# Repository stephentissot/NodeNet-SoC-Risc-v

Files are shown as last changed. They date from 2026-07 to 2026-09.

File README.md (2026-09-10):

# NodeNet SoC Risc-v — Colorlight i9 Multi-Node Embedded System

A complete RISC-V System-on-Chip (SoC) design for the Colorlight i9 FPGA board, featuring a PicoRV32 processor, Wishbone bus interconnect, persistent SPI flash storage, I2C peripherals, distributed RS485 multi-node communication via the NodeNet485 protocol, and a PLC runtime ready for relocatable object-file deployment.

## Overview

This project demonstrates a scalable embedded systems design on a cost-effective FPGA:
- **Processor**: PicoRV32 (32-bit RISC-V, bare-metal)
- **Clock**: 25 MHz
- **Memory**: 64 KiB ROM (stage0 bootloader) + 64 KiB RAM (stack/variables) + 8 MB SDRAM (runtime application/external data)
- **Peripherals**: D2 LED GPIO, RJ45 LED pulse controllers (`wb_led`), UART1 Modbus RTU master (`wb_modbus_master`), RS485 NodeNet485, I2C master, SDRAM controller
- **Communication**: NodeNet485 @ 1 Mb/s over RS-485 (multi-node capable)
- **Firmware**: C++17, bare-metal, newlib-nano
- **Validated boot path**: stage0 in ROM validates an image header in SPI flash, copies the payload to SDRAM, checks CRC, then jumps to the application entry point
- **Validated SDRAM path**: full firmware execution from SDRAM, 32-bit accesses, partial Wishbone writes, linker-placed `SDRAM_DATA` variables, and scratch-area self-tests

Current project status:
- **PLC Ready** with **V0 basic ISA**
- runtime point catalog with `pointDefsReq` / `pointStatesReq` browsing and pagination
- relocatable `objectFileV1` PLC upload, firmware-side link/load, linked-bytecode readback, and object-file readback
- 16 PLC slots with reboot persistence in the raw PLC flash package and automatic restore after boot
- OLED boot progress screen plus post-boot slot status screen
- ESP32 SPI coprocessor for local web API is in progress on the current branch; the shared SPI link, snapshot bootstrap, incremental state updates, and web UI runtime path are now working together on hardware, while broader validation and the MQTT bridge remain pending

## Features

### NodeNet PLC
- NodeNet PLC catalog browsing supports `pointDefsReq` and `pointStatesReq` with hierarchical paths of the form `deviceId.feature.pointId`.
- Point definitions can be created or updated with `pointUpsert`, and removed with `pointDelete`.
- Modbus-backed points are polled by the PLC runtime and exposed through the same NodeNet command surface.
- The PLC runtime publishes a shared SDRAM descriptor/value/status map, and PLC VM writes are consumed through the runtime write queue.
- Generic PLC deployment uses relocatable `objectFileV1` artifacts; the built-in `plcLoadReq` mirror helper remains available for fast validation.

PLC feature summary:
- Main feature status: PLC Ready with V0 basic ISA
- Runtime architecture: shared SDRAM PLC ABI, point runtime descriptors, value/status windows, slot loader/linker, persistent flash package restore at boot
- Deployment model: host builds relocatable `objectFileV1`, firmware links it against the live point catalog, loads it into one of 16 slots, and can persist the slot set for reboot restore
- Operating surface: NodeNet browse/update commands for point definitions and point states, PLC slot control/status points, raw PLC upload flow, linked-bytecode readback, and original object-file readback

PLC documentation index:
- Command surface and JSON examples: [README_NODENET_PLC_COMMANDS.md](README_NODENET_PLC_COMMANDS.md)
- PLC VM runtime architecture and ABI: [Documentation/plc_vm_spec_v1.md](Documentation/plc_vm_spec_v1.md)
- PLC assembly / object-file format: [Documentation/plc_assembly_spec_v1.md](Documentation/plc_assembly_spec_v1.md)
- ESP32 SPI bridge pinout and PlatformIO notes: [Documentation/esp32_spi_bridge_notes.md](Documentation/esp32_spi_bridge_notes.md)
- Firmware runtime and flash layout: [src/firmware/README.md](src/firmware/README.md)
- Stage0 boot flow and runtime handoff: [src/firmware/README_BOOT.md](src/firmware/README_BOOT.md)
- NodeNet transport details: [src/wbDevices/README_NODENET.md](src/wbDevices/README_NODENET.md)
- SPI flash persistence details: [src/wbDevices/README_FLASH.md](src/wbDevices/README_FLASH.md)
- Desktop PLC object-file tooling: [tools/BigSisterNodeNet.Plc/README.md](tools/BigSisterNodeNet.Plc/README.md)

### NodeNet Validation Snapshot (2026-08-20)
- Automatic heartbeat in HDL validated on hardware at ~10 s period.
- RX to local address validated (message accepted and decoded).
- TX path validated end-to-end.
- Runtime baud operation validated at both 115200 and 1 Mb/s.
- RX metadata is propagated end-to-end (`src`, `dst`, `broadcast`, `len`).
- Distinct PicoRV32 IRQs exist for broadcast vs unicast RX and are consumed through firmware callbacks.
- ROM stage0 now forwards the fixed IRQ vector at `0x00000004` to the SDRAM app IRQ entry.

### FlashDB Validation Snapshot (2026-08-13)
- Flash low-level test passes at boot (`[FLASH] LowLevel PASS`).
- FlashDB initialization passes (`[FDB] Ready`).
- Boot counter write path passes (`[FDB] boot cnt updated`).

### Hardware
- **Wishbone B.4 Bus** interconnect with 32-bit data, 32-bit address
- **PicoRV32 Core**: Open-source RISC-V ISA, ~6K LUT footprint
- **Memory Map**:
  - `0x00000000–0x0000FFFF`: 64 KiB boot ROM (stage0 bootloader)
  - `0x00010000–0x0001FFFF`: 64 KiB RAM (stack, BSS, heap)
  - `0x10000000`: D2 LED GPIO (1-bit output)
  - `0x10000004`: RJ45 LED0 (`wb_led` one-shot pulse)
  - `0x10000008`: RJ45 LED1 (`wb_led` one-shot pulse)
  - `0x10004000`: UART1 Modbus RTU master (`wb_modbus_master`)
  - `0x10005000`: I2C0 master (8 registers @ 4-byte stride)
  - `0x10006000`: NodeNet485 RS-485 mailbox (8 registers, 1 Mb/s)
  - `0x20000000–0x207FFFFF`: 8 MB SDRAM (runtime application image / framebuffer / logs)

### Peripherals
- **NodeNet485 Module** (`wb_nodenet.sv`):
  - Multi-node RS-485 communication protocol
  - Baud rate: runtime divisor (validated at 115200 and 1 Mb/s)
  - HDLC-style framing with parity bits and CRC
  - Mailbox-based Wishbone interface for TX/RX messages
  - Internal message buffering (no external SDRAM FIFO usage)
  - Anti-collision backoff (address-based delay)
  - Periodic heartbeat for node discovery
  - Priority-based transmission (LOW/NORMAL/HIGH)
  - Full C++ firmware API in `src/firmware/lib/nodenet/nodenet.h`
  - Supports unicast, broadcast, and heartbeat messages
  - Supports callback-driven broadcast / unicast reception on PicoRV32 IRQs
  - RX decode error reporting and TX scheduling status
  - Wishbone register interface (0x10006000)

- **I2C Module** (`wb_i2c.sv`):
  - Wraps Alex Forencich's `i2c_master_wbs_16` core
  - Hardware command + write + read FIFOs (32 entries each)
  - Configurable speed (default 100 kHz, up to 400 kHz @ 25 MHz)
  - Drives SCL/SDA open-drain (external 4.7 kΩ pullup required)
  - Wishbone address: 0x10005000

- **Modbus Master Module** (`src/modbus/wb_modbus_master.sv`):
  - Wishbone Modbus RTU master transaction engine
  - Uses shared `uart_simple.sv` UART core for wire-level TX/RX
  - Hardware-managed CRC16 (TX generation + RX validation)
  - Hardware-managed RTU frame gap detection (inter-frame silence)
  - Retries, timeout, and status/error flags exposed through MMIO
  - Firmware API in `src/firmware/lib/modbus/ModbusMaster.{h,cpp}`
  - Wishbone address: 0x10004000

- **SPI Flash Module** (`wb_flash.sv`, `spi_master.sv`):
  - Wishbone interface to on-board SPI flash (W25Q64, 8 MB)
  - Memory layout: 2 MB boot config (protected) + 12 KB point catalog + 4 KB compatibility gap + 128 KB PLC package + 124 KB FlashDB KV + 4 KB self-test scratch + app data
  - C++ firmware uses low-level page/sector API (`Flash`) plus FlashDB wrapper (`flashdb_port`)
  - Exposes the factory-programmed 64-bit Winbond UID as a stable ASCII device ID
  - Boot region protection: firmware rejects writes/erases to 0x000000–0x1FFFFF
  - Point catalog storage at 0x200000–0x202FFF (12 KB, 3 sectors)
  - Compatibility gap at 0x203000–0x203FFF (4 KB)
  - Persistent PLC package at 0x204000–0x223FFF (128 KB)
  - FlashDB KV partition at 0x224000–0x242FFF (124 KB)
  - Flash low-level self-test scratch at 0x243000–0x243FFF (4 KB)
  - Wishbone address: 0x10007000
  - See [src/wbDevices/README_FLASH.md](src/wbDevices/README_FLASH.md) for details
### Firmware
- **C++17 bare-metal** (`firmware/main.cpp`):
  - Compiled with `riscv-none-elf-g++` — no Arduino, no OS
  - `newlib-nano` provides `memcpy`/`strlen`/etc.
  - Dead code elimination (`-ffunction-sections -Wl,--gc-sections`)
  - Global C++ constructors called in `start.S` via `.init_array`
  - Final runtime image is linked for SDRAM via `link_app_sdram.ld`
  - Loaded by ROM-resident `boot_stage0` from SPI flash offset `0x244000`
  - Includes ArduinoJson 7 in freestanding mode, with an optional SDRAM-backed allocator for large JSON payloads
  - **NodeNet485 callback flow**: receives broadcast/unicast events through IRQ callbacks and defers heavy work to the main loop
  - D2 activity heartbeat: non-blocking software toggle every 500 ms

- **External SDRAM bring-up**:
  - Cold boot initialization now follows the generated LiteDRAM DFII sequence before the SDRAM user port is released
  - Firmware should still call `sdram_wait_ready()` before touching `SDRAM_DATA` objects or the JSON SDRAM pool

- See [src/firmware/README.md](src/firmware/README.md) for full peripheral usage guide.
- See [src/wbDevices/README_NODENET.md](src/wbDevices/README_NODENET.md) for protocol details.
- See [src/modbus/README.md](src/modbus/README.md) for Modbus RTU master details.
- See [src/wbDevices/README_FLASH.md](src/wbDevices/README_FLASH.md) for flash UID and device ID details.

## Building

### Prerequisites
- Yosys (synthesis)
- NextPNR (place & route)
- ecppack (bitstream generation)
- RISC-V GCC toolchain (`riscv-none-elf-gcc` ≥ 12, with C++ support)
- Make

> **After cloning**, fetch the u8g2 submodule:
> ```bash
> git submodule update --init
> ```

### Build Steps

```bash
# Full build (firmware + FPGA)
make all

# Stage0 bootloader only (ROM image)
make firmware-bootloader

# Alias: same stage0 ROM build as above
make firmware-build

# Build stage0 application image (SDRAM payload + header in SPI flash format)
make firmware-image

# SDRAM application ELF only
make -C src/firmware firmware-app-build

# Program firmware payload only in SPI flash (no FPGA rebuild)
make flash-fw

# If bootloader ROM startup / IRQ forwarding changed, reload the FPGA image too
make ram

# Optional: enforce openFPGALoader verify as fatal
make FW_STRICT_VERIFY=1 flash-fw

# Generate boot robustness test images (missing/size/crc fault injections)
make firmware-image-tests

# Run boot robustness fault scenarios
make flash-fw-test-missing
make flash-fw-test-crc
make flash-fw-test-size

# Firmware-only FPGA RAM update (ecpbram patch, fallback to make ram if needed)
make ram-fw

# Boot fault campaign checklist and expected blink codes
# See TEST.md

# FPGA synthesis only (requires pre-built firmware)
make

# Clean all artifacts
make clean

# Program FPGA SRAM (volatile)
make ram

# Program SPI flash (persistent, includes unlock during write)
make flash

# Manual flash protection control
make unlock-flash
make lock-flash
```

`make firmware-build` / `make firmware-bootloader` print stage0 ROM size telemetry on each build:
- ELF text/data/bss
- RAM usage (`.data + .bss`)
- HEX file size and payload bytes
- ROM usage (`payload / ROM_BYTES`, in %)

If payload exceeds ROM capacity, build stops with an explicit error.

CPU profile note:
- Default build is configured in fast mode for PicoRV32 in [src/top.sv](src/top.sv) with:
  - `.BARREL_SHIFTER(1)`
  - `.ENABLE_FAST_MUL(1)`
  - `.ENABLE_DIV(1)`
- To switch back to the normal/smaller CPU profile, set those three parameters to `0` in [src/top.sv](src/top.sv) and rebuild (`make clean; make`).

If OpenOCD flash programming fails on your setup, you can switch the flash
targets in `Makefile` to ecpdap. Reference commands:

```make
# ecpdap fallback examples (Colorlight i5/i9 style headers)
# flash:
# 	ecpdap flash unprotect
# 	ecpdap flash write build/top.config
#
# unlock-flash:
# 	ecpdap flash unprotect
#
# lock-flash:
# 	ecpdap flash protect
```

**Output**:
- `src/firmware/build/boot_stage0.hex` – Stage0 bootloader image (loaded into ROM, includes IRQ forward stub to the SDRAM app)
- `src/firmware/build/nodenet_riscv_app.img` – SDRAM app payload with stage0 header (written in SPI flash at `0x244000`)
- `build/top.bit` – FPGA bitstream (~300 KB)
- `build/top.json` – Netlist (debug/inspection)

## Memory Layout

```
Address Range               Size      Purpose
────────────────────────────────────────────────────────────
0x00000000–0x0000FFFF     64 KiB   Boot ROM (stage0 bootloader)
0x00010000–0x0001FFFF     64 KiB   RAM (stack, BSS, heap)
────────────────────────────────────────────────────────────
0x10000000                4 B      D2 LED GPIO (bit [0] = LED output)
0x10000004                4 B      RJ45 LED0 (`wb_led` control/status)
0x10000008                4 B      RJ45 LED1 (`wb_led` control/status)
0x10004000                32 B     UART1 Modbus RTU master (`wb_modbus_master`)
0x10005000                32 B     I2C0 master (8 regs @ 4-byte stride)
0x10006000–0x1000601F     32 B     NodeNet485 mailbox + LED config (RS485, 1 Mb/s)
0x10007000                32 B     SPI Flash controller (W25Q64)
────────────────────────────────────────────────────────────
0x20000000–0x207FFFFF     8 MB     SDRAM — Runtime app image + large buffers/logs
────────────────────────────────────────────────────────────
0x00000000–0x1FFFFF       2 MB     SPI Flash — FPGA boot config (PROTECTED)
0x200000-0x202FFF         12 KB    SPI Flash — Point catalog
0x203000-0x203FFF         4 KB     SPI Flash — Compatibility gap / reserved
0x204000-0x223FFF         128 KB   SPI Flash — Persistent PLC package
0x224000-0x242FFF         124 KB   SPI Flash — FlashDB KV partition
0x243000-0x243FFF         4 KB     SPI Flash — Flash low-level self-test scratch
0x244000–0x7FFFFF         5.73 MB  SPI Flash — Stage0 application image slot
```

## Boot Flow

1. FPGA configuration loads the SoC bitstream and the `wb_rom` contents containing `boot_stage0`.
2. Stage0 starts from `0x00000000`, initializes required peripherals, and reads the application header from SPI flash offset `0x244000`.
3. Stage0 validates header fields and CRCs, copies the application payload into SDRAM at `0x20000000`, then jumps to the image entry point.
4. PicoRV32 IRQ entry remains fixed at `0x00000004`; the ROM image forwards that vector to the SDRAM application IRQ entry at `0x20000004`.
5. The runtime firmware executes entirely from SDRAM, while SPI flash remains available for parameter storage, FlashDB, and firmware updates.
6. SDRAM self-tests used by the runtime stay inside a reserved scratch area so they do not overwrite the executing image.

## Device Pinout

### RS485 (NodeNet485 Protocol)
- **Pins**: G5 (RX), D16 (TX)
- **Baud Rate**: 1 Mb/s (fixed, configurable via UART parameter)
- **Protocol**: Multi-node RS-485 with HDLC framing, anti-collision, heartbeat
- **Transceiver**: Any RS-485 module with auto-switching (MAX485, SN65HVD11, etc.)
- **Multi-Node**: Up to 20 nodes on shared bus with address-based scheduling
- **Features**: Parity-encoded payload (2x expansion), XOR CRC, priority levels (LOW/NORMAL/HIGH), heartbeat
- **Connector topology**: 2x RJ45 in daisy-chain (IN/OUT), wired pin-to-pin between connectors

NodeNet RJ45 pinout (both connectors):

| RJ45 Pin | Signal |
|---|---|
| 1 | +12V |
| 2 | +12V |
| 3 | RS485 A |
| 4 | GND |
| 5 | GND |
| 6 | RS485 B |
| 7 | GND |
| 8 | GND |

### I2C (D18/D17 pins)
- **SCL**: D18
- **SDA**: D17
- Requires external 4.7 kΩ pullup resistors to 3.3 V on both lines
- Compatible with any I2C device: OLED, sensors, ADC, GPIO expanders…

### GPIO
- **D2 LED**: GPIO output at 0x10000000 (bit [0] = LED state)

### RJ45 LEDs (`wb_led`)
- **LED0 (F5)**: `0x10000004`
- **LED1 (E6)**: `0x10000008`
- Active-low wiring policy: GPIO high = LED OFF, GPIO low = LED ON.
- LPF enables pull-up on these pins for deterministic OFF level during startup.
- Write command bit0 triggers a non-blocking pulse (duration can be overridden by firmware).
- RJ45 LEDs are available through `wb_led` and can be used by application firmware when needed.

### NodeNet Activity LEDs (100% hardware)
- **RX activity LED (E5, green)**: default ON, pulses OFF when a valid frame is received.
- **TX activity LED (F4, orange)**: pulses ON when a transmission is queued.
- Active-low with pull-up: idle/high keeps LED OFF unless logic drives low.
- Blink duration is configured by firmware through NodeNet register `0x1000601C` (milliseconds).

### SPI Flash (W25Q64)
- **Pins**: R2 (CS), W2 (MOSI), V2 (MISO)
- **Clock**: Generated internally (10 MHz typical, no GPIO pin)
- **Capacity**: 8 MB (2 MB boot + 16 KB params + 256 KB FlashDB KV + ~5.73 MB app)
- **Boot Protection**: Firmware API rejects writes to 0x000000–0x1FFFFF
- **Parameter Region**: 0x200000–0x203FFF (raw/scratch area)
- **FlashDB KV Region**: 0x204000–0x243FFF (`nodenet_kv` partition)

## Firmware Examples

See **[src/firmware/README.md](src/firmware/README.md)** for a full guide with code examples for every peripheral.

### Quick-start: UART1 Modbus RTU master
```cpp
#include "ModbusMaster.h"

constexpr uint32_t MODBUS1_BASE = 0x10004000u;
constexpr uint8_t MODBUS_SLAVE = 0x01u;
ModbusMaster modbus1(MODBUS1_BASE);

int main() {
  modbus1.begin(9600, 500, 2);
  modbus1.setInterframeCharsQ1(14);

  uint16_t version = 0;
  if (modbus1.readHoldingRegisters(MODBUS_SLAVE, 0x8000, 1, &version)) {
    // 0x0064 => V1.00
  }

  for (;;) {
    // Toggle channel 1 (coil address 0)
    (void)modbus1.writeSingleCoil(MODBUS_SLAVE, 0x0000, true);
  }
}
```

### Quick-start: NodeNet echo
```cpp
#include <stdint.h>
#include "nodenet.h"

#define LED          (*(volatile uint32_t*)0x10000000)
constexpr uint32_t NODENET0_BASE = 0x10006000u;

int main() {
  NodeNet myNodeNet(NODENET0_BASE, 0x01, NODENET_PRIORITY_NORMAL, 200);
  for (;;) {
    if (myNodeNet.HasMessage()) {
      NodeNetMessage msg = myNodeNet.ReadMessage();
      if (msg.src_addr != 0) {
        myNodeNet.Send(msg.src_addr, msg.data, msg.len);
      }
      NodeNet::FreeMessage(msg);
    }
    LED ^= 1;
  }
}
```

### Quick-start: OLED via u8g2
```cpp
#include "u8g2_hal.h"

u8g2_t display;

int main() {
    u8g2_Setup_ssd1306_i2c_128x64_noname_f(
        &display, U8G2_R0,
        u8x8_byte_i2c_hw,
        u8x8_gpio_delay_hw);
    u8g2_InitDisplay(&display);
    u8g2_SetPowerSave(&display, 0);
    u8g2_ClearBuffer(&display);
    u8g2_SetFont(&display, u8g2_font_ncenB08_tr);
    u8g2_DrawStr(&display, 0, 12, "RISC-V SoC");
    u8g2_SendBuffer(&display);
    for (;;);
}
```

## Wishbone Bus Modules

See [src/wbDevices/README.md](src/wbDevices/README.md) for detailed documentation of each Wishbone peripheral module.

## Resource Usage

**Lattice LFE5U-45F-6BG381C** (Colorlight i9):
- Total LUTs: 45K
- Block RAM (DP16KD): 108 (each 16K bits)
- Current design:
  - PicoRV32: ~6K LUT
  - Interconnect: ~1K LUT
  - ROM (64 KiB): 32 blocks
  - RAM (64 KiB): 32 blocks
  - NodeNet485 transport + UART: ~300 LUT
  - SDRAM controller: ~400 LUT
  - GPIO: ~50 LUT
  - **Total: ~35% of available resources**

## Architecture

```
                   +----------------+
                   |   PicoRV32     |
                   +-------+--------+
                           |
                      Wishbone B4
                           |
      +--------+-----------+---------+--------+----------+-------+
      |        |           |         |        |          |       |
      wb_rom  wb_ram  wb_modbus_master  wb_nodenet wb_gpio wb_led wb_sdram wb_i2c
            |         |
            uart_simple  uart_simple
                 |
               NodeNet framing
        LED D2   RJ45 LEDs   M12L64322A  SSD1306   W25Q64
              |                    (8MB SDRAM) OLED
            RS485 Transceiver
                           |
                 Direct RS485 A/B/GND
                           |
                   Field Connectors
```

**Data Flow**:
1. **Power-up / stage0**: `wb_rom` exposes the 64 KiB ROM image containing `boot_stage0`, which loads and validates the SDRAM application stored in SPI flash.
2. **Runtime CPU** (PicoRV32): 32-bit RISC-V, 25 MHz clock, executing the main firmware from SDRAM after stage0 handoff.
3. **Wishbone B.4 Bus**: 32-bit address, 32-bit data, address decoder for memories and peripherals.
4. **Memory & I/O**:
  - `wb_rom`: 64 KiB boot ROM for stage0 only (0x00000000)
   - `wb_ram`: 64 KiB RAM (0x00010000)
  - `wb_sdram_litedram`: 8 MB SDRAM runtime memory window (0x20000000)
  - `wb_flash`: SPI flash control + persistence services (0x10007000)
  - `wb_modbus_master`: Modbus RTU master transport (0x10004000)
  - `wb_nodenet`: NodeNet485 mailbox transport (0x10006000)
  - `wb_gpio`: D2 GPIO output (0x10000000)
  - `wb_led`: RJ45 LED pulse controllers (0x10000004 / 0x10000008)
   - `wb_i2c`: I2C master with FIFOs (0x10005000)
5. **NodeNet Transport**: Mailbox-driven TX/RX framing, decode, and heartbeat scheduling.
6. **I2C Core**: Wraps Alex Forencich's `i2c_master_wbs_16` with Wishbone interface.
7. **RS485 Physical**: Transceiver converts CMOS <-> RS485 differential signaling.
8. **Field Wiring**: Each RS485 channel is exposed as direct A/B/GND connections.

## Planned Enhancements

- [x] 8 MB SDRAM controller (`wb_sdram_litedram.sv`) with LiteDRAM-generated core and runtime execution from SDRAM
- [x] I2C master (`wb_i2c.sv`) — Wishbone wrapper around verilog-i2c
- [x] u8g2 OLED display support (SSD1306 128×64 over I2C)
- [x] C++17 firmware with newlib-nano and dead-code elimination
- [x] SDRAM section in linker script (`sdram.h`, `SDRAM_DATA` macro)
- [ ] NodeNet485 mailbox transport with TX/RX framing and heartbeat (validation pending)
- [ ] UART1–4 implementation and testing
- [ ] RS485 direct connector mapping and labeling verification (A/B/GND)
- [ ] `wb_gpio` control bit for RS485 120R termination switch (74LVC1G66GW,125)
- [ ] Modbus V1 front-end: 4x RS485 modules with direct A/B/GND connectors per channel
- [ ] `wb_gpiopwm` peripheral + firmware API (PKLCS1212E4001-R1 buzzer)
- [ ] TMP117 board temperature sensor + firmware I2C driver/API
- [ ] Display validation: OLED over I2C and LCD over SPI (select final path after tests)
- [ ] Evaluate and select more robust 1 Mb/s transceivers for Modbus and NodeNet
- [ ] Dual Ethernet breakout using i9 onboard Broadcom PHYs (2x RJ45 with magnetics)
- [x] RJ45 LEDs integrated through `wb_led` at dedicated addresses
- [ ] Final RJ45 firmware policy (link/activity/status) for production runtime
- [ ] ESP32 module SPI coprocessor for web API and MQTT bridge (in progress: shared SPI link, HTTP app, websocket updates, and plcLink snapshot/resync path validated on hardware; MQTT bridge still pending)
- [ ] Power option study: use ESP32 module 3.3V rail vs dedicated 12V->3.3V buck
- [x] Modbus RTU master module + firmware driver (`wb_modbus_master` + `ModbusMaster`)
- [ ] Modbus RTU slave mode
- [ ] NodeNet JSON protocol wrapper (UART4)
- [ ] SPI slave interface for ESP32 co-processor
- [ ] SPI color LCD support (ST7789, 76x284) on Colorlight i9
- [ ] KNX integration with NCN5120 transceiver module
- [ ] Hardware-based CRC accelerator
- [ ] Real-time interrupt controller (RISC-V PLIC)

## Hardware Requirements

- **Colorlight i9 Board** with Lattice LFE5U-45F FPGA
- **USB-C Programmer** (e.g., openFPGALoader, oss-cad-suite)
- **RS485 Transceiver** modules (SN65HVD230, MAX483, etc.)
- **RS485 Field Connectors** (A/B/GND per channel)
- **SSD1306 OLED Module** (I2C, 128×32 or 128×64) + 4.7 kΩ pullup resistors

## Testing

```bash
# Program RAM (requires openFPGALoader)
make ram

# Program Flash (permanent)
make flash

# Explicit flash protection control (optional)
make unlock-flash
make lock-flash

# UART loopback test
# - Send "Hello" via USB-to-UART adapter
# - LED should blink
# - Characters echoed back
```

`make flash` now performs an explicit unlock step in the OpenOCD write command (`flash write_image erase unlock ...`) before erase/program.
`make lock-flash`/`make unlock-flash` call `flash protect ...` through OpenOCD; effectiveness/persistence depends on driver support for the target flash path.

## References

- [PicoRV32 GitHub](https://github.com/YosysHQ/picorv32)
- [Verilog UART IP (Alex Forencich)](https://github.com/alexforencich/verilog-uart) – Core UART module used in wb_uart.sv
- [Verilog I2C IP (Alex Forencich)](https://github.com/alexforencich/verilog-i2c) – Core I2C module used in wb_i2c.sv
- [u8g2 Graphics Library](https://github.com/olikraus/u8g2) – OLED display driver (git submodule)
- [Wishbone B.4 Specification](https://cdn.opencores.org/downloads/wbspec_b4.pdf)
- [LFE5U FPGA Datasheet](https://www.latticesemi.com/en/Products/FPGAs/ECP5)
- [RISC-V Unprivileged ISA Manual](https://riscv.org/specifications/)

## License

See [LICENSE](LICENSE) file.

## Author

**Stephen Tissot**  
Industrial IoT / FPGA Engineering  
https://github.com/stephentissot

---

**Status**: Prototype / Active Development  
**Last Updated**: 2026-08-18

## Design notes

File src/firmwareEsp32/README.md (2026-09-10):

# ESP32 Firmware

This directory contains the ESP32 sidecar firmware used for:

- web-based configuration
- MQTT publication
- Home Assistant discovery
- SPI transport toward the FPGA mailbox bridge

## Selected Stack

- IDE: VS Code
- build system: PlatformIO
- framework: ESP-IDF
- board id: `wemos_d1_mini32`

## Web Transport Policy

- current target: stay on `HTTP` with the current `wemos_d1_mini32` hardware
- reason: this keeps RAM risk lower while the main runtime, UI, and web application bricks are still being integrated
- planned evolution: if the project later moves to an `ESP32-S3 N16R8`, the intended next step is to keep the setup portal on `HTTP` and move the main web application only to `HTTPS`
- certificate direction for that future `HTTPS` app path: allow uploading a server certificate and private key rather than hard-coding a single certificate into the firmware
- decision gate: continue advancing the application on the current board first, then re-evaluate the `ESP32-S3 N16R8` migration once the main features are in place

## Current Scope

The current branch now brings up:

- boot logging on UART
- ST7789 bring-up through a direct ESP-IDF SPI driver using the validated panel wiring and init sequence
- a one-shot ST7789 full-screen red / green / blue test at boot
- FPGA SPI-link initialization on the same shared SPI bus
- HTTP web application served locally by the ESP32
- websocket push path for boot progress, snapshot availability, and incremental PLC point updates
- plcLink bootstrapping with `get_caps`, definitions snapshot, states snapshot, and runtime state-update handling on hardware

## Current Status Snapshot

- current baseline is usable enough to pause and resume later: the ESP32 app can connect to the FPGA mailbox bridge, load the PLC snapshot, keep the page stable during runtime state-only resyncs, and apply incremental point updates without replaying the whole snapshot over websocket
- the shared SPI bus is validated with the display at `10 MHz` and the FPGA mailbox link at `1 MHz`
- definitions are preserved across state-only runtime resyncs when `defs_generation` is unchanged
- the web application no longer treats a runtime state resync as a cold boot reload
- completed state snapshots no longer emit one websocket `plc_point_update` per cached point
- MQTT publication and Home Assistant discovery are still not implemented on this baseline

## Known Resume Points

- continue hardware/runtime validation of plcLink under heavier PLC state churn; the recent work stabilized the ESP32 side, but more soak testing is still needed
- the remaining protocol risk is on the Pico/FPGA producer side when the PLC VM generates many closely spaced state changes
- if runtime resync behavior regresses, inspect `src/spi_link.cpp`, `www/app/main.js`, `src/firmware/lib/spi_mailbox/plclink_mailbox_service.cpp`, and `src/firmware/lib/plc/PointCatalog.cpp` first
- MQTT bridge, Home Assistant discovery, and any HTTPS migration are future steps, not part of the currently validated baseline

## Display Driver

- implementation: local ESP-IDF SPI driver in `src/display_st7789.cpp`
- panel model: `ST7789`
- current bring-up test: one-shot full-screen red / green / blue fills at boot
- note: the init sequence remains aligned with the working `76x284` ST7789 bring-up that was validated during the Arduino reference phase
- bus speed: `10 MHz` for the display device on the shared bus

## UI Library Direction

- recommended library: `LVGL`
- reason: it fits the current pure `ESP-IDF` stack well and expects exactly the kind of flush callback that `display_st7789.cpp` can provide
- keep the current ST7789 driver as the low-level panel backend; do not replace it with a framework-specific display wrapper
- avoid `TFT_eSPI` here: it is more display-driver oriented than UI-oriented and would pull the project back toward the Arduino path we intentionally removed
- next integration step: add a small `lvgl_port` that allocates one or two partial RGB565 draw buffers and forwards `flush_cb` rectangles into `display_st7789::blit_rgb565()`

## Shared SPI Bus

- bus init: shared once through `src/spi_bus_shared.cpp`
- display device: `GPIO5` chip select, SPI mode `3`, `10 MHz`
- FPGA device: `GPIO27` chip select, SPI mode `0`, `1 MHz`
- note: the ESP32 can switch speed per SPI device even when `SCK/MOSI/MISO` are physically shared

## Expected Commands

From this directory:

```powershell
pio run
pio run -t upload
pio device monitor
```

## Wiring Summary

- Shared SPI bus
	- `GPIO18` -> FPGA `J16` and ST7789 `SCL` for `SCK`
	- `GPIO23` -> FPGA `J18` and ST7789 `SDA` for `MOSI`
- FPGA link
	- `GPIO19` <- FPGA `P16` for `MISO`
	- `GPIO27` -> FPGA `N4` for `CS`
	- `GPIO32` <- FPGA `M3` for `IRQ`
- ST7789 control
	- `GPIO5` -> ST7789 `CS`
	- `GPIO16` -> ST7789 `DC`
	- `GPIO17` -> ST7789 `RST`
	- `BL` tied to `GND` and not software-controlled
- Reserved sideband
	- `GPIO33` <-> FPGA `T3` kept reserved for a future FPGA sideband signal

`GPIO33` is a good candidate for a future display `TE` input if you dedicate it to the display.
Do not share that same wire between the FPGA reserved sideband and the display reset or tearing signal.

The current bring-up build is now back on pure ESP-IDF with the FPGA link reattached on the shared SPI bus, and the FPGA mailbox transaction path is working on hardware for snapshot load plus runtime updates.
The next step is broader validation on this baseline, then raising the FPGA-side SPI speed if the slave logic and signal integrity allow it.

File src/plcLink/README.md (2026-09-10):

# plcLink Protocol Specification

This directory defines the future binary application protocol shared between the
PicoRV32 firmware and the ESP32 firmware.

The primary goal is to move point definitions and point states efficiently
between both firmwares with minimal CPU cost on the PicoRV32 side, while keeping
the architecture transport-independent so the same payloads can later travel
over NodeNet as well as SPI.

## Goals

- keep the high-frequency state path binary and compact
- avoid JSON on the local ESP32 <-> FPGA <-> PicoRV32 link
- minimize PicoRV32 work for frequent state propagation
- support full snapshot and incremental update flows for both definitions and states
- support ESP32-initiated writes for both definitions and states
- keep the protocol independent from the underlying transport
- preserve the option to reuse the same protocol payload over NodeNet in V2
- avoid forcing large RTL growth in the first implementation

## Non-Goals

- this protocol does not expose raw SPI mailbox details to application code
- this protocol does not reuse internal firmware structs as wire format by memcpy
- this protocol does not require JSON parsing on the transport path
- this protocol does not require direct SDRAM master access from `wb_spi_slave`
- this protocol does not require NodeNet framing in V1

## High-Level Architecture

The architecture is split into three layers.

### 1. Application Protocol Layer

This layer defines message types and binary payload formats only.

It must not depend on:

- SPI chip select or mailbox semantics
- NodeNet frame semantics
- JSON
- transport MTU details

This layer is shared by both firmwares.

### 2. Session and Fragmentation Layer

This layer adds:

- protocol version
- message type
- request and response correlation
- sequence numbers
- fragmentation and reassembly
- snapshot generation tracking
- update stream sequencing
- retry and resync rules

This layer is also shared by both firmwares.

### 3. Transport Adapter Layer

This layer moves opaque protocol fragments over a specific transport.

Planned transport adapters:

- V1: SPI mailbox transport through `wb_spi_slave`
- V2: NodeNet transport carrying the same protocol payload

The transport adapter is responsible only for moving bytes and reporting
delivery status. It must not reinterpret protocol payload content.

## Design Rules

- the protocol payload must be transport-independent
- message encoding must be explicit and versioned
- all multi-byte wire fields must use fixed endianness
- the protocol must tolerate fragmentation because the current SPI mailbox is small
- the protocol must support resynchronization after lost updates or overflow
- high-frequency state traffic must use incremental updates rather than repeated full snapshots
- string payloads must be handled carefully and not inflate the hot path unnecessarily

## Transport Independence Rule

This is the most important rule for the directory.

The same logical plcLink message must be serializable once and then carried by:

- a SPI mailbox exchange in V1
- a NodeNet frame payload in V2

That means the codec in this directory must define a protocol envelope and
message payloads that do not depend on mailbox registers, SPI opcodes, or
NodeNet headers.

## Shared Library Scope

This directory is intended to host the common protocol library used by both
firmwares.

Expected responsibilities:

- protocol enums
- packed wire headers
- encode helpers
- decode helpers
- bounds validation helpers
- fragmentation helpers
- checksum helpers if enabled
- common error codes

Expected non-responsibilities:

- direct SPI transactions
- direct NodeNet send and receive APIs
- hardware register access
- JSON model conversion

## Recommended Directory Contents

Suggested future files in this directory:

- `protocol_types.h`
- `protocol_codec.h`
- `protocol_codec.cpp`
- `protocol_fragmentation.h`
- `protocol_fragmentation.cpp`
- `protocol_defs.h`
- `protocol_states.h`
- `transport_interface.h`

The exact split can change, but the protocol layer must remain reusable from
both firmware projects.

## Protocol Envelope

Each logical plcLink message should begin with a small transport-independent
header.

Frozen V1 envelope fields:

- `magic_u16`
- `version_u8`
- `msg_type_u8`
- `flags_u8`
- `request_id_u8`
- `fragment_index_u8`
- `fragment_count_u8`
- `payload_length_u16`
- `generation_u32`
- `sequence_u32`

Notes:

- `generation` is used for snapshot families such as point definitions
- `sequence` is used for ordered update streams such as state updates
- `fragment_count` allows one logical message to be split over multiple transport units
- `request_id` correlates request and response pairs without relying on transport state

### Frozen V1 Header Layout

All fields are little-endian.

```text
offset  size  field
0x00    2     magic_u16
0x02    1     version_u8
0x03    1     msg_type_u8
0x04    1     flags_u8
0x05    1     request_id_u8
0x06    1     fragment_index_u8
0x07    1     fragment_count_u8
0x08    2     payload_length_u16
0x0A    4     generation_u32
0x0E    4     sequence_u32
```

Frozen V1 constants:

- `magic_u16 = 0x4C50` which corresponds to `PL` in little-endian storage
- `version_u8 = 1`
- `header_size = 18` bytes
- `fragment_index_u8` is zero-based
- `fragment_count_u8` must be at least `1`
- `payload_length_u16` is the payload bytes carried by the current fragment only

Frozen V1 flag bits:

- bit `0`: request
- bit `1`: response
- bit `2`: ack_required
- bit `3`: more_fragments_follow
- bit `4`: error_payload
- bit `5`: resync_required
- bit `6`: snapshot_payload
- bit `7`: update_payload

Validation rules:

- exactly one of `request` or `response` must be set
- `fragment_index < fragment_count`
- `fragment_count == 1` implies `fragment_index == 0`
- `more_fragments_follow` must be set on all fragments except the last one
- `generation_u32` is meaningful for definition snapshots and definition updates
- `sequence_u32` is meaningful for state snapshots, state updates, and write acknowledgments

## Message Families

The protocol supports four read families and two write families.

### Frozen V1 Message Types

The first assigned `msg_type_u8` values are:

| Value | Name | Direction | Purpose |
| --- | --- | --- | --- |
| `0x01` | `get_caps_req` | requester -> responder | Read protocol and transport capabilities |
| `0x02` | `get_caps_res` | responder -> requester | Return protocol and transport capabilities |
| `0x10` | `get_defs_snapshot_req` | requester -> responder | Request a definition snapshot chunk |
| `0x11` | `defs_snapshot_res` | responder -> requester | Return one definition snapshot chunk |
| `0x12` | `get_defs_updates_req` | requester -> responder | Request pending definition updates |
| `0x13` | `defs_updates_res` | responder -> requester | Return pending definition updates |
| `0x20` | `get_states_snapshot_req` | requester -> responder | Request a state snapshot chunk |
| `0x21` | `states_snapshot_res` | responder -> requester | Return one state snapshot chunk |
| `0x22` | `get_states_updates_req` | requester -> responder | Request pending state updates |
| `0x23` | `states_updates_res` | responder -> requester | Return pending state updates |
| `0x30` | `write_def_req` | requester -> responder | Upsert or delete a point definition |
| `0x31` | `write_def_res` | responder -> requester | Acknowledge a point definition write |
| `0x32` | `write_state_req` | requester -> responder | Write a point state or command value |
| `0x33` | `write_state_res` | responder -> requester | Acknowledge a point state write |
| `0x7E` | `ack` | either direction | Generic protocol acknowledgment |
| `0x7F` | `error` | either direction | Protocol-level error response |

Reserved ranges:

- `0x40` to `0x5F` reserved for future string or blob fetch helpers
- `0x60` to `0x6F` reserved for future event-stream flow control
- `0x70` to `0x7D` reserved for future transport-neutral utility messages

### Read Families

- `defs_snapshot`
- `states_snapshot`
- `defs_updates`
- `states_updates`

### Write Families

- `write_def`
- `write_state`

### Utility Families

- `get_caps`
- `ack`
- `error`
- `resync_required`

## Capability Exchange

The ESP32 should begin by reading capabilities.

Suggested `get_caps` response fields:

- protocol version
- maximum fragment payload size for this transport
- supported message families
- current `defs_generation`
- current `states_sequence`
- point count
- flags for string support and write support

This allows the ESP32 to decide whether it can:

- continue from updates only
- request a new snapshot
- enable optional message types

Frozen V1 capability payload fields:

- `protocol_version_u8`
- `capability_flags_u16`
- `max_fragment_payload_u16`
- `point_count_u16`
- `defs_generation_u32`
- `states_sequence_u32`

Frozen V1 capability flags:

- bit `0`: supports definitions snapshot
- bit `1`: supports definitions updates
- bit `2`: supports states snapshot
- bit `3`: supports states updates
- bit `4`: supports definition writes
- bit `5`: supports state writes
- bit `6`: supports string fetch helper
- bit `7`: reserved for future NodeNet transport capability advertisement

## Definitions Snapshot Flow

Definitions change relatively rarely, so a snapshot path is acceptable even if
it costs some CPU time.

The definitions snapshot flow should support:

- full snapshot generation on PicoRV32
- chunked transfer to handle small transport payloads
- deterministic `defs_generation`
- later replay by ESP32 into its local cache

Recommended request pattern:

- `get_defs_snapshot` with `generation` or `resume_offset`
- response chunks until snapshot complete

Recommended response metadata:

- `defs_generation`
- total serialized bytes
- total point count
- current chunk byte offset
- current chunk byte count
- `more` flag

Frozen V1 request fields:

- `resume_offset_u32`
- `max_chunk_payload_u16`
- `requested_generation_u32`

Frozen V1 response metadata:

- `defs_generation_u32`
- `total_serialized_bytes_u32`
- `total_point_count_u16`
- `chunk_offset_u32`
- `chunk_payload_bytes_u16`
- `more_u8`

## Definitions Update Flow

Definitions also need an incremental update path.

Supported logical operations:

- `def_upsert`
- `def_delete`
- `defs_reset`

Each incremental update must carry enough information for the ESP32 to update
its local definition cache without forcing an immediate full snapshot.

If the incremental queue overflows or ordering is lost, the producer must emit a
`resync_required` indication and the ESP32 must request a new definitions snapshot.

## States Snapshot Flow

States need an initial snapshot path for boot, reconnect, or overflow recovery.

The state snapshot flow should support:

- range-based reads by point index
- chunking by record count or encoded byte size
- deterministic `states_sequence` at snapshot start
- explicit metadata describing whether more records remain

Recommended request pattern:

- `get_states_snapshot` with `start_index` and `max_records`

Recommended response metadata:

- `states_sequence_base`
- total point count
- returned start index
- returned record count
- `more` flag

Frozen V1 request fields:

- `start_index_u16`
- `max_records_u16`
- `include_strings_u8`
- `reserved_u8`

Frozen V1 response metadata:

- `states_sequence_base_u32`
- `total_point_count_u16`
- `returned_start_index_u16`
- `returned_record_count_u16`
- `more_u8`

## States Update Flow

This is the hot path and must be the most efficient path in the protocol.

Rules:

- state updates must be binary and compact
- state updates must be incremental
- the producer should emit updates when state changes happen, not because the ESP32 polls
- the ESP32 may poll the transport frequently, but PicoRV32 work must stay proportional to actual changes

Preferred producer model:

- firmware-originated state changes append a state update record immediately
- future hardware-originated producers may also append records without changing the protocol

If the update queue overflows:

- set an overflow indicator
- stop claiming continuity of the update stream
- require the ESP32 to request a fresh state snapshot

## State Record Strategy

Do not use raw `PointState` memory as the wire record.

Internal `PointState` storage is useful as a data source, but the wire format
should be compact and stable.

Suggested compact state update record fields:

- `point_index_u16`
- `value_type_u8`
- `flags_u8`
- `value_bits_u32`
- `quality_u32`
- `timestamp_u32`

This supports the common scalar hot path while staying compact.

Frozen V1 compact state record layout:

```text
offset  size  field
0x00    2     point_index_u16
0x02    1     value_type_u8
0x03    1     state_flags_u8
0x04    4     value_bits_u32
0x08    4     quality_u32
0x0C    4     timestamp_ms_u32
```

Frozen V1 state record size:

- `16` bytes for non-string records

Frozen V1 state flags:

- bit `0`: value present
- bit `1`: string changed
- bit `2`: command-related update
- bit `3`: synthetic state
- bit `4`: write acknowledgment source
- bit `5` to bit `7`: reserved

### String States

String state data must not bloat the frequent update path.

Recommended behavior:

- regular state update carries a `string_changed` flag only
- ESP32 issues a targeted string read when needed
- string snapshots may include string payloads only in the snapshot path

## Definition Record Strategy

Do not send a raw `PointDefinition` struct over the wire.

Reasons:

- it contains pointers such as `enum_def`
- it contains internal representation details that are not a stable wire contract
- it is larger than needed for transport

Definitions must be encoded into a wire-specific record format.

Recommended definition record content:

- `point_index`
- `device_id`
- `feature`
- `point_id`
- `display_name`
- `backend`
- `direction`
- `value_type`
- `string_capacity`
- `scale`
- `unit`
- backend-specific parameters only when needed

If snapshot size becomes significant, the format may evolve to use string tables
and string indices instead of full strings in every record.

## ESP32-Initiated Writes

The protocol must support writes initiated by the ESP32.

### State Writes

Supported intents:

- write output value
- write command value
- acknowledge or clear pending command state if required later

Required request fields:

- `point_index`
- `expected_value_type`
- value payload
- optional mode flags

Required response fields:

- `ok`
- error code if rejected
- resulting sequence or acknowledgment token

Frozen V1 state write request fields:

- `point_index_u16`
- `expected_value_type_u8`
- `write_flags_u8`
- `value_bits_u32`
- optional trailing string payload only when `expected_value_type` is string

Frozen V1 state write response fields:

- `status_code_u8`
- `applied_value_type_u8`
- `reserved_u16`
- `result_sequence_u32`

### Definition Writes

Supported intents:

- upsert definition
- delete definition

Definition writes remain firmware-owned logic on the PicoRV32 side.

The ESP32 must not modify raw definition storage directly. The PicoRV32 remains
the authority that validates and applies catalog mutations.

After a successful definition write:

- `defs_generation` changes
- a corresponding definition update event may be emitted
- the ESP32 updates its cache or requests a fresh snapshot if needed

## Snapshot and Update Coexistence

The protocol intentionally provides both snapshot and incremental update paths.

Required model:

- snapshots establish a consistent baseline
- updates advance that baseline
- overflow or desynchronization forces a new snapshot

This applies independently to:

- point definitions
- point states

Definitions and states must therefore track separate continuity metadata.

Recommended counters:

- `defs_generation`
- `states_sequence`

## Performance Guidance

To preserve PicoRV32 responsiveness and avoid disturbing Modbus timing and PLC
execution, the implementation should follow these priorities.

### Highest Priority

- make `states_updates` the main frequent path
- avoid repeated full state scans driven only by ESP32 polling
- avoid JSON generation on the local link
- avoid repeated string work for unchanged string points

### Acceptable Rare Work

- building a full definitions snapshot
- building a full states snapshot after reconnect or overflow
- applying definition writes

### V1 Preferred Tradeoff

In V1, it is acceptable that PicoRV32 prepares responses for snapshots and
updates through the existing mailbox path, provided the hot path remains compact
and incremental.

## RTL Impact Guidance

The protocol in this directory must not assume any specific hardware optimization.

V1 should work with:

- the current mailbox-based `wb_spi_slave`
- low SPI clock
- PicoRV32-owned response generation

Future optimizations may add:

- a hardware-assisted state update FIFO
- a more direct producer path for PLC-originated state changes
- an alternate NodeNet transport adapter

These changes must not require redesigning the payload format defined here.

## Virtual and Synthetic State Caveat

Some exposed states may be computed or synthesized rather than copied directly
from the normal shared state array.

The protocol therefore distinguishes:

- wire format
- internal storage source

This keeps room for firmware to synthesize specific records when required while
still presenting the same protocol shape to the ESP32.

## Error Handling

The protocol should define explicit errors for at least:

- unsupported version
- unknown message type
- malformed payload
- type mismatch
- out-of-range point index
- write rejected
- queue overflow
- resync required

Errors must be protocol-level values, not transport-specific status codes.

Frozen V1 error codes:

- `0x00`: `ok`
- `0x01`: `unsupported_version`
- `0x02`: `unknown_message_type`
- `0x03`: `malformed_payload`
- `0x04`: `fragment_out_of_range`
- `0x05`: `type_mismatch`
- `0x06`: `point_index_out_of_range`
- `0x07`: `write_rejected`
- `0x08`: `queue_overflow`
- `0x09`: `resync_required`
- `0x0A`: `busy_retry_later`

## Versioning Policy

The protocol must be versioned from the start.

Rules:

- changing field meaning requires a protocol version bump
- adding optional message types may be feature-flagged through capabilities
- transport changes alone must not require a protocol version bump if the wire payload is unchanged

## V1 Implementation Direction

The preferred first implementation direction is:

- common binary codec in this directory
- SPI mailbox transport adapter on each side
- support for `get_caps`
- support for `defs_snapshot`
- support for `states_snapshot`
- support for `states_updates`
- support for basic `write_state`

`defs_updates` and `write_def` can follow once the snapshot and state fast path
are stable.

## Immediate File Set

The first shared files created in this directory are expected to freeze:

- protocol constants and enums
- packed header layout
- state and definition message record layouts
- fragmentation helpers
- codec helpers for header encode and decode

Transport-specific code must remain outside this directory.

## V2 Transport Direction

The long-term V2 direction is to allow the same plcLink payload to be carried by
NodeNet without breaking the internal architecture.

That requires preserving this rule:

- protocol payload definitions live in `src/plcLink`
- transport-specific framing lives outside `src/plcLink`

If this rule is respected, moving from SPI-only to SPI plus NodeNet later is an
adapter addition rather than a protocol rewrite.

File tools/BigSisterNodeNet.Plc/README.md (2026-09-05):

# BigSisterNodeNet.Plc .NET Framework 4.8.1

This library provides the PLC object-file tooling used by the desktop-side NodeNet Core.

Current project status: **PLC Ready** with relocatable `objectFileV1` deployment and stage-11 typed scalar extensions.

It covers three things:

- translate a machine-code string into PLC bytecode
- disassemble PLC bytecode or `objectFileV1` payloads back to readable assembly
- prepare a PLC deployment artifact for firmware upload
- build upload requests and binary frames for the Core-managed transport layer

Documentation note:

- this library now emits the real `objectFileV1` artifact
- firmware links point paths to runtime indices when the slot is loaded
- `PARAM POINT_ID` bindings are supplied to the builder through
    `PlcObjectFileOptions.PointBindings`

## Machine-code syntax

The syntax is intentionally narrow and matches the current firmware bytecode contract,
but operands are symbolic point names rather than literal runtime indices.

Supported declarations:

- `CONST POINT_ID <symbol>, <deviceId.feature.pointId>`
- `PARAM POINT_ID <symbol>`
- `VAR <type> <name>`

Reserved slot-runtime names that cannot be used in `VAR` declarations:

- `loaded`
- `state`
- `runEnabled`
- `status`
- `cycleCounter`
- `faultCode`
- `faultInfo`
- `bytecodeSize`
- `source`
- `programType`
- `paramsSummary`
- `inputChannel`
- `outputChannel`
- `runtimeMapOk`
- `start`
- `stop`
- `reset`
- `clearFault`

Supported instructions:

- `NOP`
- `HALT`
- `PUSH_TRUE`
- `PUSH_FALSE`
- `DUP`
- `DROP`
- `SWAP`
- `LOAD_BOOL <symbol>`
- `STORE_BOOL <symbol>`
- `LOAD_I16 <symbol>`
- `STORE_I16 <symbol>`
- `PUSH_I16 imm16`
- `LOAD_U32 <symbol>`
- `STORE_U32 <symbol>`
- `PUSH_U32 imm32`
- `LOAD_I32 <symbol>`
- `STORE_I32 <symbol>`
- `PUSH_I32 imm32`
- `LOAD_F32 <symbol>`
- `STORE_F32 <symbol>`
- `PUSH_F32 imm32`
- `AND`
- `OR`
- `XOR`
- `NOT`
- `EQ`
- `NE`
- `ADD`
- `SUB`
- `LT`
- `LE`
- `GT`
- `GE`
- `MIN`
- `MAX`
- `CLAMP`
- `SEL`
- `FEQ`
- `FNE`
- `FLT`
- `FLE`
- `FGT`
- `FGE`
- `FADD`
- `FSUB`
- `FMUL`
- `FDIV`
- `SX_I16_TO_I32`
- `TRUNC_I32_TO_I16`
- `BOOL_TO_U32`
- `BOOL_TO_I32`
- `U32_TO_BOOL`
- `I32_TO_BOOL`
- `INC_INT <symbol>`
- `DEC_INT <symbol>`
- `DB <byte0>, <byte1>, ...`

Current float scope:

- `PUSH_F32`, `LOAD_F32`, `STORE_F32`, ordered comparisons, `FADD`, `FSUB`, `FMUL`, and `FDIV` are implemented
- int/float numeric conversions remain deferred

Supported aliases:

- `LOAD_POINT_BOOL`
- `STORE_POINT_BOOL`
- `LB`
- `SB`
- `INC`
- `DEC`

Point operands reference the symbol names declared earlier in the same source.

Example:

```text
PARAM POINT_ID input
CONST POINT_ID y, gb9fao5yk4f.modbus0.waveshare8ch.output4
VAR INT counter

LOAD_BOOL input
STORE_BOOL y
INC_INT counter
HALT
```

Generated object model:

```text
code bytes with placeholder operands
+ symbol table containing point symbols and slot-local vars
+ relocation table patching symbolic operands to runtime indices
```

Disassembly helpers:

- `PlcMachineCodeDisassembler.DisassembleBytecode(...)`
- `PlcMachineCodeDisassembler.DisassembleObjectFile(...)`

## Example usage

```csharp
using BigSisterNodeNet.Plc;

var source = @"
PARAM POINT_ID input
CONST POINT_ID y, gb9fao5yk4f.modbus0.waveshare8ch.output4

LOAD_BOOL input
STORE_BOOL y
HALT
";

var objectBytes = PlcObjectFileBuilder.BuildFromMachineCode(source, new PlcObjectFileOptions
{
    RuntimeHeaderAddress = 0x20100000,
    MaxInstructionsPerScan = 32,
    MaxScanTimeUs = 5000,
    PointBindings = new Dictionary<string, string>
    {
        ["input"] = "gb9fao5yk4f.modbus0.waveshare8ch.input1",
    },
});

var uploader = new PlcUploadClient();
var beginRequest = uploader.CreateBeginRequest(objectBytes, new PlcUploadOptions
{
    RemoteAddress = 4,
    SlotId = 0,
    ResponseTimeout = TimeSpan.FromSeconds(5),
    PersistToFlash = true,
    AutoLoad = true,
});

var frame0 = uploader.BuildDataFrame(uploadId: 1, offset: 0, payloadSource: objectBytes, payloadOffset: 0, payloadCount: Math.Min(256, objectBytes.Length));
```

## Important limits in V1

- The stable firmware-side upload flow should accept `objectFileV1` artifacts.
- The canonical durable artifact is relocatable and linked by firmware at slot
    load time.
- Reboot persistence is handled through the raw PLC flash package restored by firmware at startup.
- `PARAM POINT_ID` values are full point paths supplied through
    `PlcObjectFileOptions.PointBindings`.
- The upload uses binary pages of up to `256` bytes.
- Current point-parameter bindings are baked into the uploaded object file for
    that program instance.

## Transport assumption

The repo documents desktop transport as raw JSON plus binary upload frames exchanged over the NodeNet master bridge.

This library therefore:

- builds JSON command payloads for the begin/commit upload phases
- builds JSON command payloads for linked-bytecode readback from a loaded slot
- builds JSON command payloads for true `objectFileV1` readback from a loaded slot
- builds raw binary PLC upload frames matching the firmware `plcUploadDataRes` flow
- leaves the actual transport, session ownership, and response handling to `BigSisterNodeNet.Core`

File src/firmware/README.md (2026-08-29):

# Firmware — RISC-V C++17 Bare-Metal

Firmware for the Colorlight i9 RISC-V SoC. Written in C++17, compiled with `riscv-none-elf-g++`, no operating system, no Arduino.

## Build System

```bash
# From the project root
make firmware-build       # stage0 bootloader (same as firmware-bootloader)
make firmware-bootloader  # explicit stage0 bootloader target
make firmware-image       # package SDRAM payload with stage0 header
make flash-fw             # program application image at 0x244000 in SPI flash
make all                  # firmware + FPGA bitstream
make clean                # remove all build artifacts

# From src/firmware
make firmware-app-build   # SDRAM application ELF only
```

`make firmware-build` also prints a compact size report:
- ELF text/data/bss bytes
- RAM usage (`.data + .bss`) and percentage
- HEX file size and payload bytes
- ROM usage (`payload / ROM_CAPACITY_BYTES`) and percentage

The build fails if HEX payload exceeds configured ROM capacity.

## PLC Runtime Status

The current firmware is PLC ready and exposes a relocatable `objectFileV1`
deployment path.

Current runtime scope:

- V0 basic ISA is implemented end to end
- firmware publishes the PLC runtime descriptor/value/status map in SDRAM
- generic host-side deployment uses `objectFileV1` upload + firmware-side link/load
- linked bytecode and original object file can both be read back over NodeNet
- persisted PLC packages are restored automatically during boot after the runtime map is published

Current V0 basic ISA instructions:

- `HALT`
- `LOAD_BOOL <symbol>`
- `STORE_BOOL <symbol>`
- `INC_INT <symbol>`
- `DEC_INT <symbol>`
- `DB <byte0>, <byte1>, ...`

Current object-file declarations:

- `CONST POINT_ID <symbol>, <deviceId.feature.pointId>`
- `PARAM POINT_ID <symbol>`
- `VAR <type> <name>`

The built-in mirror package flow remains available as a convenience tool for
quick validation and slot bring-up.

From the project root:

```bash
make plc-mirror-package \
    PLC_MIRROR_PAIRS=0:1 \
    PLC_PACKAGE_STORE_EPOCH=1

make plc-package-check
make flash-plc-package
```

`PLC_MIRROR_PAIRS` is a comma-separated list of `input_runtime_index:output_runtime_index`
pairs. The generated package is written to `src/firmware/build/plc_linked_package.img`
by default and is intended as a convenience artifact for the built-in mirror program,
not as the primary generic PLC deployment contract.

If you want to call the tool directly:

```bash
python src/firmware/tools/pack_plc_mirror_program.py \
    --pair 0:1 \
    --output src/firmware/build/plc_linked_package.img \
    --store-epoch 1
```

Use the current ABI `store_epoch` published by the firmware when packaging, or
the loader will reject the package as stale.

After cloning, fetch the u8g2 submodule first:
```bash
git submodule update --init
```

### Toolchain flags
| Flag | Purpose |
|---|---|
| `-std=c++17` | C++17 language standard |
| `-Os` | Optimize for size |
| `-ffreestanding` | No standard library assumptions |
| `-ffunction-sections -fdata-sections` | Enable per-function dead code elimination |
| `-Wl,--gc-sections` | Linker removes unused functions/data (critical for u8g2) |
| `-nostartfiles` | Don't use toolchain crt0 (we have `start.S`) |
| `--specs=nano.specs` | newlib-nano: provides `memcpy`, `strlen`, `memset`, etc. |
| `--specs=nosys.specs` | Stub syscalls (`_write`, `_sbrk`, …) for bare-metal |
| `-fno-exceptions -fno-rtti` | No C++ exception/RTTI overhead |

### File Structure

```
src/firmware/
├── start.S              SDRAM application startup: gp/sp init + .data/.bss + .init_array + call main
├── link.ld              Legacy ROM-linked firmware linker script
├── link_app_sdram.ld    Runtime application linker script for execution from SDRAM
├── main.cpp             Application entry point executed after stage0 handoff
├── i2c.h            I2C MMIO driver (wb_i2c peripheral)
└── lib/
    ├── sdram/       SDRAM helpers and allocator backing store
    │   ├── sdram.h
    │   └── sdram.cpp
    ├── modbus/      Modbus RTU master MMIO driver for wb_modbus_master
    │   ├── ModbusMaster.h
    │   └── ModbusMaster.cpp
    ├── serial/      UART1 MMIO helper (Arduino-style API)
    │   ├── Serial.h
    │   └── Serial.cpp
    ├── u8g2/        u8g2 graphics library (git submodule)
    │   └── csrc/    132 C source files compiled with --gc-sections
    └── u8g2_hal/    u8g2 hardware abstraction layer (our code)
        ├── u8g2_hal.h   HAL declarations
        └── u8g2_hal.cpp I2C callback + delay callback
```

Related bootloader sources live in `src/bootloader/`:

```text
src/bootloader/
├── start.S          Stage0 ROM startup
├── link.ld          Stage0 ROM linker script
└── boot_stage0.cpp  SPI flash image validation, SDRAM copy, CRC, jump to app
```

## Runtime Boot Architecture

1. `boot_stage0` executes from ROM at `0x00000000`.
2. Stage0 reads the firmware image header from SPI flash offset `0x244000`.
3. After header and payload CRC validation, stage0 copies the application into SDRAM at `0x20000000` and jumps to the entry point.
4. `start.S` runs from SDRAM, initializes `.data`/`.bss`, calls global constructors, then enters `main()`.
5. Runtime SDRAM self-tests use a dedicated scratch area and must not overwrite the image currently executing from SDRAM.

---

## Memory Map

| Address Range | Size | Description |
|---|---|---|
| `0x00000000–0x0000FFFF` | 64 KiB | **Boot ROM** — stage0 bootloader only |
| `0x00010000–0x0001FFFF` | 64 KiB | **RAM** — stack, BSS, initialized data |
| `0x10000000` | 4 B | **D2 LED GPIO** (`wb_gpio`) |
| `0x10000004` | 4 B | **RJ45 LED0** (`wb_led`) |
| `0x10000008` | 4 B | **RJ45 LED1** (`wb_led`) |
| `0x10004000` | 32 B | **UART1 Modbus master** (`wb_modbus_master`) |
| `0x10005000` | 32 B | **I2C0** |
| `0x10006000` | 32 B | **NodeNet485** (RS-485 @ 1 Mb/s, includes LED pulse config) |
| `0x10007000` | 32 B | **SPI Flash** (`wb_flash`, W25Q64 via USRMCLK) |
| `0x20000000–0x207FFFFF` | 8 MB | **SDRAM** — runtime app image, `SDRAM_DATA`, large buffers |

---

## Peripheral Examples

Flash persistence status snapshot (current `main.cpp` boot flow):
- `[FLASH] LowLevel PASS`
- `[FDB] Ready`
- `[FDB] boot cnt updated`
- The flash driver also exposes a stable ASCII `deviceId` derived from the W25Q64 factory UID and shown on the OLED at boot.

### D2 LED GPIO (`0x10000000`)

```cpp
#define LED (*(volatile uint32_t*)0x10000000)

LED = 1;    // ON
LED = 0;    // OFF
LED ^= 1;   // Toggle
```

Current `main.cpp` heartbeat policy uses a non-blocking software toggle every 500 ms.

### RJ45 LEDs (`wb_led`: `0x10000004`, `0x10000008`)

RJ45 LEDs are controlled through the `wb_led` peripheral and firmware helpers in `include/led.h`.
Hardware is wired active-low with pull-up, but `Led::On/Off/Blink` remain logical (On = visible LED ON).

```cpp
#include "led.h"

#define LED0_BASE 0x10000004UL
#define LED1_BASE 0x10000008UL

wb_led::Led led0(LED0_BASE, false);
wb_led::Led led1(LED1_BASE, false);

led0.Blink(100);   // non-blocking one-shot pulse (100 ms)
led1.On();         // set default state ON
led1.Off();        // set default state OFF
```

These two addresses remain available for diagnostics or visual activity signaling.

---

### UART1 (`wb_modbus_master`: `0x10004000`) — Modbus RTU Master

The firmware includes a Modbus RTU master helper in `lib/modbus/ModbusMaster.h` and `lib/modbus/ModbusMaster.cpp`.

`wb_modbus_master` is a Wishbone wrapper around `uart_simple` with hardware-managed:
- RTU transaction timing
- CRC16 TX generation and RX validation
- timeout / retry / status flags

Minimal usage example:

```cpp
#include "ModbusMaster.h"

constexpr uint32_t MODBUS1_BASE = 0x10004000u;
constexpr uint8_t MODBUS_SLAVE = 0x01u;
ModbusMaster modbus1(MODBUS1_BASE);

int main() {
    modbus1.begin(9600, 500, 2);   // baud, timeout_ms, retries
    modbus1.setInterframeCharsQ1(14);

    uint16_t version = 0;
    if (modbus1.readHoldingRegisters(MODBUS_SLAVE, 0x8000, 1, &version)) {
        // Waveshare encoding: 0x0064 => V1.00
    }

    for (;;) {
        (void)modbus1.writeSingleCoil(MODBUS_SLAVE, 0x0000, true);
    }
}
```

Useful methods:
- `begin(baud, timeout_ms, retries)`
- `setInterframeCharsQ1(chars_q1)`
- `readCoils`, `readDiscreteInputs`, `readHoldingRegisters`, `readInputRegisters`
- `writeSingleCoil`, `writeMultipleCoils`, `writeSingleRegister`, `writeMultipleRegisters`
- `lastError()`, `lastExceptionCode()`, `lastHwStatus()`

Legacy note: `lib/serial/Serial` remains available as a standalone utility class but UART1 hardware is now mapped to Modbus RTU master in the default top-level SoC.

---

### NodeNet485 (`0x10006000`) — Multi-Node RS-485 Mailbox Transport

The NodeNet485 protocol enables reliable multi-node communication over RS-485 at 1 Mb/s.

Validation snapshot (2026-08-20):
- Automatic heartbeat from HDL validated on hardware at ~10 s period.
- RX path validated for frames addressed to the local node.
- TX path validated end-to-end.
- Runtime baud validated at 115200 and 1 Mb/s.
- RX header metadata propagated to firmware (`src`, `dst`, `broadcast`, `len`).
- Distinct broadcast/unicast receive IRQs wired to PicoRV32 callbacks.

**Mailbox Register Model**:
- **TX staging**: firmware writes one message into TX command/data registers
- **RX mailbox**: hardware exposes one decoded message header and a byte stream reader
- **Frame encoding/decoding** happens inside `wb_nodenet.sv`
- **Capacity**: one staged TX message and one decoded RX message at a time

**Register Flow** (Firmware Controls):

```
TX Path (Firmware → Hardware):
    1. Write TX_CMD = [dst | len]
    2. Write payload bytes through TX_DATA
    3. Write CONTROL.bit0 to trigger transmission
    4. Hardware schedules, frames, and transmits over UART

RX Path (Hardware → Firmware):
    1. Hardware receives, decodes, and validates a frame
    2. Hardware exposes source, destination, valid, and length through RX_HDR
    3. Firmware checks RX valid bit
    4. Firmware drains payload bytes through RX_DATA
```

**Complete API** (from `lib/nodenet/nodenet.h`):

```cpp
#include "lib/nodenet/nodenet.h"

constexpr uint32_t NODENET0_BASE = 0x10006000u;
NodeNet myNodeNet(
    NODENET0_BASE,
    0x01,
    1'000'000,
    200,
    nullptr,
    nullptr);

// Send unicast message to node 0x02
myNodeNet.Send(0x02, "Hello", 5);

// Send broadcast to all nodes
myNodeNet.Broadcast("ALERT");

myNodeNet.SetCallbacks(onBroadcast, onMessage);
```

`NodeNetMessage` exposes `src_addr`, `dest_addr`, `broadcast`, `len`, and `data`.

**IRQ callback pattern**:

```cpp
static volatile bool g_msg_pending = false;

static void onMessage(const NodeNetMessage& msg)
{
    // Snapshot only. Defer OLED / flash / Send() work.
    g_msg_pending = true;
}

int main()
{
    NodeNet myNodeNet(NODENET0_BASE, 0x41, 1'000'000,
                      200, nullptr, nullptr);

    // Finish the rest of system init first.
    myNodeNet.SetCallbacks(onBroadcast, onMessage);

    while (1) {
        if (g_msg_pending) {
            g_msg_pending = false;
        }
    }
}
```

**Detailed API**:

```cpp
class NodeNet {
public:
    explicit NodeNet(uint32_t base, uint8_t addr, uint32_t uart_baud, uint32_t led_blink_ms = 100u,
                     MessageCallback broadcastCallback = nullptr, MessageCallback messageCallback = nullptr);
    void Init(uint8_t addr, uint32_t uart_baud, uint32_t led_blink_ms = 100u,
              MessageCallback broadcastCallback = nullptr, MessageCallback messageCallback = nullptr);
    uint32_t Status() const;
    bool TxMailboxReady() const;
    bool TxHasSpace(uint16_t msg_len) const;
    bool HasMessage() const;
    uint8_t MessageCount() const;
    void Send(uint8_t dst, const uint8_t* data, uint16_t len) const;
    void Send(uint8_t dst, const char* str) const;
    void Broadcast(const uint8_t* data, uint16_t len) const;
    void Broadcast(const char* str) const;
    NodeNetMessage ReadMessage() const;
    static void FreeMessage(NodeNetMessage& msg);
};
```

**Echo Loop Example** (Listen and reply):

```cpp
int main() {
    constexpr uint32_t NODENET0_BASE = 0x10006000u;
    NodeNet myNodeNet(NODENET0_BASE, 0x01, 1'000'000, 200);
    
    while (1) {
        if (myNodeNet.HasMessage()) {
            NodeNetMessage msg = myNodeNet.ReadMessage();
            
            // Echo back unicast messages to sender
            if (msg.src_addr != 0) {
                myNodeNet.Send(msg.src_addr, msg.data, msg.len);
            }
            
            NodeNet::FreeMessage(msg);  // Don't forget!
        }
    }
}
```

**Multi-Node Query Example** (Send and wait for response):

```cpp
int main() {
    constexpr uint32_t NODENET0_BASE = 0x10006000u;
    NodeNet myNodeNet(NODENET0_BASE, 0x01, 1'000'000, 200);
    
    // Send request to node 0x02
    myNodeNet.Send(0x02, "STATUS?", 7);
    
    // Wait for response (timeout = 1 second)
    uint32_t deadline = get_cycles() + 25_000_000;
    
    while (get_cycles() < deadline) {
        if (myNodeNet.HasMessage()) {
            NodeNetMessage msg = myNodeNet.ReadMessage();
            
            if (msg.src_addr == 0x02) {
                // Got response!
                printf("Temperature: %.*s\n", msg.len, msg.data);
                NodeNet::FreeMessage(msg);
                return 0;
            }
            
            NodeNet::FreeMessage(msg);
        }
    }
    
    printf("No response from node 0x02 (timeout)\n");
    return 1;
}
```

**Mailbox Debugging**:

```cpp
NodeNet myNodeNet(NODENET0_BASE, 0x01, 1'000'000, 200);
uint32_t status = myNodeNet.Status();
bool tx_busy = (status & (NODENET_STATUS_TX_PENDING | NODENET_STATUS_TX_ACTIVE)) != 0;
bool rx_ready = (status & NODENET_STATUS_RX_VALID) != 0;
bool rx_error = (status & (NODENET_STATUS_RX_ERROR | NODENET_STATUS_RX_OVERFLOW)) != 0;

uint32_t header = *(volatile uint32_t *)(NODENET0_BASE + NODENET_RX_HDR_OFS);
uint8_t src = header >> 24;
uint16_t len = header & 0xFFFF;
```

**Performance Characteristics**:
- **Baud Rate**: 1 Mb/s (25-cycle divisor @ 25 MHz)
- **Throughput**: ~40–50 kB/s effective (after protocol overhead)
- **Message Latency**: ~10 ms for 64-byte message
- **Mailbox Capacity**: one staged TX message + one decoded RX message
- **Anti-Collision**: Automatic backoff per node address
  - Broadcast: 50 ms × node_addr
  - Unicast: 2 ms × node_addr
- **Heartbeat**: Default ~10 seconds (configurable)

**Hardware Integration**:
- **RX Pin**: G5 (input from RS-485 transceiver)
- **TX Pin**: D16 (output to RS-485 transceiver)
- **Driver Enable**: Automatic (hardware module handles)
- **Current Status**: Functional TX/RX framing with mailbox-based Wishbone API

Bring-up note:
- If you change IRQ startup / bootloader ROM forwarding, `make flash-fw` is not enough. Reload the FPGA image (`make ram` or equivalent) so the ROM vector at `0x00000004` matches the SDRAM app IRQ entry.

For full protocol documentation including frame format, CRC, encoding details, and IRQ integration, see [../wbDevices/README_NODENET.md](../wbDevices/README_NODENET.md).

---

### SPI Flash (`0x10007000`) — Low-Level Access + FlashDB KV Storage

The onboard W25Q64 (8 MB) is exposed through the `wb_flash` peripheral.
`flash.h` provides low-level page/sector operations, a factory UID reader, and a stable ASCII `deviceId` helper; `flashdb_port.h` provides typed key-value helpers.

```cpp
#include "flash.h"
#include "flashdb_port.h"

Flash flash(0x10007000u);
flashdb_init(&flash, nullptr);

flashdb_set_str("device_name", "nodenet-01");
char name[32] = {};
flashdb_get_str("device_name", name, sizeof(name));

char device_id[12] = {};
flash.readUniqueIdAscii(device_id, sizeof(device_id));
```

Implementation notes:
- SPI SCK uses the ECP5 dedicated USRMCLK path (not a normal GPIO pin).
- Firmware-side protection keeps writes/erases out of the boot region.
- Raw point catalog uses `0x200000-0x202FFF`.
- Persistent PLC package storage uses `0x204000-0x223FFF` and can retain multiple slots in one flash package.
- FlashDB uses partition `nodenet_kv` at `0x224000-0x242FFF`.
- `0x243000-0x243FFF` stays reserved for low-level flash self-test scratch.
- Large PLC artifacts should prefer the raw PLC package slot over FlashDB.
- The ASCII `deviceId` is derived from the 64-bit factory UID and contains only `a-z`, `A-Z`, and `0-9`.

Host-side PLC package flow:

```bash
python src/firmware/tools/pack_plc_linked_package.py \
    --input linked_code.bin \
    --output src/firmware/build/plc_linked_package.img \
    --symbol-count 12 \
    --relocation-count 12 \
    --runtime-header-addr 0x20100000 \
    --store-epoch 1

python src/firmware/tools/verify_plc_linked_package.py \
    --input src/firmware/build/plc_linked_package.img \
    --expect-runtime-header-addr 0x20100000 \
    --expect-store-epoch 1

make plc-package-check PLC_LINKED_CODE_INPUT=linked_code.bin \
    PLC_PACKAGE_SYMBOL_COUNT=12 PLC_PACKAGE_RELOCATION_COUNT=12 \
    PLC_PACKAGE_STORE_EPOCH=1

make flash-plc-package PLC_LINKED_CODE_INPUT=linked_code.bin \
    PLC_PACKAGE_SYMBOL_COUNT=12 PLC_PACKAGE_RELOCATION_COUNT=12 \
    PLC_PACKAGE_STORE_EPOCH=1
```

Detailed register-level documentation is available in [../wbDevices/README_FLASH.md](../wbDevices/README_FLASH.md).

---

### SDRAM (`0x20000000`, 8 MB available for application)

⚠️ **SDRAM Allocation**:
- **0x20000000–0x207FFFFF (8 MB)** ← Available for PicoRV32 application and large buffers

**Important**: the SDRAM controller performs a ~200 µs initialization at power-on. Do not access SDRAM before `sdram_wait_ready()` returns.

**Current validation status**:
- `sdramTest()` runs at boot and checks several reserved scratch regions plus a byte-pattern test.
- A dedicated `SDRAM_DATA` probe object is linked from a single translation unit and verified at runtime.
- Full firmware execution from SDRAM is validated.
- Sub-word CPU stores now work through the Wishbone SDRAM wrapper via read-modify-write.

```cpp
#include "sdram.h"

// Place large variables in SDRAM at link time
// (linker assigns addresses automatically from SDRAM_BASE)
SDRAM_DATA uint8_t  frame_buffer[128 * 64 / 8];  // 1 KB framebuffer
SDRAM_DATA uint32_t modbus_log[4096];             // 16 KB log

int main() {
    // Must be called before any SDRAM access
    sdram_wait_ready();

    // Zero-initialize (SDRAM content is undefined at power-on)
    __builtin_memset(frame_buffer, 0, sizeof(frame_buffer));

    // Use linker-placed SDRAM objects directly
    modbus_log[0] = 0xDEADBEEF;

    // Memory test (reserved scratch area, safe while code executes from SDRAM)
    uint32_t errors = sdram_test(1024);  // Test 4 KB inside scratch space
    if (errors == 0) uart_puts("SDRAM OK\n");
}
```

Avoid destructive writes to `SDRAM_BASE` unless you control the placement and know you are outside the currently executing app image.

For the integrated boot self-test path used by `main.cpp`:

```cpp
if (sdramTest(oled_boot_status)) {
    oled_write("[BOOT] System ready");
} else {
    oled_write("[BOOT] Degraded mode");
}
```

**Allocating large buffers dynamically** (pointer arithmetic):
```cpp
// Manual allocator from SDRAM base
// Coordinate this with the linker map so allocations do not overlap the app image.
static uintptr_t sdram_ptr = SDRAM_BASE;

void* sdram_alloc(size_t bytes) {
    void* p = (void*)sdram_ptr;
    sdram_ptr += (bytes + 3) & ~3;  // align to 4 bytes
    
    // Safety check: don't allocate beyond 8 MB boundary
    if (sdram_ptr > 0x20800000) return nullptr;
    return p;
}
```

**ArduinoJson 7 with the SDRAM allocator**:

The firmware integrates ArduinoJson 7 in freestanding mode. For small documents, a regular `JsonDocument` is fine. For larger payloads, you can move the JSON heap into SDRAM with `g_sdram_json_allocator`.

Rules:
- Call `sdram_wait_ready()` before any SDRAM access.
- Call `sdram_json_allocator_init()` once before the first `JsonDocument doc(&g_sdram_json_allocator);`.
- The default JSON pool is `SDRAM_JSON_POOL_SIZE` (`256 KiB`) in `g_sdram_json_pool`.
- The pool lives in SDRAM, so its content is undefined after reset until you initialize it.

```cpp
#include <ArduinoJson.h>
#include "sdram.h"

static void json_example(void)
{
    if (!sdram_wait_ready()) {
        uart_puts("SDRAM not ready\n");
        return;
    }

    if (!sdram_json_allocator_init()) {
        uart_puts("JSON allocator init failed\n");
        return;
    }

    JsonDocument doc(&g_sdram_json_allocator);
    doc["node"] = "NodeNet";
    doc["uptime_ms"] = *TIMER_MS;
    doc["sdram"] = true;

    char buffer[128];
    size_t len = serializeJson(doc, buffer, sizeof(buffer));
    if (len < sizeof(buffer)) {
        buffer[len] = '\0';
        uart_puts(buffer);
        uart_puts("\n");
    }
}
```

This allocator is implemented in `lib/sdram/sdram.cpp` as a simple free-list over `g_sdram_json_pool`. It supports `allocate()`, `deallocate()`, and `reallocate()`, which matches what ArduinoJson 7 expects from a custom allocator.

**SDRAM Regions (Memory Map)**:
```
Hardware: 8 MB total (M12L64322A SDRAM on Colorlight i9)
└─ 0x20000000 ─ 0x207FFFFF (8 MB)  ← Runtime image + application SDRAM region
    ├─ `.text` / `.rodata` / `.data` / `.bss` for the SDRAM-linked app
    ├─ `SDRAM_DATA` variables (placed by linker)
    ├─ Reserved scratch space for `sdramTest()`
    └─ Remaining free space / manual allocation if coordinated with the linker map
```

**Constants in `sdram.h`**:
```cpp
#define SDRAM_BASE  0x20000000UL
#define SDRAM_SIZE  (8UL * 1024 * 1024)
```

---

### I2C0 (`0x10005000`) — via `i2c.h`

`i2c.h` provides an `I2c` API for the `wb_i2c` wrapper around
`i2c_master_wbs_16`.

```cpp
#include "i2c.h"

void i2c_example(void) {
    I2c i2c;

    // Set clock: 400 kHz @ 25 MHz (prescale = 25e6 / (400e3 * 4) = 15)
    i2c.begin(15);

    // Write: send a 2-byte command to device at address 0x3C
    uint8_t cmd[] = { 0x00, 0xAF };     // SSD1306: Co=0, D/C=0, DISPLAY_ON
    uint8_t rc = i2c.write(0x3C, cmd, 2);  // I2c::I2C_OK on success
    if (rc != I2c::I2C_OK) uart_puts("I2C write failed\n");
}
```

**Raw MMIO access** (for custom protocols, 16-bit register words in 32-bit stride):
```cpp
constexpr uint32_t I2C0_BASE = 0x10005000u;
auto i2c_reg = [](uint32_t base, uint32_t ofs) -> volatile uint32_t& {
    return *reinterpret_cast<volatile uint32_t*>(base + ofs);
};

constexpr uint32_t I2C16_REG_STATUS = 0x00u;
constexpr uint32_t I2C16_REG_CMD    = 0x04u;
constexpr uint32_t I2C16_REG_DATA   = 0x08u;
constexpr uint32_t I2C16_REG_PRESC  = 0x0Cu;

constexpr uint16_t I2C16_CMD_START      = (1u << 8);
constexpr uint16_t I2C16_CMD_WRITE_MULT = (1u << 11);
constexpr uint16_t I2C16_CMD_STOP       = (1u << 12);
constexpr uint16_t I2C16_DATA_VALID     = (1u << 8);
constexpr uint16_t I2C16_DATA_LAST      = (1u << 9);
constexpr uint16_t I2C16_FIFO_WR_FULL   = (1u << 12); // STATUS bit
constexpr uint16_t I2C16_FIFO_CMD_FULL  = (1u << 9);  // STATUS bit

// Set prescaler for 100 kHz @ 25 MHz
i2c_reg(I2C0_BASE, I2C16_REG_PRESC) = 62u;

// Push one data byte with DATA_VALID and DATA_LAST
while (i2c_reg(I2C0_BASE, I2C16_REG_STATUS) & I2C16_FIFO_WR_FULL);
i2c_reg(I2C0_BASE, I2C16_REG_DATA) = (0xAFu | I2C16_DATA_VALID | I2C16_DATA_LAST);

// Push START + WRITE_MULT + STOP to slave 0x3C
while (i2c_reg(I2C0_BASE, I2C16_REG_STATUS) & I2C16_FIFO_CMD_FULL);
i2c_reg(I2C0_BASE, I2C16_REG_CMD) = (0x3Cu | I2C16_CMD_START | I2C16_CMD_WRITE_MULT | I2C16_CMD_STOP);

// Poll status busy bit until transfer complete
while (i2c_reg(I2C0_BASE, I2C16_REG_STATUS) & 0x1u) {}
```

---

### OLED Display — u8g2 + `u8g2_hal.h`

u8g2 is cloned as a git submodule in `lib/u8g2/`.  
The HAL (`u8g2_hal.h`/`u8g2_hal.cpp`) connects u8g2 to the hardware I2C peripheral.

**Wiring**: SSD1306 OLED → SCL=D18, SDA=D17 with 4.7 kΩ pullups to 3.3 V.

#### 128×64 SSD1306

```cpp
#include "u8g2_hal.h"

u8g2_t display;

void oled_init(void) {
    u8g2_Setup_ssd1306_i2c_128x64_noname_f(
        &display,
        U8G2_R0,              // No rotation
        u8x8_byte_i2c_hw,     // Our I2C callback (u8g2_hal.cpp)
        u8x8_gpio_delay_hw    // Our delay callback
    );
    u8g2_InitDisplay(&display);
    u8g2_SetPowerSave(&display, 0);  // Wake up display
}

void oled_hello(void) {
    u8g2_ClearBuffer(&display);
    u8g2_SetFont(&display, u8g2_font_ncenB08_tr);
    u8g2_DrawStr(&display, 0, 12, "RISC-V SoC");
    u8g2_SetFont(&display, u8g2_font_6x10_tr);
    u8g2_DrawStr(&display, 0, 26, "Colorlight i9");
    u8g2_DrawStr(&display, 0, 40, "25 MHz PicoRV32");
    u8g2_SendBuffer(&display);     // Push framebuffer to OLED
}

void oled_counter(uint32_t n) {
    char buf[16];
    // Simple integer to string (no sprintf to save ROM)
    uint8_t i = 0;
    do { buf[i++] = '0' + (n % 10); n /= 10; } while (n && i < 14);
    buf[i] = '\0';
    // Reverse
    for (uint8_t a=0, b=i-1; a<b; a++, b--) {
        char t=buf[a]; buf[a]=buf[b]; buf[b]=t;
    }
    u8g2_ClearBuffer(&display);
    u8g2_SetFont(&display, u8g2_font_ncenB14_tr);
    u8g2_DrawStr(&display, 0, 20, buf);
    u8g2_SendBuffer(&display);
}
```

#### 128×32 SSD1306

```cpp
// Change the setup function, everything else is identical
u8g2_Setup_ssd1306_i2c_128x32_univision_f(
    &display, U8G2_R0,
    u8x8_byte_i2c_hw, u8x8_gpio_delay_hw);
```

#### Available fonts (small selection)

| Font | Height | Width | Good for |
|---|---|---|---|
| `u8g2_font_ncenB08_tr` | 8px | var | Small text |
| `u8g2_font_ncenB14_tr` | 14px | var | Medium titles |
| `u8g2_font_6x10_tr` | 10px | 6px | Fixed-width text |
| `u8g2_font_7x13_tr` | 13px | 7px | Readable labels |

Full font list: https://github.com/olikraus/u8g2/wiki/fntlistall

#### Complete main() example

```cpp
#include <stdint.h>
#include "sdram.h"
#include "i2c.h"
#include "u8g2_hal.h"

extern "C" void __cxa_pure_virtual() { while (1); }

#define LED        (*(volatile uint32_t*)0x10000000)
#define UART0_DATA (*(volatile uint32_t*)0x10001000)
#define UART0_BAUD (*(volatile uint32_t*)0x10001008)

static u8g2_t display;

int main() {
    // 1. Init UART
    UART0_BAUD = 27;

    // 2. Init SDRAM (wait ~200 µs for controller init)
    sdram_wait_ready();

    // 3. Init OLED
    u8g2_Setup_ssd1306_i2c_128x64_noname_f(
        &display, U8G2_R0,
        u8x8_byte_i2c_hw, u8x8_gpio_delay_hw);
    u8g2_InitDisplay(&display);
    u8g2_SetPowerSave(&display, 0);

    // 4. Display boot message
    u8g2_ClearBuffer(&display);
    u8g2_SetFont(&display, u8g2_font_ncenB08_tr);
    u8g2_DrawStr(&display, 0, 12, "SoC boot OK");
    u8g2_SendBuffer(&display);

    // 5. Blink + echo loop
    uint32_t tick = 0;
    for (;;) {
        LED = (tick++ >> 18) & 1;  // Blink ~3 Hz
    }
}
```

---

## C++ Startup Details

`start.S` runs before `main()`:

```asm
_start:
    la sp, _stack_top           # Set stack pointer (0x00020000)

    # Call C++ global constructors (.init_array)
    la   a0, __init_array_start
    la   a1, __init_array_end
.Lctor_loop:
    beq  a0, a1, .Lctor_done
    lw   t0, 0(a0)
    jalr t0
    addi a0, a0, 4
    j    .Lctor_loop
.Lctor_done:

    call main                   # Jump to application
```

**Implication**: global C++ objects with constructors (e.g. `u8g2_t display;`) are initialized automatically before `main()`.

## SDRAM Data Placement

Variables marked `SDRAM_DATA` are placed in the `.sdram` linker section:

```cpp
// In any .cpp file:
#include "sdram.h"

SDRAM_DATA uint8_t  big_buffer[512 * 1024];   // 512 KB in SDRAM
SDRAM_DATA uint32_t history[16384];            // 64 KB log in SDRAM

// ⚠️ These are NOT zero-initialized at boot!
// Zero-init explicitly if needed:
//   __builtin_memset(big_buffer, 0, sizeof(big_buffer));
```

The linker places these starting at `0x20000000`. Addresses are assigned in source-file link order.

**Call `sdram_wait_ready()` before the first access**, otherwise the CPU will stall until the SDRAM controller finishes its ~200 µs initialization sequence (which it will, eventually — but your code is blocked until then).

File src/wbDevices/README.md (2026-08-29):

# Wishbone Bus Peripherals

This directory contains reusable Wishbone B.4-compliant peripheral modules for the Colorlight i9 SoC.

## Overview

All modules follow the Wishbone B.4 standard with:
- 32-bit address bus
- 32-bit data bus
- Single-cycle read/write (in most cases)
- Byte-enable support (`wb_sel_i`)

Current top-level mapping note:
- UART1 MMIO at `0x10004000` is now provided by `src/modbus/wb_modbus_master.sv`.
- `wb_uart.sv` remains available in this directory for standalone UART/FIFO use.

## Modules

### 1. `wb_uart.sv` – Wishbone UART Wrapper + FIFOs

**Purpose**: Memory-mapped UART peripheral for CPU firmware (`DATA`, `STATUS`, `BAUD`) with integrated RX/TX FIFOs.

**Architecture**:
- `uart_simple.sv` = reusable UART 8N1 serial core
- `wb_uart.sv` = Wishbone B.4 wrapper + register map + RX/TX FIFOs around `uart_simple`

This matches the same layered approach used by NodeNet:
- `wb_nodenet.sv` keeps its own NodeNet framing/mailbox logic and also uses `uart_simple` for wire-level UART.

**Address**: Configurable (default: `0x10001000`)

**Register Map**:

| Offset | Name | Read | Write | Bits | Notes |
|---|---|---|---|---|---|
| 0x0 | DATA | RX FIFO pop | TX FIFO push | [7:0] | 8-bit characters |
| 0x4 | STATUS | Flags (RO) | N/A | [5:0] | See below |
| 0x8 | BAUD | N/A | Prescale | [15:0] | Default 27 (~115.2k @ 25 MHz) |

**STATUS Register** (read-only):

| Bit | Name | Meaning |
|-----|---|---|
| 0 | RX_FIFO_EMPTY | 1 = no data in RX FIFO, cannot read DATA |
| 1 | RX_FIFO_FULL | 1 = RX FIFO full, next byte will be dropped |
| 2 | TX_FIFO_EMPTY | 1 = TX FIFO empty, no pending transmissions |
| 3 | TX_FIFO_FULL | 1 = TX FIFO full, cannot write DATA |
| 4 | RX_OVERRUN_STICKY | 1 = RX overflow occurred (write 1 to clear) |
| 5 | RX_FRAMEERR_STICKY | 1 = framing error occurred (write 1 to clear) |

**Parameters**:

```systemverilog
parameter ADDR = 32'h1000_1000;        // Base address
parameter DEFAULT_PRESCALE = 16'd27;   // Baud rate divisor
parameter FIFO_ADDR_WIDTH = 4;         // FIFO depth: 2^4 = 16 bytes
```

**Baud Rate Calculation** (`REG_BAUD`):
```
baud = clock_frequency / (8 * prescale)
prescale = clock_frequency / (8 * baud)

Example: 115200 baud @ 25 MHz
prescale = 25_000_000 / (8 * 115200) ≈ 27.1 → use 27
```

**Features**:
- **16-byte RX FIFO**: Prevents data loss during CPU delays
- **16-byte TX FIFO**: Allows burst writes, hardware handles serial transmission
- **Circular buffer logic**: Automatic wrap-around with full/empty detection
- **Error flags**: Sticky bits for over-run and frame errors (sticky until cleared)

**Usage Example**:

```c
#define UART1_DATA     0x10004000
#define UART1_STATUS   0x10004004
#define UART1_BAUD     0x10004008

volatile uint32_t *uart_data   = (volatile uint32_t *)UART1_DATA;
volatile uint32_t *uart_status = (volatile uint32_t *)UART1_STATUS;
volatile uint32_t *uart_baud   = (volatile uint32_t *)UART1_BAUD;

// Initialize
void uart_init(uint16_t prescale) {
    *uart_baud = prescale;  // Set baud rate
}

// Transmit byte (blocking)
void uart_putc(char c) {
    while (*uart_status & 0x8);  // Wait for TX not full
    *uart_data = c;
}

// Receive byte (blocking)
char uart_getc(void) {
    while (*uart_status & 0x1);  // Wait for RX not empty
    return (char)(*uart_data & 0xFF);
}

// Non-blocking receive
int uart_getc_nb(char *c) {
    if (*uart_status & 0x1) return -1;  // No data
    *c = (char)(*uart_data & 0xFF);
    return 0;
}
```

**Hardware Integration**:
- Direct UART RX/TX pins (`rxd`, `txd`) for the `UART1` peripheral instance
- Wishbone access is edge-fired (`wb_fire`) to avoid duplicated reads/writes when `cyc/stb` are held
- FIFOs absorb software latency and burst writes

---

### 2. `wb_ram.sv` – 64 KiB Embedded RAM

**Purpose**: Main system memory for stack and variables.

**Address**: `0x00010000–0x0002FFFF` (64 KiB, fixed)

**Register Map**: Linear 32-bit word array (no special registers)

**Parameters**:

```systemverilog
parameter ADDR_WIDTH = 14;  // 2^14 = 16K words = 64K bytes
parameter ADDR = 32'h0001_0000;
```

**Features**:
- Single-port synchronous RAM
- 32-bit data width with byte-enable support
- Sub-word writes via `wb_sel_i` (4 enable bits for [3:0] bytes)
- Single-cycle RW latency

**Usage Example**:

```c
volatile uint32_t *ram_base = (volatile uint32_t *)0x00010000;

// Write 32-bit word
ram_base[0x100] = 0xDEADBEEF;

// Read 32-bit word
uint32_t data = ram_base[0x100];

// Via byte pointer (sub-word access)
volatile uint8_t *ram_bytes = (volatile uint8_t *)0x00010000;
ram_bytes[0x402] = 0x42;  // Write single byte at offset 0x402
```

**Memory Layout** (from linker script):
```
0x00010000  runtime RAM base
0x00010XXX  initialized data / small runtime state
0x0001FFFF  stack top (grows down)
```

**Notes**:
- Byte-enable is critical for byte/half-word writes
- On read: full 32-bit word returned; firmware masks as needed

---

### 3. `wb_rom.sv` – 64 KiB Stage0 Boot ROM

**Purpose**: Immutable stage0 bootloader storage, loaded from synthesis-time hex file.

**Address**: `0x00000000–0x0000FFFF` (64 KiB, fixed)

**Register Map**: Read-only 32-bit word array

**Parameters**:

```systemverilog
parameter ADDR_WIDTH = 14;  // 2^14 = 16K words = 64K bytes
parameter INIT_FILE = "firmware.hex";  // Yosys $readmemh() format
parameter ADDR = 32'h0000_0000;
```

**Features**:
- Read-only (writes ignored, no error signaling)
- Single-cycle read latency
- Initialized at synthesis from `.hex` file
- Contains the ROM-resident `boot_stage0` image that validates the SPI-flash application image and jumps to SDRAM execution

**Hex File Format** (Intel HEX or Verilog):
```
:10000000 AABBCCDD EEFF0011 22334455 ...
:00000001FF
```

**Usage**:
- PicoRV32 CPU boots from `pc=0x00000000`
- First instruction of `boot_stage0` must be in this ROM
- No runtime modification (for reliability)

**Current Implementation**:
- Stage0 ROM image built to `src/firmware/build/boot_stage0.hex`
- Referenced in [wb_rom.sv](wb_rom.sv) at synthesis time
- Contains the stage0 boot path only; the main runtime application is packaged separately in SPI flash and executes from SDRAM

---

### 4. `wb_gpio.sv` – LED Output (1-bit GPIO)

**Purpose**: Simple output control for LED indicator (D2 on Colorlight i9).

**Address**: `0x10000000` (fixed)

**Register Map**:

| Offset | Name | Width | Bits | Notes |
|---|---|---|---|---|
| 0x0 | LED_OUT | 32-bit | [0] | Only bit 0 used; others ignored |

**Parameters**:

```systemverilog
parameter ADDR = 32'h1000_0000;
parameter OUTPUT_PIN = "D2";  // FPGA port name
```

**Features**:
- Single write-only register
- Only byte [0] is latched (see `wb_sel_i[0]`)
- Output combinatorial (reflects register immediately)
- Read returns last written value

**Usage Example**:

```c
#define LED_GPIO 0x10000000

volatile uint32_t *led_gpio = (volatile uint32_t *)LED_GPIO;

// Turn on LED
*led_gpio = 1;

// Turn off LED
*led_gpio = 0;

// Toggle
uint32_t state = *led_gpio;
*led_gpio = !state;
```

**Hardware**:
- FPGA port: `output wire led_out`
- Mapped to physical pin D2 via constraints file (`colorlight_i9.lpf`)

---

### 5. `led_pulse_core.sv` – Generic LED Pulse Engine (No Bus)

**Purpose**: Reusable hardware pulse/state engine used by bus wrappers and event-driven blocks.

**Inputs**:
- `trigger_i`: starts one non-blocking pulse
- `set_default_i`: updates persistent default state
- `default_value_i`: default state value when `set_default_i=1`
- `blink_cycles_i`: pulse width in clock cycles (`0` uses module parameter)

**Polarity**:
- `ACTIVE_LOW=0`: `led_o=1` means LED ON (active-high)
- `ACTIVE_LOW=1`: `led_o=0` means LED ON (active-low)

**Outputs**:
- `led_o`: current LED level
- `busy_o`: pulse currently active
- `default_state_o`: latched default state

This module is used by both `wb_led.sv` (Wishbone wrapper) and `wb_nodenet.sv` (event-driven TX/RX activity LEDs).

---

### 6. `wb_led.sv` – Non-Blocking LED Pulse Controller

**Purpose**: Hardware-timed one-shot LED pulses over Wishbone, used for RJ45 LEDs.

**Addresses in current top-level integration**:
- `0x10000004`: LED0 (pin F5)
- `0x10000008`: LED1 (pin E6)

**Write Commands** (`wb_dat_i`):
- `bit0 = 1`: trigger one-shot pulse
- `bits31:3`: optional duration override (clock cycles, `0` means use `BLINK_CYCLES` parameter)
- `bit1 = 1`: update default state
- `bit2`: new default state value (0 = OFF, 1 = ON)

**Readback** (`wb_dat_o`):
- `bit0`: current LED output level
- `bit1`: pulse active (`busy`)
- `bit2`: default state

**Parameters**:

```systemverilog
parameter ADDR = 32'h1000_0004;
parameter ACTIVE_LOW = 1'b0;
parameter DEFAULT_STATE = 1'b0;
parameter BLINK_CYCLES = 32'd2500000; // 100 ms @ 25 MHz
```

**Firmware usage**:
- See `src/firmware/include/led.h` for helper functions and `wb_led::Led` wrapper.
- Current policy: D2 (`wb_gpio`) is used as the primary boot/status indicator; RJ45 LEDs can be driven through `wb_led` when needed.
- Current board policy for external LEDs is active-low with pull-up, so wrappers set `ACTIVE_LOW=1` in top-level integrations.

---

### 7. `wb_sdram_litedram.sv` – 8 MB External SDRAM Window via LiteDRAM

**Purpose**: Wishbone-facing SDRAM wrapper for the M12L64322A chip on Colorlight i9, exposing 8 MB of external DRAM to the CPU through the generated LiteDRAM core.

**Current role in the boot flow**:
- Stage0 copies the packaged application image from SPI flash into this SDRAM window.
- After the copy and CRC checks, the CPU jumps to the application entry point in SDRAM.
- Runtime `SDRAM_DATA` objects and SDRAM self-tests share this same window, so destructive tests must stay inside reserved scratch space.

**Address**: `0x20000000–0x207FFFFF` (8 MB)

**Hardware Notes (Colorlight i9 v7.2 PCB)**:
> The following signals are **hardwired on the PCB** and are NOT driven by the FPGA:
> - `CS_N` → GND (chip always selected)
> - `CKE` → VCC (clock always enabled)
> - `DQM[3:0]` → GND (byte masking permanently disabled)
>
> **Consequence**: the SDRAM chip itself always sees full 32-bit accesses. The LiteDRAM-facing wrapper compensates for sub-word CPU writes with an internal read-modify-write sequence when `wb_sel_i != 4'b1111`.

**SDRAM Organization**:
| Parameter | Value |
|---|---|
| Chip | M12L64322A |
| Total capacity | 8 MB (64 Mbit) |
| Banks | 4 (`BA[1:0]`) |
| Rows per bank | 2048 (`A[10:0]`, 11-bit) |
| Columns per row | 256 words (`A[7:0]`, 8-bit) |
| Data width | 32 bits (`DQ[31:0]`) |

**Address Mapping** (within 8 MB window):

| `wb_adr_i` bits | SDRAM field | Size |
|---|---|---|
| `[22:21]` | Bank `BA[1:0]` | 4 banks |
| `[20:10]` | Row `A[10:0]` | 2048 rows |
| `[9:2]` | Column `A[7:0]` | 256 words |
| `[1:0]` | Byte offset inside 32-bit word | handled in Wishbone wrapper |

**Parameters**:

```systemverilog
parameter [31:0] ADDR         = 32'h2000_0000;
parameter        CLK_FREQ_MHZ = 25;
parameter        T_INIT_US    = 200;  // Power-on hold delay
parameter        T_RFC_NS     = 63;   // Auto-refresh cycle time
parameter        T_REF_US     = 7;    // Refresh interval (< 7.8 µs)
```

**Timing (25 MHz = 40 ns/cycle)**:

| Parameter | Value | Cycles |
|---|---|---|
| `tRCD` (RAS→CAS) | 40 ns | 1 |
| `tRP` (precharge) | 40 ns | 1 (auto-precharge) |
| `tRFC` (refresh) | 80 ns | 2 |
| CAS latency | — | 2 SDRAM cycles |
| Refresh period | 7 µs | every 175 cycles |
| Read latency | — | 6 FPGA cycles |
| Write latency | — | 4 FPGA cycles |

**Clock technique**: `sdram_clk = ~clk` (inverted). FPGA outputs settle ~2 ns after `posedge clk`; SDRAM captures them at the next `sdram_clk` rising edge (= `negedge clk`, 20 ns later), giving **~18 ns setup margin** vs. tAS = 2 ns minimum.

**Mode Register**: CL=2, BL=1 (single word burst), sequential — programmed automatically during initialization.

**Initialization sequence** (automatic at power-on/reset):
1. Wait 200 µs (5000 cycles)
2. PRECHARGE ALL banks
3. 2× AUTO REFRESH
4. LOAD MODE REGISTER (CL=2, BL=1)
5. Ready — normal operation begins

**Usage Example**:

```c
#define SDRAM_BASE 0x20000000

volatile uint32_t *sdram = (volatile uint32_t *)SDRAM_BASE;

// Warning: the runtime application itself executes from this SDRAM window.
// Direct raw accesses are only safe when you control placement.

// Safe pattern: use linker-placed buffers or a reserved scratch area.
extern volatile uint32_t g_sdram_test_scratch_words[];
g_sdram_test_scratch_words[0] = 0xDEADBEEF;

// Read it back
uint32_t val = g_sdram_test_scratch_words[0];

// Basic scratch-area memory test
void sdram_test(void) {
    uint32_t i, errors = 0;
    // Write pattern
    for (i = 0; i < 1024; i++) g_sdram_test_scratch_words[i] = i ^ 0xA5A5A5A5;
    // Verify
    for (i = 0; i < 1024; i++) {
        if (g_sdram_test_scratch_words[i] != (i ^ 0xA5A5A5A5)) errors++;
    }
    // errors == 0 -> scratch area is behaving correctly without corrupting the runtime image
}
```

**Limitations**:
- **No native SDRAM byte masking**: `DQM=GND` on PCB, so sub-word writes are emulated in `wb_sdram_litedram` with read-modify-write cycles instead of true masked writes
- **Single-word bursts**: BL=1; no burst transfers (can be extended by changing MODE_REG)
- **Auto-precharge**: row closes after every access; no open-row optimization

**SDRAM Physical Pins** (from `colorlight_i9.lpf`):
- `sdram_clk` → B9, `sdram_ras_n` → B10, `sdram_cas_n` → A9, `sdram_we_n` → A10
- `sdram_ba[1:0]` → C8, B11
- `sdram_a[10:0]` → B12, A11..A13, A14, B15, B16, A17, A16, C14, B13
- `sdram_dq[31:0]` → 32 pins (see `colorlight_i9.lpf` for full list)

---

### 6. `wb_i2c.sv` – I2C Master Controller

**Purpose**: Wishbone B.4 (32-bit) wrapper around Alex Forencich's `i2c_master_wbs_16` core, providing a memory-mapped I2C master with hardware FIFOs.

**Based On**: [Verilog I2C IP by Alex Forencich](https://github.com/alexforencich/verilog-i2c) (MIT licence).

**Address**: `0x10005000` (registers at 4-byte stride)

**Register Map**:

| Offset | Name | R/W | Bits |
|---|---|-----|---|
| 0x00 | STATUS | R/W | `[0]`=busy `[1]`=bus_ctrl `[2]`=bus_act `[3]`=miss_ack (W1C), `[15:8]` FIFO summary |
| 0x04 | COMMAND | R/W | `[6:0]`=addr `[8]`=start `[9]`=read `[10]`=write `[11]`=write_mult `[12]`=stop |
| 0x08 | DATA | R/W | `[7:0]`=data `[8]`=data_valid `[9]`=data_last |
| 0x0C | PRESCALE | R/W | `prescale[15:0]`, with `prescale = Fclk / (FI2C × 4)` |

**Parameters**:

```systemverilog
parameter [31:0] ADDR             = 32'h1000_5000;
parameter [15:0] DEFAULT_PRESCALE = 16'd62;    // 100 kHz @ 25 MHz
parameter        CMD_FIFO_DEPTH   = 32;
parameter        WRITE_FIFO_DEPTH = 32;
parameter        READ_FIFO_DEPTH  = 32;
```

**Features**:
- Hardware command, TX, and RX FIFOs (32 entries each)
- Arbitrarily large transfers: CPU stalls on FIFO-full, hardware drains at I2C speed
- Open-drain SCL/SDA with tristate logic (`_t` signals from the i2c_master core)
- `miss_ack` sticky flag if a slave does not acknowledge

**Usage Example** (via `i2c.h` driver):

```cpp
#include "i2c.h"

I2c wire;

// Initialize at 400 kHz
wire.begin(25000000 / (400000 * 4));  // prescale = 15

// Write 2 bytes to 0x3C (SSD1306 command: DISPLAY_ON)
uint8_t buf[] = { 0x00, 0xAF };
wire.write(0x3C, buf, 2);
```

**Hardware Pins** (Colorlight i9, external 4.7 kΩ pullup to 3.3 V required):
- `i2c0_scl` → D18
- `i2c0_sda` → D17

---

### 7. `wb_nodenet.sv` – NodeNet485 Multi-Node RS-485 with MMIO Mailboxes

**Purpose**: Wishbone B.4 slave implementing NodeNet485 over RS-485 @ 1 Mb/s with a mailbox-style register interface.

**Address**: `0x10006000–0x1000601B` (7 registers)

**Important**: The current `wb_nodenet.sv` implementation does **not** access external SDRAM. TX/RX buffering is internal to the module and exposed via MMIO registers.

**UART Layer**:
- `wb_nodenet` uses `uart_simple` directly for byte-level UART RX/TX.
- `wb_nodenet` does not depend on `wb_uart`.

**Register Map**:

| Offset | Name | R/W | Purpose |
|---|---|-----|---|
| 0x00 | TX_CMD | R/W | `[dst(31:24) | len(15:0)]` |
| 0x04 | TX_DATA | R/W | Write payload bytes / read load count |
| 0x08 | RX_HDR | R | `[src(31:24) | dst(23:16) | rx_valid(15) | len(11:0)]` |
| 0x0C | RX_DATA | R | Read next received payload byte |
| 0x10 | CONFIG | R/W | `[hb_interval(31:10) | reserved(9:8) | addr(7:0)]` |
| 0x14 | CONTROL | W | `bit0=trigger_tx bit1=clear_rx bit2=queue_heartbeat` |
| 0x18 | STATUS | R | TX/RX state flags and sticky errors |

**Mailbox Capacity**:
- One staged TX message
- One staged RX message
- Maximum payload length: 2048 bytes

**Hardware Pins**:
- RX: G5 (input from RS-485 transceiver)
- TX: D16 (output to RS-485 transceiver)
- Driver Enable: automatic via transceiver module

For full protocol details, state machines, and firmware API usage, see [README_NODENET.md](README_NODENET.md).

---

## Wishbone Interconnect Integration

All modules are instantiated in [../top.sv](../top.sv) with address decoding:

```systemverilog
// Address ranges
always_comb begin
    wb_rom_sel    = wb_cyc && wb_stb && (wb_adr[31:16] == 16'h0000);
    wb_ram_sel    = wb_cyc && wb_stb && (wb_adr[31:16] == 16'h0001);
    wb_led_d2_sel = wb_cyc && wb_stb && (wb_adr == 32'h1000_0000);
    wb_led0_sel   = wb_cyc && wb_stb && (wb_adr == 32'h1000_0004);
    wb_led1_sel   = wb_cyc && wb_stb && (wb_adr == 32'h1000_0008);
    wb_uart1_sel  = wb_cyc && wb_stb && (wb_adr[31:12] == 20'h10004);
    wb_i2c0_sel   = wb_cyc && wb_stb && (wb_adr[31:12] == 20'h10005);
    wb_nodenet_sel = wb_cyc && wb_stb && (wb_adr[31:12] == 20'h10006);
    wb_flash_sel  = wb_cyc && wb_stb && (wb_adr[31:12] == 20'h10007);
    wb_sdram_sel  = wb_cyc && wb_stb && (wb_adr[31:23] == 9'h040);
end

// Data multiplexer
assign wb_dat_i = rom_ack     ? rom_dat     :
                  ram_ack     ? ram_dat     :
                  nodenet_ack ? nodenet_dat :
                  i2c0_ack    ? i2c0_dat    :
                  flash_ack   ? flash_dat   :
                  led_d2_ack  ? led_d2_dat  :
                  led0_ack    ? led0_dat    :
                  led1_ack    ? led1_dat    :
                                    uart1_ack   ? uart1_dat   :
                  sdram_ack   ? sdram_dat   :
                  32'h0;

// Ack multiplexer
assign wb_ack = rom_ack | ram_ack | led_d2_ack | led0_ack | led1_ack |
                                uart1_ack | nodenet_ack | i2c0_ack | flash_ack | sdram_ack;
```

---

## Design Patterns

### Full/Empty Detection (FIFO)

```systemverilog
wire fifo_empty = (read_ptr == write_ptr);
wire fifo_full  = ((write_ptr + 1) == read_ptr);
```

### Circular Pointer Wrap

```systemverilog
wire [ADDR_WIDTH:0] next_write_ptr = write_ptr + 1;
wire [ADDR_WIDTH:0] next_read_ptr  = read_ptr + 1;
// Auto-wrap on overflow (ADDR_WIDTH+1 bits allows MSB wrap)
```

### Byte-Enable Masking

```systemverilog
wire [31:0] write_data_masked = {
    wb_sel_i[3] ? wb_dat_o[31:24] : mem[addr][31:24],
    wb_sel_i[2] ? wb_dat_o[23:16] : mem[addr][23:16],
    wb_sel_i[1] ? wb_dat_o[15:8]  : mem[addr][15:8],
    wb_sel_i[0] ? wb_dat_o[7:0]   : mem[addr][7:0]
};
```

---

## Extending the SoC

To add a new Wishbone peripheral:

1. **Create module** (`wb_mydevice.sv`) with standard Wishbone interface
2. **Assign address range** in [../top.sv](../top.sv) address decoder
3. **Instantiate** the module with appropriate address and parameters
4. **Add data/ack** to multiplexers
5. **Update documentation** (this file) and firmware headers

Example:

```systemverilog
// New SPI device at 0x1000_2000
parameter SPI_ADDR = 32'h1000_2000;

wb_spi spi_inst (
    .clk(clk),
    .rst(rst),
    .wb_adr_i(wb_adr_i[3:0]),  // Decode lower bits
    .wb_dat_o(wb_spi_data),
    .wb_dat_i(wb_dat_o),
    .wb_we_i(wb_we_i),
    .wb_ack_o(wb_spi_ack),
    .wb_sel_i(wb_sel_i)
);
```

---

## References

- [Wishbone B.4 Specification](https://cdn.opencores.org/downloads/wbspec_b4.pdf)
- [RISC-V Privileged Architecture](https://riscv.org/specifications/)
- [SystemVerilog Language Reference](https://ieee1800.org/)

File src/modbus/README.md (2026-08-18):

# Modbus RTU Master (Wishbone)

This directory contains the UART1 Modbus RTU master peripheral used by the top-level SoC.

## Module

- `wb_modbus_master.sv`
  - Wishbone B.4 slave at UART1 address window (`0x10004000` in current top mapping)
  - Uses `src/wbDevices/uart_simple.sv` for wire-level UART
  - Hardware-managed:
    - Modbus RTU TX frame generation
    - CRC16 (TX generation and RX validation)
    - End-of-frame detection using inter-frame silence
    - Timeout and retry handling

## Register map (word offsets)

- `+0x00` CONTROL
- `+0x04` STATUS
- `+0x08` UART_DIV
- `+0x0C` SLAVE_FUNC
- `+0x10` TIMEOUT_CYCLES
- `+0x14` INTERFRAME_CYCLES
- `+0x18` RETRY_MAX
- `+0x1C` TX_LEN
- `+0x20` TX_DATA
- `+0x24` RX_LEN
- `+0x28` RX_DATA
- `+0x2C` DEBUG (CRC)

## Firmware driver

The paired firmware API lives in:

- `src/firmware/lib/modbus/ModbusMaster.h`
- `src/firmware/lib/modbus/ModbusMaster.cpp`

Typical usage from firmware:

- `begin(baud, timeout_ms, retries)`
- `setInterframeCharsQ1(chars_q1)`
- `readHoldingRegisters(...)`
- `writeSingleCoil(...)`

## Notes

- Discovery mode for Waveshare modules is supported in firmware by querying `0x4000` using slave address `0`.
- Response source address check is relaxed for slave `0` requests to allow vendor discovery behavior.

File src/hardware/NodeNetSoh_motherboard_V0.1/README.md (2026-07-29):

# NodeNetSoh Motherboard V0.1

This document is the working baseline for the KiCad 10 motherboard design.

## Goals

- Host the Colorlight i9 based NodeNet SoC system
- Provide robust field I/O for NodeNet RS-485 network
- Reserve expansion paths for future SPI LCD (ST7789) and KNX (NCN5120)
- Keep bring-up simple with clear test points and debug headers

## Design Scope (V0.1)

- Power input and regulation strategy
- SoC connectivity and service/debug connectors
- Main SoC connector: 200-pin DDR2 SODIMM socket for Colorlight i9 module
- RS-485 physical layer and connector strategy
- Ethernet breakout for both onboard Broadcom PHYs (2 ports)
- I2C expansion header for OLED/sensors
- On-board temperature monitor: TMP117 on I2C bus
- SPI expansion header for display/peripherals
- ESP32 module interface over SPI (web API/MQTT coprocessor)
- Audible status peripheral: PKLCS1212E4001-R1 buzzer support
- Optional KNX transceiver footprint reservation

## Main Connector Requirement (Priority #1)

- Connector type: SODIMM DDR2, 200 pins
- Manufacturer reference: TE Connectivity 1473149-4
- Mechanical behavior: 25-degree insertion, module then lays flat in locked position
- Project rule: motherboard placement and keepout must be defined around this connector first

KiCad implementation notes:
- Use an exact footprint matching TE 1473149-4 dimensions and pad geometry
- Verify key notch and pin-1 orientation against Colorlight i9 module orientation
- Keep insertion/extraction clearance free of tall components in front of the socket
- Add mechanical keepout for latch movement and module overhang zone
- Add at least two mechanical fiducials near the connector area for assembly alignment

## First-Pass Block Diagram

- Power In -> Protection -> DC/DC or LDO rails -> Loads
- Colorlight i9 headers -> motherboard interconnect
- UART/NodeNet -> RS-485 transceiver(s) -> field connector(s)
- I2C bus -> local/peripheral headers
- SPI bus -> display/peripheral headers
- Optional KNX interface path -> NCN5120 domain

## Recommended Rail Planning

- 12V bus input rail from NodeNet RJ45
- 5V rail generated from 12V (Colorlight i9 supply)
- 3.3V rail generated from 12V (logic, transceivers, peripherals)
- Any additional rails required by daughter modules
- Per-rail current budget with at least 30% headroom

Proposed NodeNet power chain (based on current field-proven design):
- RJ45 bus power input: 12V on pins 1-2
- Protection/input stage right after RJ45:
	- Resettable fuse: MF-LSMF185X-2
	- TVS diode: SMBJ15A
	- High-side P-MOS: AO3407A with 100k gate pull-down to GND
	- Bulk capacitor: 100 uF
	- High-frequency decoupling: 100 nF
- Resulting rail after this stage: 12V_CARD
- DC/DC stage #1: LM2596S-based buck module (12V -> 5V)
- Resulting rail after buck #1: 5V_CARD
- DC/DC stage #2: LM2596S-based buck module (12V -> 3.3V), optional if not sourced by ESP32 module
- Resulting rail after buck #2: 3V3_CARD (or 3V3 from ESP32 module regulator, if current budget allows)

Notes:
- This is a good baseline to reuse for NodeNet SoC motherboard V0.1.
- Keep the protection stage physically close to RJ45 input.
- Verify both buck modules thermal margin at expected continuous current.
- Add dedicated test points for 12V_CARD, 5V_CARD, and 3V3_CARD.
- If using ESP32 module 3.3V output, validate total 3V3 load headroom and ripple before removing dedicated 12V->3.3V buck.

## Connector Planning

- Field bus connector(s): 2x RJ45 daisy-chain (IN/OUT), same 8-pin mapping on both ports
- Ethernet connector(s): dual RJ45 with integrated magnetics (one per onboard PHY)
- RJ45 LED lines (typically 2 LEDs per RJ45): route and expose for firmware-controlled blink/status
- Service UART connector: TX/RX/GND labeling and orientation
- I2C header: 3V3, GND, SCL, SDA with pull-up policy
- SPI header: SCK, MOSI, MISO, CS, D/C, RST, BL, power pins (for TFT path)
- SWD/JTAG/program headers as needed for test and recovery

Ethernet implementation notes:
- Route both i9 Broadcom PHY interfaces to two Ethernet ports
- Prefer dual-port MagJack footprint (with integrated transformers and LED pins)
- Keep PHY differential pairs length-matched and impedance-controlled
- Add ESD protection and proper Bob Smith termination network per magnetics reference design
- Reserve/control LED signals for link/activity/status blinking policy

NodeNet RJ45 mapping (both connectors):

| RJ45 Pin | Function |
|---|---|
| 1 | +12V |
| 2 | +12V |
| 3 | RS485 A |
| 4 | GND |
| 5 | GND |
| 6 | RS485 B |
| 7 | GND |
| 8 | GND |

Implementation notes:
- RJ45 IN and RJ45 OUT are wired pin-to-pin for bus/power chaining
- Keep RS485 A/B as a controlled differential pair on the PCB
- Use wide copper for +12V and solid return paths for GND pins (4,5,7,8)
- Add input protection for the 12V rail and ESD protection on external lines

## NodeNet RS485 Front-End (Planned)

- 2x RJ45 daisy-chain connectors (IN/OUT)
- 1x RS485 transceiver module for NodeNet bus interface
- 1x 120R termination resistor switched by 74LVC1G66GW,125

Termination control concept:
- The 120R termination is enabled/disabled by an analog switch (74LVC1G66GW,125)
- Control signal comes from a dedicated GPIO bit exposed through `wb_gpio`
- Default state at reset should be termination disabled (safe for mid-bus nodes)
- End-of-line nodes can enable termination through firmware configuration

Suggested firmware-visible control:
- Reserve one `wb_gpio` output bit for `NODENET_TERM_EN`
- Document polarity explicitly in schematic and firmware headers

## Modbus RS485 Front-End (V1 Plan)

- Start V1 with 4x RS485 modules already available
- Route each RS485 channel directly to dedicated A/B/GND field connectors
- Keep per-channel silkscreen labeling explicit to reduce installation errors

Design note:
- The current RS485 modules are acceptable for bring-up.
- Plan a later upgrade to a more robust 1 Mb/s-capable transceiver for both Modbus and NodeNet.

## Layout Rules (starting point)

- Keep power path short and wide
- Place decoupling caps near every IC supply pin
- Isolate noisy switching sections from analog/sensitive traces
- Keep differential/field interfaces away from high-edge clock areas
- Reserve test points for all main rails and critical buses

## Bring-Up Checklist

- [ ] ERC clean on schematic
- [ ] Power tree reviewed and current budget checked
- [ ] 12V input protection stage implemented (fuse + TVS + AO3407A + 100uF + 100nF)
- [ ] Buck #1 LM2596 12V->5V validated under expected load and temperature
- [ ] 3.3V source selected: dedicated LM2596 buck or ESP32 module regulator output
- [ ] 3.3V rail validated at worst-case current (voltage drop, ripple, temperature)
- [ ] SODIMM 200 footprint checked against TE 1473149-4 drawing
- [ ] 25-degree insertion clearance validated in PCB mechanical view
- [ ] Pin-by-pin validation against i9 SODIMM map for every connected net
- [ ] RS485 120R termination switching validated (74LVC1G66 + GPIO control)
- [ ] Direct RS485 connector polarity and labeling validated (A/B/GND per channel)
- [ ] Net classes defined (power, logic, bus)
- [ ] PCB constraints configured (clearance, widths, vias)
- [ ] DRC clean on layout
- [ ] Manufacturing outputs generated and reviewed
- [ ] Initial power-on checklist prepared

## Future Hooks (already planned in repo)

- [ ] Dual Ethernet ports using i9 onboard Broadcom PHYs (dual RJ45 MagJack)
- [ ] RJ45 LED support (link/activity/status, typically 2 LEDs per RJ45)
- [ ] Firmware LED policy for RJ45 indicators (blink patterns and diagnostics)
- [ ] ESP32 module over SPI (web API/MQTT bridge)
- [ ] SPI LCD ST7789 module integration path
- [ ] Display option validation: OLED over I2C or LCD over SPI
- [ ] KNX interface with NCN5120 transceiver module
- [ ] Buzzer output support for PKLCS1212E4001-R1 (tone/alarm/status)
- [ ] `wb_gpiopwm` peripheral for buzzer PWM/tone generation
- [ ] Firmware driver/API for `wb_gpiopwm` (beep patterns and alerts)
- [ ] TMP117 sensor integration on I2C (board temperature monitoring)
- [ ] Firmware TMP117 driver/API (read temperature, limits, alarms)

## Next Practical Step

Create the schematic power sheet first, then top-level connectors and bus naming. After that, place transceivers and protection circuits.

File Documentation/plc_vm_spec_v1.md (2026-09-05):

# PLC VM V1 Specification

## Purpose

This document defines a first technical specification for a PLC virtual machine
integrated into the NodeNet-SoC-RiscV platform.

The target architecture is:

- PicoRV32 remains the system orchestrator.
- A dedicated `plc_vm` HDL module executes PLC bytecode.
- SDRAM becomes a shared runtime memory accessible by the CPU and by `plc_vm`.
- The CPU loads configurations, resolves point references, links programs, loads
  bytecode into SDRAM, starts program execution, and monitors runtime state.

This V1 specification is intentionally constrained to keep the first hardware
implementation deterministic and debuggable.

## Goals

- Allow the CPU and `plc_vm` to access the same SDRAM address space.
- Define a stable binary ABI for PLC runtime data that does not depend on C++
  firmware structure layout.
- Support PLC program execution from bytecode generated by a PC toolchain.
- Support `float32` transport in the V1 contract, with ordered comparisons
  available before full float arithmetic is introduced.
- Support multiple PLC programs executing concurrently in V1.
- Allow the CPU to perform a link phase from symbolic point identifiers to
  runtime point indices before loading a program onto `plc_vm`.

## Non-Goals For V1

- Direct execution of C++ `PointCatalog` or `PointState` in hardware.
- Dynamic memory allocation inside `plc_vm`.
- String processing inside the VM runtime.
- JIT compilation or self-modifying code.
- Fully general multi-master cache coherency.

## Current Repository Baseline And Step 2 Freeze

Repository baseline today:

- the current merged state is `PLC Ready with V0 basic ISA`
- the runtime ABI, loader, and firmware-managed validation path already exist
- the current branch extends the executed subset to typed 32-bit scalar
  transport and arithmetic without changing the relocation model

For `plc_vm step 2`, this specification should be interpreted as two layers:

- `implemented step 2 core`: the validated execution subset available in the
  repository now
- `reserved V1 families`: float arithmetic and heavier execution families that
  remain part of the long-term contract but may be implemented later

The step 2 priority is therefore to remove ambiguity from the execution model
and the core instruction contract before expanding the HDL surface.

## Architecture Overview

The architecture is split into four layers:

1. `Shared SDRAM fabric`
2. `PLC runtime ABI`
3. `plc_vm` execution engine
4. `CPU-side loader/linker/orchestrator`

### High-Level Roles

- `PicoRV32`
  - owns flash/config/network management
  - owns point definition management
  - resolves point names to runtime indices
  - loads and links programs
  - starts and stops program slots
  - supervises diagnostics and fault reporting

- `plc_vm`
  - fetches and executes PLC bytecode from SDRAM
  - reads point values from the PLC runtime store
  - writes output values back to the PLC runtime store
  - maintains per-program execution state
  - reports faults and execution status through MMIO and SDRAM control blocks

## 1. Shared SDRAM Architecture

### 1.1 Functional Requirements

- The CPU and `plc_vm` shall see the same SDRAM address map.
- Both masters shall be able to read and write SDRAM.
- Accesses shall be arbitrated in hardware.
- The system shall preserve correctness under alternating accesses from CPU and
  `plc_vm`.
- The architecture shall support future addition of other masters without
  changing the PLC ABI.

### 1.2 Interconnect Requirements

- The current single-master CPU-to-SDRAM path shall evolve into a multi-master
  SDRAM access path.
- V1 shall support at least `2` masters:
  - `picorv32_wb`
  - `plc_vm`
- The arbitration policy shall be documented and deterministic.
- The V1 arbitration policy is `round-robin` with no permanently preferred
  master.
- The first implementation should grant at most one completed transaction per
  arbitration turn before rotating to the next requesting master.

Rationale:

- CPU-side point publication and control traffic are considered as important as
  PLC-side point consumption and execution traffic.
- Avoiding fixed priority removes one extra suspect when debugging system-level
  stalls or starvation.

### 1.3 Addressing Rules

- All masters shall use the same physical SDRAM base address.
- The PLC runtime layout shall be defined by fixed regions.
- The PLC runtime ABI shall not depend on the in-memory layout of firmware C++
  objects.

### 1.4 Recommended SDRAM Layout

The following layout is proposed inside the SDRAM window starting at
`0x2000_0000`.

| Region | Start | Size | Purpose |
| --- | --- | --- | --- |
| General firmware workspace | `0x2000_0000` | `64 KB` | CPU-only generic use |
| PLC bytecode area | `0x2001_0000` | `256 KB` | Program images for all slots |
| PLC descriptor table | `0x2005_0000` | `64 KB` | Stable point metadata |
| PLC value table | `0x2006_0000` | `64 KB` | Scalar point values |
| PLC status table | `0x2007_0000` | `64 KB` | Quality, timestamps, flags |
| Program control blocks | `0x2008_0000` | `64 KB` | Per-slot configuration and status |
| Program work area | `0x2009_0000` | `256 KB` | Per-slot stacks, timers, scratch |
| Trace and diagnostics | `0x200D_0000` | `64 KB` | Runtime traces and fault logs |

Sizes may be tuned later, but the region identities shall remain versioned.

### 1.5 Concurrency Model

V1 shall use a simple shared-memory model:

- The CPU performs load/link/configuration operations while a target program
  slot is stopped.
- A running program slot reads inputs and commits outputs through the PLC ABI.
- The CPU may inspect runtime state while programs are running.
- The CPU shall not patch active bytecode in place for a running slot.

Recommended rule for V1:

- program image update requires the target slot to be stopped
- descriptor table rebuild requires all slots to be stopped
- value/status table reads are allowed while running
- value/status writes from CPU during runtime are restricted to maintenance or
  explicit control paths

Behavior under prolonged simultaneous accesses:

- if CPU and `plc_vm` both request SDRAM continuously, the fabric shall keep
  forward progress for both masters
- no master shall starve another master under sustained load
- the first V1 target is fairness and correctness, not maximum throughput
- if throughput tuning becomes necessary later, it shall preserve the same
  observable software contract

### 1.6 Synchronization Primitives

The following minimum synchronization primitives shall exist:

- per-slot `RUN/STOP/RESET` control bits
- per-slot `CONFIG_VALID` status bit
- per-slot `FAULT` status bit
- per-slot `SCAN_DONE` latched bit
- per-slot `heartbeat/cycle_counter`
- optional global `STORE_EPOCH` counter incremented on descriptor rebuild

### 1.7 Design Constraint

V1 should keep the SDRAM sharing model simple.

The preferred approach is:

- shared SDRAM transport
- stable ABI over that transport
- no attempt to expose raw firmware structures to HDL

## 2. PLC Runtime ABI V1

### 2.1 Design Principles

- All runtime point access from `plc_vm` shall be index-based.
- Runtime indices shall be stable for the duration of a loaded PLC runtime.
- Symbolic names shall be resolved by the CPU before program start.
- The ABI shall be versioned.
- The ABI shall use fixed-size binary records.

### 2.2 Supported Value Types In V1

V1 shall support the following types inside `plc_vm`:

- `bool`
- `uint16`
- `int16`
- `uint32`
- `int32`
- `float32`

Strings are not supported inside `plc_vm` V1.

Implementation priority for the current freeze:

- the runtime ABI keeps the full scalar catalog above
- the current execution core supports `bool`, `int16`, `uint32`, `int32`, and
  `float32` stack values
- `LOAD_I16` and `STORE_I16` currently accept shared descriptors tagged as
  either `uint16` or `int16`
- `PUSH_U32`, `PUSH_I32`, `PUSH_F32`, `LOAD_U32`, `STORE_U32`, `LOAD_I32`,
  `STORE_I32`, `LOAD_F32`, and `STORE_F32` are implemented end-to-end in the
  assembler, loader, and `plc_vm`
- `ADD`, `SUB`, `LT`, `LE`, `GT`, `GE`, `MIN`, `MAX`, and `CLAMP` are
  polymorphic for same-type `int16`, `uint32`, and `int32` operands
- `FEQ`, `FNE`, `FLT`, `FLE`, `FGT`, and `FGE` are implemented as ordered
  `float32` comparisons on raw IEEE-754 single-precision values
- `FADD`, `FSUB`, `FMUL`, and `FDIV` are implemented through the multi-cycle float unit
- int/float numeric conversions remain reserved for a later float-unit integration

Current Stage 4 extension on top of the frozen core:

- ordered integer comparisons `LT`, `LE`, `GT`, `GE`
- integer selection helpers `MIN`, `MAX`, `CLAMP`
- stack selection helper `SEL` with a boolean condition at top of stack

### 2.3 Point Descriptor Table

Each runtime point shall have one stable descriptor entry.

Suggested C layout:

```c
struct PlcPointDescriptorV1 {
    uint16_t point_index;
    uint8_t value_type;
    uint8_t flags;
    uint32_t value_offset;
    uint32_t status_offset;
    uint32_t reserved0;
    uint32_t reserved1;
};
```

#### Descriptor Flags

- bit `0`: readable
- bit `1`: writable
- bit `2`: input point
- bit `3`: output point
- bit `4`: internal point
- bit `5`: float point
- bit `6`: descriptor addresses a shared `PointState` record
- bit `7`: reserved

When bit `6` is set:

- `value_offset` is the byte offset of the owning `PointState` record from `SDRAM_POINT_STATE_BASE`
- `status_offset` is unused and shall be `0`

### 2.4 Point Value Table

Values shall be stored in fixed-size slots.

Suggested C layout:

```c
struct PlcPointValueV1 {
    uint32_t raw0;
    uint32_t raw1;
};
```

Encoding rules:

- `bool`, `uint16`, `int16`, `uint32`, `int32` use `raw0`
- `float32` uses IEEE-754 binary32 in `raw0`
- `raw1` is reserved for future use or widened types

### 2.5 Point Status Table

Suggested C layout:

```c
struct PlcPointStatusV1 {
    uint32_t quality;
    uint32_t last_update_ms;
    uint32_t last_writer;
    uint32_t flags;
};
```

Suggested `last_writer` values:

- `0`: unknown
- `1`: CPU
- `2`: PLC VM
- `3`: fieldbus poller
- `4+`: reserved

### 2.6 ABI Version Header

Suggested C layout:

```c
struct PlcRuntimeHeaderV1 {
    uint32_t magic;
    uint16_t version;
    uint16_t flags;
    uint32_t descriptor_count;
    uint32_t descriptor_base;
    uint32_t value_base;
    uint32_t status_base;
    uint32_t store_epoch;
};
```

The CPU shall populate this header before any slot is started.

Suggested `flags` bits:

- bit `0`: shared runtime write queue available at `kPlcRuntimeWriteQueueBase`

### 2.7 Optional Runtime Write Queue

To avoid rescanning the full runtime point table when the PLC VM writes only a
small subset of points, the shared SDRAM ABI may expose a fixed-size ring queue
of runtime point indices.

Suggested C layout:

```c
struct PlcRuntimeWriteQueueV1 {
    uint32_t head;
    uint32_t tail;
    uint32_t overflow_count;
  uint32_t indices[384];
};
```

Suggested behavior:

- the queue lives in a dedicated SDRAM window owned by the runtime ABI
- the VM pushes a runtime `point_index` after publishing a point value/status
- the CPU pops queued indices and applies only those writes
- `overflow_count` increments when the producer cannot enqueue because the ring
  is full
- on overflow, writes may be dropped until the producer/consumer contract is restored

Producer ordering requirement:

- the VM shall write `value`, then `status`, then enqueue the runtime index
- `status.last_writer` shall be set to `PLC VM` before the enqueue becomes
  visible to the CPU
- the VM should enqueue a point only once while `status.last_writer` still
  equals `PLC VM`; repeated writes shall update the same runtime slot without
  duplicating queue entries

## 3. CPU Link Phase

### 3.1 Rationale

PLC source programs are expected to reference symbolic points such as:

- device identifier
- feature identifier
- point identifier

The VM shall not resolve those strings at runtime.

Instead, the CPU shall perform a link step before loading the program to a VM
slot.
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

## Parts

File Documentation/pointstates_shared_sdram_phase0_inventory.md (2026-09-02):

# PointStates Shared SDRAM Phase 0 Inventory

## Goal

This document freezes the current firmware contract before the shared-SDRAM
simplification starts.

It answers one concrete question:

Where does runtime point state live today, and which helpers still maintain a
second state surface that Stage 11 should remove before arithmetic expansion?

## Controlling Hypothesis

The current system already stores `PointCatalog` point states in SDRAM.

The migration is therefore not primarily about moving `PointState` out of CPU
RAM.

It is about removing the parallel PLC runtime ABI state surface that currently
duplicates observable point value and status in separate SDRAM windows.

## Authoritative State Today

### 1. PointCatalog State Store

Primary anchor:

- [src/firmware/lib/plc/PointCatalog.cpp](src/firmware/lib/plc/PointCatalog.cpp)

Current facts:

- `PointCatalog::states()` returns `point_state_storage_const()`
- `point_state_storage()` points directly at `SDRAM_POINT_STATE_BASE`
- `sizeof(PointState) * PointCatalog::kMaxPoints` is reserved in the fixed
  point-state SDRAM window

Important functions:

- `PointCatalog::states()`
- `PointCatalog::findState()`
- `PointCatalog::updateState()`
- `PointCatalog::replaceSlotVariableDefinitions()`
- `PointCatalog::clear()`

Current behavior:

- browse/read-state uses this store
- CPU-side point updates land in this store
- builtin PLC slot status points also land in this store

### 2. PointState Shape

Primary anchor:

- [src/firmware/lib/plc/PointCatalog.h](src/firmware/lib/plc/PointCatalog.h)

Supporting type headers:

- `PointState.h`
- `PointDefinition.h`

Phase 0 action item:

- keep the exact `PointState` field layout visible when Phase 1 defines the
  replacement shared record ABI

## Parallel Runtime Surface To Remove

### 3. PLC Runtime ABI Windows

Primary anchor:

- [src/firmware/include/plc_runtime_abi.h](src/firmware/include/plc_runtime_abi.h)

Current fixed windows:

- `kPlcRuntimeDescriptorBase`
- `kPlcRuntimeValueBase`
- `kPlcRuntimeStatusBase`
- `kPlcRuntimeWriteQueueBase`

Current structs:

- `PlcPointDescriptorV1`
- `PlcPointValueV1`
- `PlcPointStatusV1`
- `PlcRuntimeHeaderV1`
- `PlcRuntimeWriteQueueV1`

Why this matters:

- `PlcPointValueV1` duplicates point value information already represented in
  `PointState`
- `PlcPointStatusV1` duplicates point quality and timestamp information already
  represented in `PointState`
- the write queue exists because PLC writes do not update the authoritative
  `PointCatalog` state directly

### 4. CPU -> PLC Republish Path

Primary anchor:

- [src/firmware/include/plc_runtime_abi.h](src/firmware/include/plc_runtime_abi.h)

Controlling helpers:

- `PlcRuntimePublisherV1::publish()`
- `PlcRuntimePublisherV1::rebuildDescriptors()`
- `PlcRuntimePublisherV1::syncValuesAndStatus()`
- `PlcRuntimePublisherV1::syncDirtyValuesAndStatus()`
- `PlcRuntimePublisherV1::syncPointValueAndStatus()`

Current behavior:

- a `PointCatalog` change marks one catalog index dirty
- the runtime publisher converts `PointState` into split ABI value/status views
- the PLC runtime later reads those ABI windows rather than the original
  `PointState` records

Implication:

- this is the active synchronization path that the new architecture wants to delete

### 5. PLC -> CPU Copy-Back Path

Primary anchor:

- [src/firmware/lib/plc/PlcCore.cpp](src/firmware/lib/plc/PlcCore.cpp)

Controlling helpers:

- `PlcCore::consumeRuntimeWrites()`
- `PlcCore::consumeRuntimeWriteIndex()`
- `PlcCore::commitRuntimeBool()`
- `PlcCore::commitRuntimeInt16()`

Current behavior:

- PLC writes do not become authoritative by directly mutating `PointCatalog`
- instead, runtime indices are popped from `PlcRuntimeWriteQueueV1`
- CPU code reads ABI-side value/status records
- CPU code converts those writes back into `PointCatalog` `PointState`
- CPU code then flips `last_writer` away from `kPlcRuntimeWriterPlcVm`

Implication:

- this is the reverse synchronization path that the new architecture wants to delete

## Readers Of The Current Authoritative Store

### 6. NodeNet Browse / Read-State

Primary anchor:

- [src/firmware/lib/nodenetCore/nodenetCore.cpp](src/firmware/lib/nodenetCore/nodenetCore.cpp)

Controlling helper:

- `NodeNetCore::handlePointStatesRequest()`

Current behavior:

- reads `_pointCatalog.states()` directly
- serializes values and quality for `pointStatesRes`
- already uses the `PointCatalog` SDRAM-backed store, not the PLC runtime ABI

Migration implication:

- this path is already conceptually close to the target architecture
- it should become the reference behavior for future PLC-visible state too

### 7. Builtin Point Publication

Primary anchor:

- [src/firmware/lib/nodenetCore/nodenetCore.cpp](src/firmware/lib/nodenetCore/nodenetCore.cpp)

Controlling helpers:

- `NodeNetCore::updatePointState()`
- `NodeNetCore::publishNodePointStates()`
- `NodeNetCore::publishBuiltinPointStates()`
- `NodeNetCore::publishBuiltinPlcPointStates()`

Current behavior:

- builtin node and PLC status points are written into `PointCatalog`
- those writes then trigger runtime dirty tracking and republish toward the PLC ABI

Migration implication:

- these helpers are likely to stay
- their side effect of triggering ABI republish should eventually disappear

## Data Structures That Are Not The Main Problem

These structures may still live in RAM or SDRAM, but they are not the core
duplication problem addressed by this migration:

- `PointCatalog::entries_`
- `PointCatalog::command_states_`
- `PointCatalog::plc_point_meta_`
- browse indexes and lookup tables
- NodeNet input/output JSON message queues

They matter architecturally, but they do not create the current point-state
split-brain on their own.

## Current Write Paths

### CPU-originated writes

Path summary:

1. NodeNet or internal service calls `NodeNetCore::updatePointState()`
2. `NodeNetCore::updatePointState()` calls `PointCatalog::updateState()`
3. `PointCatalog::updateState()` writes `PointState` at `SDRAM_POINT_STATE_BASE`
4. `PointCatalog::markStateDirty()` schedules ABI republish
5. `PlcRuntimePublisherV1::syncDirtyValuesAndStatus()` mirrors the updated
   point into `kPlcRuntimeValueBase` and `kPlcRuntimeStatusBase`

### PLC-originated writes

Path summary:

1. PLC runtime writes ABI value/status windows
2. PLC runtime enqueues the runtime index in `PlcRuntimeWriteQueueV1`
3. `PlcCore::consumeRuntimeWrites()` pops that runtime index
4. `PlcCore::consumeRuntimeWriteIndex()` decodes the ABI-side value/status
5. `PlcCore::commitRuntimeBool()` or `commitRuntimeInt16()` writes back into
   `PointCatalog`

This is the clearest proof that two state surfaces exist today.

## Candidate Deletion Targets

The following helpers are the main candidates for removal or deep redesign once
direct shared point-state access exists on both CPU and PLC sides:

- `PlcRuntimePublisherV1::syncValuesAndStatus()`
- `PlcRuntimePublisherV1::syncDirtyValuesAndStatus()`
- `PlcRuntimePublisherV1::syncPointValueAndStatus()`
- `PlcRuntimeWriteQueueV1`
- `PlcCore::consumeRuntimeWrites()`
- `PlcCore::consumeRuntimeWriteIndex()`

Descriptors may survive longer than value/status mirrors, but they should no
longer imply a second authoritative value/status store.

## Phase 0 Conclusions

Phase 0 closes with these concrete conclusions:

- `PointCatalog` point states are already SDRAM-backed and already serve NodeNet browse/read-state
- the duplicated architecture that should be simplified before Stage 11 is the
  PLC runtime ABI split between `PointState` and `PlcPointValueV1` /
  `PlcPointStatusV1`
- the real migration target is to let PLC and CPU share one state record family
  directly, while keeping catalog/definition logic CPU-managed for now

## Next Step After Phase 0

The next concrete task is Phase 1:

- define the target shared record ABI and the minimal helper layer that both
  CPU and PLC will use instead of the current value/status mirror plus write queue

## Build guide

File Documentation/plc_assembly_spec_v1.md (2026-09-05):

# PLC Assembly V1

## Scope

This document defines the human-readable PLC assembly source used to build
`objectFileV1` artifacts for NodeNet-SoC-RiscV.

It separates three levels clearly:

- syntax already accepted by the current desktop assembler
- object-file and loader contracts already enforced by firmware
- the validated instruction subset currently executed by `plc_vm`
- planned instruction families explicitly reserved for later phases

The goal is to keep source syntax stable while allowing the firmware loader to
resolve symbols to runtime point indices when a slot is loaded.

## Current Status

Repository baseline today:

- the merged project state is `PLC Ready with V0 basic ISA`
- the current assembler and runtime subset is intentionally small and proven on
  the existing firmware-first path

Implemented today:

- `CONST POINT_ID <symbol>, <deviceId.feature.pointId>`
- `PARAM POINT_ID <symbol>`
- `VAR <type> <name>`
- `VAR PUBLIC <type> <name>`
- `VAR PRIVATE <type> <name>`
- `NOP`
- `HALT`
- `PUSH_TRUE`
- `PUSH_FALSE`
- `DUP`
- `DROP`
- `SWAP`
- `LOAD_BOOL <symbol>`
- `STORE_BOOL <symbol>`
- `AND`
- `OR`
- `XOR`
- `NOT`
- `EQ`
- `NE`
- `PUSH_I16 imm16`
- `PUSH_U32 imm32`
- `PUSH_I32 imm32`
- `PUSH_F32 imm32`
- `LOAD_I16 <symbol>`
- `STORE_I16 <symbol>`
- `LOAD_U32 <symbol>`
- `STORE_U32 <symbol>`
- `LOAD_I32 <symbol>`
- `STORE_I32 <symbol>`
- `LOAD_F32 <symbol>`
- `STORE_F32 <symbol>`
- `ADD`
- `SUB`
- `LT`
- `LE`
- `GT`
- `GE`
- `MIN`
- `MAX`
- `CLAMP`
- `SEL`
- `FEQ`
- `FNE`
- `FLT`
- `FLE`
- `FGT`
- `FGE`
- `FADD`
- `FSUB`
- `FMUL`
- `SX_I16_TO_I32`
- `TRUNC_I32_TO_I16`
- `BOOL_TO_U32`
- `BOOL_TO_I32`
- `U32_TO_BOOL`
- `I32_TO_BOOL`
- `INC_INT <symbol>`
- `DEC_INT <symbol>`
- `DB <byte0>, <byte1>, ...`
- aliases `LOAD_POINT_BOOL`, `STORE_POINT_BOOL`, `LB`, `SB`, `INC`, `DEC`

Supported by the firmware loader in this step:

- slot-local variable symbol kind for `VAR` declarations
- automatic mapping of slot-local variables to dynamic local points under
  `deviceId.plc.slotN.<varName>` at slot load time

Step 2 objective for this document:

- freeze one useful and HDL-friendly core ISA
- define one unambiguous stack-based execution model
- classify remaining instruction families as either `step 2 core` or
  `reserved for later`

Reserved for later phases unless explicitly promoted by a follow-up branch:

- timer and event primitives
- float arithmetic and int/float numeric conversions
- additional wide-integer utilities that add hardware cost without immediate bring-up value

## Source File Structure

A PLC assembly source file is split into two logical regions:

1. declarations
2. instructions

Example:

```text
PARAM POINT_ID input
CONST POINT_ID y, gb9fao5yk4f.modbus0.waveshare0.output4
VAR BOOL latch

LOAD_BOOL input
STORE_BOOL latch
LOAD_BOOL latch
STORE_BOOL y
HALT
```

Rules:

- one declaration or instruction per line
- tokens are separated by spaces, tabs, or commas
- comments start with `;` or `#`
- symbol names are case-sensitive within one object file
- mnemonics are case-insensitive

## Value Types

The PLC runtime currently defines these scalar value types:

- `BOOL` -> runtime `PointValueType::Bool`
- `UINT16` -> runtime `PointValueType::Uint16`
- `INT` -> runtime `PointValueType::Int16`
- `UINT32` -> runtime `PointValueType::Uint32`
- `DINT` -> runtime `PointValueType::Int32`
- `FLOAT` -> runtime `PointValueType::Float`
- `ENUM` -> runtime `PointValueType::Enum`

V1 slot-local variables are intentionally restricted to scalar types. Strings are
excluded.

## Step 2 Execution Model

The frozen execution model for `plc_vm step 2` is a typed stack machine.

Rules:

- there is one operand stack per slot
- the top of stack is the only implicit operand source and destination
- there is no separate accumulator in the frozen model
- `LOAD_*` instructions push one typed value on the operand stack
- `STORE_*` instructions consume one typed value from the operand stack and
  stage the write for commit at scan end
- unary operators consume one value and push one result
- binary operators consume the top two values and push one result
- `INC_INT` and `DEC_INT` remain special single-operand memory update
  instructions for the current compact profile
- a stack type mismatch, stack underflow, invalid opcode, or invalid point type
  shall fault the active slot

Step 2 keeps straight-line scan execution only:

- execution starts at bytecode offset `0`
- execution stops on `HALT` or on fault
- relative branches `JMP`, `JZ`, and `JNZ` are implemented
- there is still no call or return instruction in the current core subset

## Step 2 Frozen Core ISA

The recommended frozen core ISA for this branch is:

### Declarations

- `CONST POINT_ID`
- `PARAM POINT_ID`
- `VAR`

### Control

- `NOP`
- `HALT`

### Stack and literals

- `PUSH_TRUE`
- `PUSH_FALSE`
- `PUSH_I16 imm16`
- `PUSH_U32 imm32`
- `PUSH_I32 imm32`
- `PUSH_F32 imm32`
- `DUP`
- `DROP`
- `SWAP`

### Point access

- `LOAD_BOOL <symbol>`
- `STORE_BOOL <symbol>`
- `LOAD_I16 <symbol>`
- `STORE_I16 <symbol>`
- `LOAD_U32 <symbol>`
- `STORE_U32 <symbol>`
- `LOAD_I32 <symbol>`
- `STORE_I32 <symbol>`
- `LOAD_F32 <symbol>`
- `STORE_F32 <symbol>`

### Boolean and integer core

- `AND`
- `OR`
- `XOR`
- `NOT`
- `EQ`
- `NE`
- `ADD`
- `SUB`
- `LT`
- `LE`
- `GT`
- `GE`
- `MIN`
- `MAX`
- `CLAMP`
- `SEL`
- `FEQ`
- `FNE`
- `FLT`
- `FLE`
- `FGT`
- `FGE`
- `SX_I16_TO_I32`
- `TRUNC_I32_TO_I16`
- `BOOL_TO_U32`
- `BOOL_TO_I32`
- `U32_TO_BOOL`
- `I32_TO_BOOL`
- `JMP rel16|label`
- `JZ rel16|label`
- `JNZ rel16|label`
- `R_TRIG <symbol>`
- `F_TRIG <symbol>`
- `INC_INT <symbol>`
- `DEC_INT <symbol>`

Instruction families reserved but not part of the frozen step 2 core:

- `LOAD_U16`, `STORE_U16`
- `NEG`, `ABS`
- `CALL`, `RET`
- timer, counter, and edge primitives
- float arithmetic and int/float conversion families

## Step 2 Core Opcode Contract

This table is the frozen semantic contract for the core subset. Encodings may
still be assigned or refined during implementation, but operand shape, stack
effect, and type behavior should not drift.

| Mnemonic | Operands | Stack effect | Type rules | Fault cases |
| --- | --- | --- | --- | --- |
| `NOP` | none | no change | none | invalid opcode only |
| `HALT` | none | stop scan | none | none |
| `PUSH_TRUE` | none | `... -> ..., bool` | pushes `true` | stack overflow |
| `PUSH_FALSE` | none | `... -> ..., bool` | pushes `false` | stack overflow |
| `PUSH_I16` | `imm16` | `... -> ..., i16` | sign-extended literal | stack overflow |
| `DUP` | none | `..., a -> ..., a, a` | duplicates top value with same type | stack underflow, stack overflow |
| `DROP` | none | `..., a -> ...` | removes top value | stack underflow |
| `SWAP` | none | `..., a, b -> ..., b, a` | preserves both operand types | stack underflow |
| `LOAD_BOOL` | `point symbol` | `... -> ..., bool` | source point must resolve to `BOOL` | unresolved symbol, type mismatch, read fault, stack overflow |
| `STORE_BOOL` | `point symbol` | `..., bool -> ...` | target point must resolve to writable `BOOL` | unresolved symbol, type mismatch, write fault, stack underflow |
| `LOAD_I16` | `point symbol` | `... -> ..., i16` | source point must resolve to `INT` | unresolved symbol, type mismatch, read fault, stack overflow |
| `STORE_I16` | `point symbol` | `..., i16 -> ...` | target point must resolve to writable `INT` | unresolved symbol, type mismatch, write fault, stack underflow |
| `AND` | none | `..., bool, bool -> ..., bool` | boolean only | stack underflow, type mismatch |
| `OR` | none | `..., bool, bool -> ..., bool` | boolean only | stack underflow, type mismatch |
| `XOR` | none | `..., bool, bool -> ..., bool` | boolean only | stack underflow, type mismatch |
| `NOT` | none | `..., bool -> ..., bool` | boolean only | stack underflow, type mismatch |
| `EQ` | none | `..., a, a -> ..., bool` | both operands must have the same scalar type | stack underflow, type mismatch |
| `NE` | none | `..., a, a -> ..., bool` | both operands must have the same scalar type | stack underflow, type mismatch |
| `ADD` | none | `..., i16, i16 -> ..., i16` | `INT` only in the frozen core | stack underflow, type mismatch, arithmetic overflow if trapped |
| `SUB` | none | `..., i16, i16 -> ..., i16` | `INT` only in the frozen core | stack underflow, type mismatch, arithmetic overflow if trapped |
| `LT` | none | `..., i16, i16 -> ..., bool` | signed `INT` compare | stack underflow, type mismatch |
| `LE` | none | `..., i16, i16 -> ..., bool` | signed `INT` compare | stack underflow, type mismatch |
| `GT` | none | `..., i16, i16 -> ..., bool` | signed `INT` compare | stack underflow, type mismatch |
| `GE` | none | `..., i16, i16 -> ..., bool` | signed `INT` compare | stack underflow, type mismatch |
| `MIN` | none | `..., i16, i16 -> ..., i16` | signed `INT` compare/select | stack underflow, type mismatch |
| `MAX` | none | `..., i16, i16 -> ..., i16` | signed `INT` compare/select | stack underflow, type mismatch |
| `CLAMP` | none | `..., value, min, max -> ..., i16` | signed `INT` only | stack underflow, type mismatch |
| `SEL` | none | `..., falseValue, trueValue, bool -> ..., a` | selects between same-typed stack values using top boolean | stack underflow, type mismatch |
| `JMP` | `rel16` or `label` | no stack use | target is relative to the next instruction | invalid target |
| `JZ` | `rel16` or `label` | `..., bool -> ...` | pops a boolean and jumps when it is false | stack underflow, type mismatch, invalid target |
| `JNZ` | `rel16` or `label` | `..., bool -> ...` | pops a boolean and jumps when it is true | stack underflow, type mismatch, invalid target |
| `R_TRIG` | `point symbol` | `... -> ..., bool` | pushes true for one scan on a false-to-true transition of the source `BOOL` point | unresolved symbol, type mismatch, read fault, stack overflow |
| `F_TRIG` | `point symbol` | `... -> ..., bool` | pushes true for one scan on a true-to-false transition of the source `BOOL` point | unresolved symbol, type mismatch, read fault, stack overflow |
| `INC_INT` | `point symbol` | no stack use | point must resolve to writable `INT` | unresolved symbol, type mismatch, write fault |
| `DEC_INT` | `point symbol` | no stack use | point must resolve to writable `INT` | unresolved symbol, type mismatch, write fault |
| `DB` | raw bytes | implementation-defined | bring-up escape hatch only | bypasses source-level type guarantees |

### Labels

Stage 5 introduces local branch labels for control flow:

```text
enabled:
LOAD_BOOL enable
JNZ run
HALT

run:
PUSH_TRUE
STORE_BOOL y
HALT
```

Rules:

- label syntax is `<name>:`
- labels are local to one source file
- valid label characters are ASCII letters, digits, and `_`
- `JMP`, `JZ`, and `JNZ` accept either a signed `rel16` literal or a label

### R_TRIG

Syntax:

```text
R_TRIG <symbol>
```

Behavior:

- reads one `BOOL` point identified by `<symbol>`
- keeps one previous sampled state per slot and per runtime point index
- pushes `true` for exactly one scan when the source transitions from `false` to `true`
- on the first scan after a slot load, it initializes the remembered state and pushes `false`

### F_TRIG

Syntax:

```text
F_TRIG <symbol>
```

Behavior:

- reads one `BOOL` point identified by `<symbol>`
- keeps one previous sampled state per slot and per runtime point index
- pushes `true` for exactly one scan when the source transitions from `true` to `false`
- on the first scan after a slot load, it initializes the remembered state and pushes `false`

## Declarations

### CONST POINT_ID

Syntax:

```text
CONST POINT_ID <symbol>, <deviceId.feature.pointId>
```

Purpose:

- declares a fixed symbolic point reference
- binds a source-level symbol to one exact point path
- produces one symbol-table entry in the object file

Example:

```text
CONST POINT_ID y, gb9fao5yk4f.modbus0.waveshare0.output4
```

Usage notes:

- the assembler stores the full point path in the object symbol record
- the firmware loader resolves that path to a runtime point index at slot load
- instructions never carry the final runtime index in source form

### PARAM POINT_ID

Syntax:

```text
PARAM POINT_ID <symbol>
```

Purpose:

- declares a symbolic point parameter supplied by the host before upload
- allows one program to be reused with different point bindings

Example:

```text
PARAM POINT_ID input
```

Usage notes:

- in the current toolchain, the desktop resolves the parameter to a concrete
  full point path before upload
- the object file therefore still contains a concrete stored `PointIdentity`
- firmware resolves it exactly like a `CONST POINT_ID` during load

### VAR

Reserved source syntax for slot-local exported variables:

```text
VAR <type> <name>
VAR PUBLIC <type> <name>
VAR PRIVATE <type> <name>
```

Examples:

```text
VAR BOOL ready
VAR PUBLIC INT counter
VAR PRIVATE FLOAT filteredPv
```

Purpose:

- declares a slot-local named variable
- the variable is materialized by the firmware loader as a dynamic local point
- visibility defaults to `PUBLIC` when omitted
- the created point identity is:

```text
deviceId.plc.slotN.<name>
```

Examples of generated point paths:

- `gb9fao5yk4f.plc.slot0.ready`
- `gb9fao5yk4f.plc.slot0.counter`
- `gb9fao5yk4f.plc.slot1.filteredPv`

Loader rules for `VAR`:

- creation happens at slot load time, before relocation resolution
- variables are local backend points
- `VAR PUBLIC` variables are created with direction `InOut`
- `VAR PRIVATE` variables are created with direction `Input` for external browse/write purposes
- the owning PLC program may still read and write its own `VAR PRIVATE` symbols internally
- variables are zero-initialized
- variables are not persisted as user catalog configuration
- reloading a slot replaces that slot's previous dynamic variable set

Reserved runtime-owned point names that cannot be reused by `VAR`:

- `loaded`
- `state`
- `runEnabled`
- `status`
- `cycleCounter`
- `faultCode`
- `faultInfo`
- `bytecodeSize`
- `source`
- `programType`
- `paramsSummary`
- `inputChannel`
- `outputChannel`
- `runtimeMapOk`
- `start`
- `stop`
- `reset`
- `clearFault`

Design intent:

- a slot variable is private by ownership but public by observation
- another slot may read it through the normal runtime point model
- this avoids creating a second inter-slot data-sharing mechanism

## Instructions Implemented Today

### HALT

Syntax:

```text
HALT
```

Encoding:

- opcode `0x00`
- no operands

Behavior:

- stops execution of the current scan immediately
- leaves the slot loaded
- acts as the normal end of program for the current boolean VM subset

Example:

```text
HALT
```

### LOAD_BOOL

Syntax:

```text
LOAD_BOOL <symbol>
```

Aliases:

- `LOAD_POINT_BOOL <symbol>`
- `LB <symbol>`

Encoding:

- opcode `0x10`
- one relocated `u16` operand patched to a runtime point index by the loader

Behavior:

- reads one boolean point identified by `<symbol>`
- pushes that boolean onto the operand stack

Source operand rules:

- `<symbol>` must reference one earlier `CONST POINT_ID`, `PARAM POINT_ID`, or
  future `VAR`
- the operand is symbolic in source and becomes an index only after load-time
  relocation

Examples:

```text
LOAD_BOOL input
LB latch
```

### STORE_BOOL

Syntax:

```text
STORE_BOOL <symbol>
```

Aliases:

- `STORE_POINT_BOOL <symbol>`
- `SB <symbol>`

Encoding:

- opcode `0x11`
- one relocated `u16` operand patched to a runtime point index by the loader

Behavior:

- pops one boolean from the operand stack and stages a write to the target
  point for commit at scan end

Source operand rules:

- `<symbol>` must reference one earlier `CONST POINT_ID`, `PARAM POINT_ID`, or
  future `VAR`
- write access is validated by the loader/runtime against the resolved point

Examples:

```text
STORE_BOOL y
SB ready
```

### DB

Syntax:

```text
DB <byte0>, <byte1>, ...
```

Purpose:

- emits raw bytes directly into the code stream
- useful for bring-up, experiments, and temporary opcode probing

Examples:

```text
DB 0x10, 0x00, 0x00
DB 17, 2, 0
```

Usage notes:

- `DB` does not create relocations by itself
- using `DB` for symbolic point operands is discouraged because it bypasses the
  source-level type contract

### INC_INT

Syntax:

```text
INC_INT <symbol>
```

Alias:

- `INC <symbol>`

Encoding:

- opcode `0x20`
- one relocated `u16` operand patched to a runtime point index by the loader

Behavior:

- reads one `INT` point
- increments it by `1`
- writes the new value back to the same point in the same scan

Current V1 restriction:

- the target point must resolve to runtime type `Int16`

### DEC_INT

Syntax:

```text
DEC_INT <symbol>
```

Alias:

- `DEC <symbol>`

Encoding:

- opcode `0x21`
- one relocated `u16` operand patched to a runtime point index by the loader

Behavior:

- reads one `INT` point
- decrements it by `1`
- writes the new value back to the same point in the same scan

Current V1 restriction:

- the target point must resolve to runtime type `Int16`

## Frozen Core And Recommended Expansion Order

The long-term goal remains to migrate PLC execution toward HDL-managed
execution. For `plc_vm step 2`, the most useful roadmap is the one that balances
hardware implementation cost and immediate programming value.

The ranking below assumes a modest HDL engine first:

- single-issue finite-state machine
- one instruction fetch/decode path
- runtime point read/write still exposed through a shared point-indexed memory
  or register interface
- no speculative execution, no deep pipeline, no out-of-order behavior

Current hardware constraint for implementation planning:

- the current FPGA build is already close to BRAM saturation, with DP16KD usage
  around `87%`
- this matters not only for fit margin, but also for build iteration time,
  because `nextpnr-ecp5` routing cost rises sharply near BRAM saturation
- stage ordering should therefore minimize new dedicated memories until the core
  execution contract is proven stable

Practical consequences for `plc_vm step 2`:

- prefer register-based or shallow LUTRAM-based operand stacks for the first
  core profile
- avoid increasing stack depth, timer tables, trace buffers, or per-slot scratch
  RAM before the core ISA is validated
- prefer opcodes that reuse one compact integer/boolean datapath over features
  that require new state memories
- defer timer families, float execution, and large diagnostics buffers unless a
  measured bring-up need justifies the BRAM cost
- when two designs are functionally equivalent, prefer the one that reduces
  DP16KD growth even if it costs a little more control logic or cycles

In that model, "simple" means:

- few source operands
- fixed-width encoding
- no expensive divider, multiplier, or float unit
- no wide comparator trees beyond basic integer compares
- no hidden multi-cycle state beyond explicit state machines

### Stage 1: Foundation And First Useful Writes

Recommended implementation set:

- `NOP`
- `HALT`
- `PUSH_TRUE`
- `PUSH_FALSE`
- `DUP`
- `DROP`
- `SWAP`
- `LOAD_BOOL <symbol>`
- `STORE_BOOL <symbol>`

Why this stage goes first:

- it freezes the stack contract early
- it enables the first real end-to-end validation programs
- it stays close to the already implemented boolean path

Validation programs:

Nominal program, expected result: one scan completes without fault and the
commit phase drives `y = true`.

```text
CONST POINT_ID y, demo.sim.output0

PUSH_TRUE
STORE_BOOL y
HALT
```

Fault program, expected result: the slot faults with stack underflow before any
write is committed.

```text
CONST POINT_ID y, demo.sim.output0

STORE_BOOL y
HALT
```

Stack manipulation program, expected result: one scan completes without fault,
`DUP` preserves one copy of the pushed boolean for `STORE_BOOL`, and `DROP`
empties the stack before `HALT`.

```text
CONST POINT_ID y, demo.sim.output0

PUSH_TRUE
DUP
STORE_BOOL y
DROP
HALT
```

False literal program, expected result: one scan completes without fault and
the commit phase drives `y = false`.

```text
CONST POINT_ID y, demo.sim.output0

PUSH_FALSE
STORE_BOOL y
HALT
```

Read then write program, expected result: one scan completes without fault and
the target output mirrors the current boolean value of the source point.

```text
CONST POINT_ID x, demo.sim.input0
CONST POINT_ID y, demo.sim.output0

LOAD_BOOL x
STORE_BOOL y
HALT
```

Swap program, expected result: one scan completes without fault, `SWAP`
exchanges the top two booleans, and `STORE_BOOL` consumes the swapped top value.

```text
CONST POINT_ID y, demo.sim.output0

PUSH_TRUE
PUSH_FALSE
SWAP
STORE_BOOL y
DROP
HALT
```

Implementation checklist:

- Desktop assembler (`tools/BigSisterNodeNet.Plc`): accept `NOP`, `PUSH_TRUE`,
  `PUSH_FALSE`, `DUP`, `DROP`, `SWAP`; add opcode emission; reject wrong
  operand counts; keep `objectFileV1` relocation rules unchanged for
  `LOAD_BOOL` and `STORE_BOOL`.
- Object file contract: freeze opcode numbers and operand widths for the stage 1
  instructions; ensure raw disassembly can reconstruct the emitted mnemonics.
- Firmware loader (`PlcSlotLoaderV1`): validate that stage 1 images contain only
  accepted stage 1 opcodes when the target execution profile is `core-step2`;
  keep point relocation/type validation for `BOOL` operands.
- Shared ABI contract ([src/firmware/include/plc_runtime_abi.h](src/firmware/include/plc_runtime_abi.h)): confirm boolean point descriptors and write-queue semantics remain sufficient for staged `STORE_BOOL` commits.
- Execution engine (`src/plc/wb_plc.sv` or the firmware validation executor): add
  a typed operand stack, top-of-stack register handling, underflow/overflow
  faults, `NOP`, literal pushes, and simple stack shuffles.
- Validation: assemble the nominal program, load it as `objectFileV1`, run one
  scan, and verify that the target output becomes `true` only after the commit
  phase.
- Validation: assemble the fault program, run one scan, verify the slot stops
  in `FAULT_STACK_UNDERFLOW`, and confirm that the target output is left
  unchanged because no commit is performed.
- Validation: assemble the stack manipulation program, run one scan, verify
  that the target output becomes `true`, and confirm that no fault is raised by
  the `DUP`/`DROP` sequence.
- Validation: assemble the false literal program, run one scan, and verify that
  the target output becomes `false` without raising a fault.
- Validation: assemble the read then write program, run one scan, and verify
  that `LOAD_BOOL` plus `STORE_BOOL` reproduces the source input state at the
  target output.
- Validation: assemble the swap program, run one scan, and verify that the
  committed output matches the swapped top-of-stack value without fault.

Batching note for next work after Stage 1 validation:

- Stage 1 can be treated as closed once the nominal, underflow, `DUP/DROP`,
  `PUSH_FALSE`, `LOAD_BOOL`, and `SWAP` checks all pass on hardware.
- Because HDL build time dominates board-side testing, the next implementation
  batch should group the full boolean ALU slice together: `AND`, `OR`, `XOR`,
  `NOT`, `EQ`, and `NE`.
- Keep the next batch inside one datapath family before moving on to integer
  stack work, so one synthesis cycle buys a meaningful amount of user-visible
  instruction coverage.

### Stage 2: Boolean Logic That Solves Real Wiring Problems

Current branch status:

- assembler/disassembler, firmware loader opcode validation, and `wb_plc`
  execution support are now implemented for this batch
- hardware validation passed for `AND`, `OR`, `XOR`, `NOT`, `EQ`, and `NE`

Recommended implementation set:

- `AND`
- `OR`
- `XOR`
- `NOT`
- `EQ`
- `NE`

Why this stage is high value:

- it already covers interlocks, masks, and simple relay-like logic
- the hardware cost stays low because everything is boolean or equality-based

Validation program:

```text
PARAM POINT_ID start
PARAM POINT_ID enable
CONST POINT_ID y, demo.sim.output0

LOAD_BOOL start
LOAD_BOOL enable
AND
STORE_BOOL y
HALT
```

Validation programs:

AND / OR program, expected result: one scan completes without fault, `and_out`
receives `start AND enable`, and `or_out` receives `start OR enable`.

```text
PARAM POINT_ID start
PARAM POINT_ID enable
CONST POINT_ID and_out, demo.sim.output0
CONST POINT_ID or_out, demo.sim.output1

LOAD_BOOL start
LOAD_BOOL enable
AND
STORE_BOOL and_out

LOAD_BOOL start
LOAD_BOOL enable
OR
STORE_BOOL or_out
HALT
```

XOR / NOT program, expected result: one scan completes without fault,
`xor_out` receives `left XOR right`, and `not_out` receives `NOT left`.

```text
PARAM POINT_ID left
PARAM POINT_ID right
CONST POINT_ID xor_out, demo.sim.output0
CONST POINT_ID not_out, demo.sim.output1

LOAD_BOOL left
LOAD_BOOL right
XOR
STORE_BOOL xor_out

LOAD_BOOL left
NOT
STORE_BOOL not_out
HALT
```

EQ / NE program, expected result: one scan completes without fault, `eq_out`
goes true only when both inputs are equal, and `ne_out` goes true only when
they differ.

```text
PARAM POINT_ID a
PARAM POINT_ID b
CONST POINT_ID eq_out, demo.sim.output0
CONST POINT_ID ne_out, demo.sim.output1

LOAD_BOOL a
LOAD_BOOL b
EQ
STORE_BOOL eq_out

LOAD_BOOL a
LOAD_BOOL b
NE
STORE_BOOL ne_out
HALT
```

Compact hardware validation matrix:

Use the same four input combinations for the three programs above.

| In0 | In1 | `AND` | `OR` | `XOR` | `NOT In0` | `EQ` | `NE` |
| --- | --- | --- | --- | --- | --- | --- | --- |
| `false` | `false` | `false` | `false` | `false` | `true` | `true` | `false` |
| `false` | `true` | `false` | `true` | `true` | `true` | `false` | `true` |
| `true` | `false` | `false` | `true` | `true` | `false` | `false` | `true` |
| `true` | `true` | `true` | `true` | `false` | `false` | `true` | `false` |

Suggested board-side procedure:

- load the AND / OR program and verify both outputs across the four input combinations
- load the XOR / NOT program and verify both outputs across the same four combinations
- load the EQ / NE program and verify the two outputs remain complementary for all four combinations
- if a result is wrong, capture `faultCode`, `faultInfo`, and the committed output states before changing inputs again

Implementation checklist:

- Desktop assembler (`tools/BigSisterNodeNet.Plc`): add mnemonic parsing and
  opcode emission for `AND`, `OR`, `XOR`, `NOT`, `EQ`, `NE`; enforce zero
  explicit operands for these operators.
- Object file contract: document stack-only operand behavior for stage 2
  operators so no hidden accumulator encoding survives in tooling.
- Firmware loader (`PlcSlotLoaderV1`): extend opcode acceptance table; keep
  equality restricted to same-type operands in the frozen core profile.
- Execution engine (`src/plc/wb_plc.sv` or the firmware validation executor):
  implement binary boolean operators and unary `NOT`; emit deterministic faults
  on type mismatch or stack underflow.
- Runtime status/fault reporting: assign stable slot fault codes for invalid
  boolean ALU use so loader and runtime failures are distinguishable.
- Validation: run the AND / OR program and verify the full truth table for both
  outputs across all four input combinations.
- Validation: run the XOR / NOT program and verify `XOR` matches the expected
  two-input truth table while `NOT` inverts the source input.
- Validation: run the EQ / NE program and verify `EQ` and `NE` produce
  complementary outputs for both equal and unequal input states.

### Stage 3: Integer State And Counters

Current branch status:

- assembler/disassembler, firmware loader opcode validation, and `wb_plc`
  execution support are now implemented for `PUSH_I16`, `LOAD_I16`,
  `STORE_I16`, `ADD`, and `SUB`
- the current shared-point-state migration widens `LOAD_I16` and `STORE_I16`
  so they accept both `INT` and `UINT16` point bindings on the same 16-bit path
- hardware validation is still pending for the widened `UINT16` shared-state
  batch

Recommended implementation set:

- `PUSH_I16 imm16`
- `LOAD_I16 <symbol>`
- `STORE_I16 <symbol>`
- `ADD`
- `SUB`
- `INC_INT <symbol>`
- `DEC_INT <symbol>`

Why this stage follows immediately:

- counters and accumulators are among the first useful PLC patterns
- the datapath still fits a compact integer ALU
- it validates typed stack behavior beyond booleans

Validation program:

```text
PARAM POINT_ID inputA
PARAM POINT_ID inputB
VAR INT total

LOAD_I16 inputA
LOAD_I16 inputB
ADD
STORE_I16 total
HALT
```

Note:

- this example is valid only when the upload/build path supplies concrete point
  bindings for `inputA` and `inputB`
- in the current UI/toolchain, `PARAM POINT_ID` declarations are not free
  placeholders; each one must be bound to a full point path before object-file
  build
- for a direct paste-and-compile test without parameter binding, replace the
  two `PARAM POINT_ID` lines with concrete `CONST POINT_ID` declarations

Self-contained validation program for environments with no external `INT`
points:

```text
VAR INT total

PUSH_I16 7
PUSH_I16 5
ADD
STORE_I16 total

LOAD_I16 total
PUSH_I16 2
SUB
STORE_I16 total
HALT
```

Expected result:

- the first arithmetic sequence stores `12` into `total`
- the second sequence reloads `total`, subtracts `2`, and stores `10`
- this one program exercises `PUSH_I16`, `ADD`, `STORE_I16`, `LOAD_I16`, and
  `SUB` without requiring any external mapped `INT` point

Implementation checklist:

- Desktop assembler (`tools/BigSisterNodeNet.Plc`): add `PUSH_I16`, `LOAD_I16`,
  `STORE_I16`, `ADD`, and `SUB`; preserve existing `INC_INT` and `DEC_INT`
  source syntax as direct point-targeted instructions.
- Object file contract: freeze `imm16` encoding, signed interpretation, and the
  exact encoding difference between stack ALU instructions and direct memory
  update instructions.
- Firmware loader (`PlcSlotLoaderV1`): validate `INT` point operands for
  `INC_INT` and `DEC_INT`; validate `INT` or `UINT16` point operands for
  `LOAD_I16` and `STORE_I16`; reject `BOOL`, `ENUM`, and 32-bit bindings in the
  frozen core profile.
- Shared ABI contract ([src/firmware/include/plc_runtime_abi.h](src/firmware/include/plc_runtime_abi.h)): confirm `Int16` load/store paths and queue publication are already sufficient for integer commits.
- Execution engine (`src/plc/wb_plc.sv` or the firmware validation executor):
  add typed integer stack entries, signed add/subtract behavior, and clear
  overflow policy; keep `INC_INT` and `DEC_INT` as specialized read-modify-write
  helpers if that stays cheaper than lowering them to `LOAD/ADD/STORE`.
- Firmware-side runtime application ([src/firmware/lib/plc/PlcCore.cpp](src/firmware/lib/plc/PlcCore.cpp)): reuse `readRuntimeInt16()` and `commitRuntimeInt16()` as the behavioral oracle for bring-up validation.
- Validation: run the sample addition program, then a second program using
  `INC_INT` on a slot-local `VAR INT counter`, and verify the committed value
  increments by exactly one per scan.

### Stage 4: Ordered Compare And Selection Family

Recommended implementation set:

- `LT`
- `LE`
- `GT`
- `GE`
- `MIN`
- `MAX`
- `CLAMP`
- `SEL`

Why this stage is worth doing before control flow:

- threshold alarms and bounded arithmetic are immediately useful
- compares unlock many real PLC decisions without yet needing branches
- hardware cost is still moderate compared with timers or float

Validation program:

```text
PARAM POINT_ID pv
CONST POINT_ID alarm, demo.sim.output1

LOAD_I16 pv
PUSH_I16 80
GE
STORE_BOOL alarm
HALT
```

Implementation checklist:

- Desktop assembler (`tools/BigSisterNodeNet.Plc`): add `LT`, `LE`, `GT`, `GE`,
  `MIN`, `MAX`, `CLAMP`, and `SEL`; define mnemonic signatures now even if a
  subset lands first.
- Object file contract: freeze signedness rules for ordered comparisons and the
  stack signature of `SEL` before HDL work starts.
- Firmware loader (`PlcSlotLoaderV1`): enforce that ordered compare operands use
  the same supported scalar type inside the active execution profile.
- Execution engine (`src/plc/wb_plc.sv` or the firmware validation executor):
  add comparator results as boolean stack values; implement `MIN/MAX/CLAMP` only
  after compare behavior is proven stable.
- Validation sequence: first validate `GE` with the sample threshold program,
  then add dedicated micro-tests for `LT` boundary cases and `CLAMP` saturation
  behavior.

### Stage 5: Control Flow

Recommended implementation set:

- `JMP rel16`
- `JZ rel16`
- `JNZ rel16`
- optionally `CALL rel16` and `RET` in a separate follow-up slice

Why this stage is later:

- it changes the VM structure, not just the ALU surface
- it requires stable branch encoding, offset rules, and fault handling
- many first validation programs can already run without it

Validation program:

```text
PARAM POINT_ID enable
CONST POINT_ID y, demo.sim.output0

LOAD_BOOL enable
JZ disabled
PUSH_TRUE
STORE_BOOL y
HALT

disabled:
PUSH_FALSE
STORE_BOOL y
HALT
```

Implementation checklist:

- Desktop assembler (`tools/BigSisterNodeNet.Plc`): add label parsing, relative
  offset resolution, and relocation-independent branch encoding for `JMP`, `JZ`,
  and `JNZ`.
- Object file contract: freeze branch offset origin, signed range, and whether
  offsets are byte-based or instruction-based.
- Firmware loader (`PlcSlotLoaderV1`): validate branch targets remain inside the
  code section after linking and reject malformed offsets before slot start.
- Execution engine (`src/plc/wb_plc.sv` or the firmware validation executor):
  update `pc` from relative offsets, pop branch conditions for `JZ/JNZ`, and add
  deterministic faults for invalid target addresses.
- Runtime diagnostics: expose branch-fault visibility in slot state so a bad
  object file is distinguishable from a point-type failure.
- Validation: run the sample program, verify both taken and non-taken paths, and
  add one negative program with an out-of-range target that must fault before
  partial outputs commit.

### Stage 6: Edge Triggers

Recommended implementation set:

- `R_TRIG <symbol>`
- `F_TRIG <symbol>`
- keep timers for the next stage

Execution contract:

- the operand must resolve to a readable `BOOL` point
- the instruction reads the point directly and pushes one `BOOL` result on the stack
- `R_TRIG` emits `true` for one scan on a `false -> true` transition
- `F_TRIG` emits `true` for one scan on a `true -> false` transition
- the first scan after a slot load only initializes the remembered state and must not emit an edge pulse

Validation program: rising edge pulse

```text
PARAM POINT_ID enable
CONST POINT_ID pulse, demo.sim.output0

R_TRIG enable
STORE_BOOL pulse
HALT
```

Validation sequence:

- load the program while `enable=false`: output must stay `false`
- switch `enable` to `true`: exactly one scan must write `pulse=true`
- keep `enable=true`: next scans must return `pulse=false`
- toggle back to `false` then to `true`: one new pulse must be emitted

Validation program: falling edge pulse

```text
PARAM POINT_ID enable
CONST POINT_ID pulse, demo.sim.output1

F_TRIG enable
STORE_BOOL pulse
HALT
```

Validation sequence:

- load the program while `enable=true`: output must stay `false` on the first scan
- switch `enable` to `false`: exactly one scan must write `pulse=true`
- keep `enable=false`: next scans must return `pulse=false`

Validation program: count rising edges

```text
PARAM POINT_ID enable
VAR PUBLIC INT edgeCount

R_TRIG enable
JZ done
INC_INT edgeCount

done:
HALT
```

Expected behavior:

- `edgeCount` increments once per low-to-high transition of `enable`
- repeated scans with stable `enable=true` must not increment again
- this program is useful to catch accidental level-sensitive behavior

Fault program: wrong operand type

```text
PARAM POINT_ID threshold
CONST POINT_ID pulse, demo.sim.output0

R_TRIG threshold
STORE_BOOL pulse
HALT
```

Validation notes:

- bind `threshold` to an `INT` point
- the loader may accept the relocation, but execution must fault with a type mismatch before any output write commits

### Stage 7: Timers, Starting With TON

Recommended implementation set:

- `TON_START timer_idx16, preset_ms32`
- `TON_DONE timer_idx16`
- `TON_RESET timer_idx16`
- defer `TOF`, `TP`, and elapsed/remaining introspection until this minimal TON contract is stable

Why TON first:

- it is the smallest useful timer block for real I/O behavior
- it reuses the per-slot timer area that already exists in the slot layout
- it avoids reopening the ISA shape too broadly while still forcing timer state semantics to become explicit

Execution contract:

- `TON_START` pops one `BOOL` enable value from the stack
- if enable is `false`, the addressed timer instance is cleared and `done=false`
- if enable is `true`, the timer starts or continues running toward `preset_ms32`
- once elapsed time reaches the preset, `done` stays `true` while enable remains `true`
- `TON_DONE` pushes the current `BOOL` done state for the addressed timer
- `TON_RESET` clears the addressed timer unconditionally
- timer state is owned by the slot and must be reset on slot load so a freshly loaded program never inherits old timing state
- `timer_idx16` must remain below the slot timer count or execution must fault deterministically

Minimal timer state per instance:

- running flag
- done flag
- start timestamp in milliseconds
- preset in milliseconds

Validation program: delayed output

```text
PARAM POINT_ID enable
CONST POINT_ID y, demo.sim.output0

LOAD_BOOL enable
TON_START 0, 1000
TON_DONE 0
STORE_BOOL y
HALT
```

Expected behavior:

- with `enable=false`, `y` stays `false`
- when `enable` becomes `true`, `y` stays `false` for about 1000 ms
- after the delay expires, `y` becomes `true`
- when `enable` returns to `false`, `y` returns to `false` and the timer resets

Validation program: delayed latch with public observation

```text
PARAM POINT_ID enable
VAR PUBLIC BOOL tonDone

LOAD_BOOL enable
TON_START 0, 750
TON_DONE 0
STORE_BOOL tonDone
HALT
```

Expected behavior:

- `tonDone` is easy to observe in the UI without relying on a short external pulse
- repeated scans before 750 ms must keep `tonDone=false`
- once the delay expires with `enable=true`, `tonDone=true`
- dropping `enable=false` clears `tonDone` again

Validation program: reset path

```text
PARAM POINT_ID enable
PARAM POINT_ID reset
VAR PUBLIC BOOL tonDone

LOAD_BOOL enable
TON_START 0, 1500

LOAD_BOOL reset
JZ publish
TON_RESET 0

publish:
TON_DONE 0
STORE_BOOL tonDone
HALT
```

Expected behavior:

- `enable=true` starts the timer
- `reset=true` clears it immediately, even if the preset was almost reached
- after reset, `TON_DONE 0` must read `false` until a new full timing interval completes

Fault program: timer index out of range

```text
PUSH_TRUE
TON_START 99, 1000
HALT
```

Validation notes:

- if the slot exposes fewer than 100 timers, execution must fault deterministically
- the program must not corrupt neighboring timer state or commit partial outputs before faulting

### Stage 8: Timer Introspection, TOF, And TP

Recommended implementation set:

- `TON_ELAPSED timer_idx16`
- `TON_REMAINING timer_idx16`
- `TOF_START`, `TOF_DONE`, `TOF_RESET`
- `TP_START`, `TP_DONE`, `TP_RESET`

Execution contract:

- `TON_ELAPSED` pushes the current elapsed time in milliseconds for the addressed `TON` instance
- `TON_REMAINING` pushes the current remaining time in milliseconds for the addressed `TON` instance
- both introspection values use the current `INT16` stack type, so values are saturated to `32767 ms` until a wider integer stack type exists
- `TOF_START` pops one `BOOL` enable value; while enable is `true`, `TOF_DONE` is immediately `true`; when enable falls to `false`, the timer keeps `done=true` until the preset expires
- `TP_START` pops one `BOOL` enable value and emits a pulse on a low-to-high transition; the pulse remains active for the preset duration and does not retrigger until the input returns low
- `TOF_DONE`, `TP_DONE`, and all `*_RESET` mnemonics use the same timer index width and fault behavior as the Stage 7 `TON` instructions

Minimal per-timer state:

- anchor timestamp in milliseconds
- preset in milliseconds
- running/done/input-latched flags
- timer mode (`TON`, `TOF`, or `TP`)

Validation program: observe TON elapsed and remaining

```text
PARAM POINT_ID enable
VAR PUBLIC INT tonElapsed
VAR PUBLIC INT tonRemaining
VAR PUBLIC BOOL tonDone

LOAD_BOOL enable
TON_START 0, 5000

TON_ELAPSED 0
STORE_I16 tonElapsed

TON_REMAINING 0
STORE_I16 tonRemaining

TON_DONE 0
STORE_BOOL tonDone
HALT
```

Expected behavior:

- `tonElapsed` rises from `0` toward `5000`
- `tonRemaining` falls from `5000` toward `0`
- once done, `tonElapsed` stays clamped at the preset and `tonRemaining` stays `0`

Validation program: visible TOF output hold

```text
CONST POINT_ID in1,  gb9fao5yk4f.modbus0.waveshare0.input1
CONST POINT_ID out4, gb9fao5yk4f.modbus0.waveshare0.output4

LOAD_BOOL in1
TOF_START 0, 3000
TOF_DONE 0
STORE_BOOL out4
HALT
```

Expected behavior:

- `out4` turns on immediately when `input1=true`
- when `input1` returns to `false`, `out4` stays on for about `3000 ms` before turning off

Validation program: visible TP pulse

```text
CONST POINT_ID in1,  gb9fao5yk4f.modbus0.waveshare0.input1
CONST POINT_ID out4, gb9fao5yk4f.modbus0.waveshare0.output4
VAR PUBLIC BOOL tpDone

LOAD_BOOL in1
TP_START 0, 1500

TP_DONE 0
STORE_BOOL tpDone

LOAD_BOOL tpDone
STORE_BOOL out4
HALT
```

Expected behavior:

- each rising edge of `input1` produces one pulse of about `1500 ms`
- keeping `input1=true` must not retrigger the pulse continuously
- returning `input1=false` re-arms the pulse for the next rising edge

### ISA Status After Stage 8

The currently implemented PLC VM subset is now large enough to build and test
real slot programs directly on hardware.

Implemented instruction families:

- foundation and stack: `NOP`, `HALT`, `PUSH_TRUE`, `PUSH_FALSE`, `DUP`, `DROP`, `SWAP`
- boolean logic: `AND`, `OR`, `XOR`, `NOT`, `EQ`, `NE`
- boolean point access: `LOAD_BOOL`, `STORE_BOOL`
- integer point and literal access: `PUSH_I16`, `LOAD_I16`, `STORE_I16`
- integer arithmetic and selection: `ADD`, `SUB`, `LT`, `LE`, `GT`, `GE`, `MIN`, `MAX`, `CLAMP`, `SEL`
- integer point mutation: `INC_INT`, `DEC_INT`
- control flow: `JMP`, `JZ`, `JNZ`
- event/stateful primitives: `R_TRIG`, `F_TRIG`, `TON_START`, `TON_DONE`, `TON_RESET`, `TON_ELAPSED`, `TON_REMAINING`, `TOF_START`, `TOF_DONE`, `TOF_RESET`, `TP_START`, `TP_DONE`, `TP_RESET`

Implementation status summary:

- stages 1 through 8 are now implemented across HDL, loader validation, assembler, and disassembler
- edge state is stored in per-slot scratch SDRAM instead of FPGA fabric state arrays
- timer state is stored in the existing per-slot timer region
- PLC upload/commit flow has already needed runtime hardening, including non-blocking NodeNet TX handling and deferred auto-load after `plcUploadCommitRes`

Current practical scope:

- this subset is already sufficient for direct I/O mirroring, latching, edge-triggered behavior, conditional branching, delayed actions, and simple blink/state machines
- the VM is no longer blocked on ISA breadth for first industrial tests; the next work should favor the highest-value missing stateful primitives and continued robustness work

Known work that still remains around the current subset:

- keep reinforcing upload, load, and runtime fault paths whenever field tests expose a weak spot
- keep timer behavior under observation on hardware, especially around long-running enable/reset cycles and scan-to-scan stability
- keep validating that stateful features stay in SDRAM-owned slot memory rather than drifting back into LUT/FF-heavy implementations

### Recommended Next Stages

The next stages should add user value without reopening large architectural surfaces too early.

### Stage 9: IEC-Style Counters

Recommended implementation set:

- `CTU_COUNT counter_idx16, preset_i16`
- `CTU_DONE counter_idx16`
- `CTU_VALUE counter_idx16`
- `CTU_RESET counter_idx16`
- `CTD_COUNT counter_idx16, preset_i16`
- `CTD_DONE counter_idx16`
- `CTD_VALUE counter_idx16`
- `CTD_RESET counter_idx16`
- defer `CTUD` until single-direction counters are stable on hardware

Why this stage is next:

- counters are the next most useful stateful IEC primitive after timers and edge detection
- they can reuse the same architectural pattern: explicit slot-owned state with narrow HDL primitives
- they unlock many practical machine use cases without requiring floats or deep control flow

Execution contract:

- `CTU_COUNT` pops one `BOOL` count-enable value from the stack and increments the addressed counter once on each low-to-high transition seen by that counter instance
- `CTD_COUNT` pops one `BOOL` count-enable value from the stack and decrements the addressed counter once on each low-to-high transition seen by that counter instance
- `preset_i16` is written into the counter instance whenever `*_COUNT` executes so `*_DONE` and `*_VALUE` always observe the latest configured preset for that counter
- `CTU_DONE` pushes `true` when `current_value >= preset`, otherwise `false`
- `CTD_DONE` pushes `true` when `current_value <= 0`, otherwise `false`
- `CTU_VALUE` and `CTD_VALUE` push the current counter value as `INT16`
- `CTU_RESET` and `CTD_RESET` clear the counter value and latched input state; `CTU_RESET` returns the value to `0`, and `CTD_RESET` returns the value to the current stored preset
- all counter instructions use the same `timer_idx16`-style addressing discipline as the timer family and must fault on out-of-range instance indices
- current Stage 9 implementation reuses the existing per-slot timer instance region as a shared state pool for both timers and counters, so a slot must not reuse the same instance index for both families
- values use the current `INT16` stack type, so saturation or clamping must be defined explicitly rather than relying on silent wraparound

Minimal per-counter state:

- current value as signed `INT16`
- preset as signed `INT16`
- last input high flag for edge qualification
- done flag if that stays cheaper than recomputing from value and preset
- counter mode (`CTU` or `CTD`) if a shared storage layout is used

Validation program: count rising edges into a public value

```text
CONST POINT_ID in1, gb9fao5yk4f.modbus0.waveshare0.input1
VAR PUBLIC INT pulseCount
VAR PUBLIC BOOL pulseDone

LOAD_BOOL in1
CTU_COUNT 0, 3

CTU_VALUE 0
STORE_I16 pulseCount

CTU_DONE 0
STORE_BOOL pulseDone
HALT
```

Expected behavior:

- `pulseCount` increments only once per low-to-high transition of `input1`
- keeping `input1=true` across many scans must not keep incrementing the count
- `pulseDone` becomes `true` on the third rising edge and stays `true` until reset

Validation program: drive an output every third pulse

```text
CONST POINT_ID in1,  gb9fao5yk4f.modbus0.waveshare0.input1
CONST POINT_ID out4, gb9fao5yk4f.modbus0.waveshare0.output4

LOAD_BOOL in1
CTU_COUNT 0, 3

CTU_DONE 0
STORE_BOOL out4
HALT
```

Expected behavior:

- `output4` stays `false` for the first two rising edges
- `output4` becomes `true` on the third rising edge and remains `true` until reset
- this gives a simple machine-cycle threshold test without extra arithmetic

Validation program: count down to zero

```text
CONST POINT_ID in1,  gb9fao5yk4f.modbus0.waveshare0.input1
CONST POINT_ID out5, gb9fao5yk4f.modbus0.waveshare0.output5
VAR PUBLIC INT remaining

LOAD_BOOL in1
CTD_COUNT 1, 5

CTD_VALUE 1
STORE_I16 remaining

CTD_DONE 1
STORE_BOOL out5
HALT
```

Expected behavior:

- `remaining` moves from the chosen initial value toward `0` one event at a time
- `output5` becomes `true` only when the counter reaches zero or below
- repeated scans with `input1=true` held high must not consume multiple counts

Validation focus:

- count only once per intended event, whether edge qualification lives inside the counter opcode or is composed with `R_TRIG`
- enforce reset semantics before optimizing convenience features
- define clamping behavior for underflow and overflow before enabling wide field tests
- avoid hidden coupling between timer state and counter state layouts

### Stage 10: Targeted Runtime And ISA Hardening

Recommended implementation set:

- finish any missing fault-path determinism found during Stage 8 and 9 field tests
- add more hardware-facing validation programs to this spec for upload, reset, restart, and fault recovery
- only then consider widening arithmetic or diagnostics

Why this is its own stage:

- the VM is now useful enough that most remaining risk comes from lifecycle behavior, not missing mnemonics
- the recent field failures were caused by load/reload/runtime interactions rather than by boolean or arithmetic semantics
- once a slot owns state across scans, every reset, fault, and reload path becomes part of the ISA contract in practice

Stage 10 scope:

- keep the Stage 9 instruction surface stable
- tighten runtime behavior around upload, deferred auto-load, restart, and fault stop/recovery
- make failure behavior as testable and repeatable as normal execution behavior

Hardening contract:

- the same malformed or unsupported program must produce the same fault code on repeated runs
- a fault in one slot must stop that slot cleanly without corrupting other slots or shared runtime tables
- partial execution of a stateful instruction must not leave a slot in an ambiguous half-updated state after restart or reload
- after deferred auto-load, the slot must return to the same paused/running state it had before the upload began
- clearing a fault or loading a replacement program must not require a power cycle to recover normal execution
- runtime-owned SDRAM structures must remain self-consistent even when a slot faults during stateful timer or counter operations

Primary fault classes to lock down:

- invalid opcode or truncated instruction stream
- stack underflow and stack overflow
- type mismatch on stack or point access
- point index out of range
- timer or counter instance index out of range
- runtime write rejection on non-writable points
- reload while the slot previously owned stateful timer/counter instances

Implementation focus:

- prefer deterministic stop-and-report over attempting clever in-place recovery during the same scan
- preserve slot isolation even if that means a slightly more conservative fault path
- treat loader validation and runtime fault handling as one surface: reject what can be rejected before execution, fault cleanly for what must be detected at execution time
- document every intentional simplification, such as shared timer/counter instance pools, so test programs can exercise those boundaries explicitly

Why this stage follows timers:

- the current system has already shown that practical robustness work appears exactly when real hardware programs become non-trivial
- hardening after each feature wave is cheaper than trying to debug several new stateful families at once

Validation matrix:

- upload a valid replacement over a previously running slot and verify the slot resumes in the same running state
- upload a valid replacement over a previously stopped slot and verify the slot remains stopped after auto-load
- trigger a deterministic runtime fault and verify the same fault code and stop behavior over repeated runs
- recover from that fault by loading a valid program and verify normal execution resumes without board reset
- verify that timer/counter state from an old program does not leak into a newly loaded program using different indices
- verify that an out-of-range timer/counter reference faults the slot and leaves other slots running

Validation program: deterministic counter index fault

```text
CONST POINT_ID in1, gb9fao5yk4f.modbus0.waveshare0.input1

LOAD_BOOL in1
CTU_COUNT 1024, 3
HALT
```

Expected behavior:

- execution must stop with a deterministic point-or-instance out-of-range fault
- repeating the same load/run sequence must produce the same fault code and the same slot stop state
- other slots must continue to scan normally

Validation program: fault recovery after replacement upload

```text
CONST POINT_ID out4, gb9fao5yk4f.modbus0.waveshare0.output4

PUSH_TRUE
STORE_BOOL out4
HALT
```

Expected behavior:

- after a deliberate Stage 10 fault test, loading this trivial replacement must restore normal execution without a board reboot
- `output4` must become `true`
- the previous fault code should be clearable by the normal runtime recovery path rather than only by power cycling

Validation program: reset stability across repeated scans

```text
CONST POINT_ID in1,  gb9fao5yk4f.modbus0.waveshare0.input1
CONST POINT_ID out4, gb9fao5yk4f.modbus0.waveshare0.output4
VAR PUBLIC INT count

LOAD_BOOL in1
CTU_COUNT 0, 2

LOAD_BOOL in1
JZ no_reset
CTU_RESET 0
no_reset:

CTU_VALUE 0
STORE_I16 count

CTU_DONE 0
STORE_BOOL out4
HALT
```

Expected behavior:

- with `input1=false`, the counter remains stable scan to scan
- with `input1=true`, the reset path behaves deterministically and does not leave the counter in a partially updated state
- repeated toggling must not accumulate ghost counts or require a restart to restore correct behavior

Validation program: reload boundary between timer and counter indices

```text
CONST POINT_ID in1,  gb9fao5yk4f.modbus0.waveshare0.input1
CONST POINT_ID out4, gb9fao5yk4f.modbus0.waveshare0.output4

LOAD_BOOL in1
TON_START 0, 1000
TON_DONE 0
STORE_BOOL out4
HALT
```

Then replace it with:

```text
CONST POINT_ID in1,  gb9fao5yk4f.modbus0.waveshare0.input1
CONST POINT_ID out4, gb9fao5yk4f.modbus0.waveshare0.output4

LOAD_BOOL in1
CTU_COUNT 1, 2
CTU_DONE 1
STORE_BOOL out4
HALT
```

Expected behavior:

- the second program must start from a clean state for counter index `1`
- the timer state previously used by index `0` must not affect the counter behavior at index `1`
- replacing a stateful program with another stateful program must remain stable across repeated uploads

Stage 10 completion criteria:

- at least one negative test exists for each major VM fault class already reachable from the current ISA
- upload, auto-load, restart, and fault recovery have documented validation programs in this spec
- the user can recover from an intentionally faulting program by loading a valid replacement without needing an FPGA reflash or power cycle
- all known lifecycle-related simplifications and limits are written down next to the validation guidance that exercises them

### Stage 12: Numeric Conversion, Bit Extraction, And Stage 11 Close-Out

Recommended implementation set:

- `I32_TO_F32`
- `U32_TO_F32`
- `F32_TO_I32`
- `F32_TO_U32`
- `TEST_BIT_U32 bit_imm5`
- `U32_AND`
- `SHR_U32 bitcount_imm5`
- `SHL_U32 bitcount_imm5`

Stage 11 carry-over to close explicitly:

- deferred `plcEraseReq` completion must refresh the OLED slot-status screen immediately; current hardware behavior can leave a stale `R` visible after an erased slot becomes empty
- `LOAD_F32`/`STORE_F32` with `FADD`, `FSUB`, `FMUL`, and `FDIV` has been validated on hardware across varied cases; keep only regression coverage and documentation sync for this slice
- validate the float compare family on hardware: `FEQ`, `FNE`, `FLT`, `FLE`, `FGT`, `FGE`
- confirm which documented float opcodes are truly implemented versus intentionally deferred, then write the result next to the validation programs instead of leaving it implicit

Why this stage is useful:

- it completes the first practical bridge between existing integer-heavy point data and float math slots
- it unlocks compact integer-to-binary output mapping without needing huge branch tables
- it keeps the ISA HDL-friendly by favoring narrow, deterministic primitives over wide control flow
- it covers common industrial patterns such as counters, alarm masks, packed status words, simple engineering-unit conversion, and bitfield decoding

Minimum practical goal:

- the smallest useful conversion subset for immediate field use is `I32_TO_F32` plus `F32_TO_I32`
- with those two opcodes, a slot can read integer process values, apply float-domain math, and hand results back to integer sinks without firmware help
- the smallest useful subset for immediate field use is `TEST_BIT_U32 bit_imm5`
- with that one opcode, a slot can expose the low 8 bits of a `UINT32` counter onto `output1..output8`
- `U32_AND` and shifts remain valuable follow-ons for broader masking and packing logic

Execution contract:

- `I32_TO_F32` consumes one `INT32` from the stack and pushes one `FLOAT`
- `U32_TO_F32` consumes one `UINT32` from the stack and pushes one `FLOAT`
- `F32_TO_I32` consumes one `FLOAT` and pushes one `INT32`; NaN, Inf, and out-of-range values must fault deterministically rather than saturating silently
- `F32_TO_U32` consumes one `FLOAT` and pushes one `UINT32`; NaN, Inf, negative, and out-of-range values must fault deterministically rather than saturating silently
- `TEST_BIT_U32 bit_imm5` consumes one `UINT32` from the stack and pushes one `BOOL` that reflects the selected bit
- `U32_AND` consumes the top two `UINT32` values and pushes one `UINT32` result
- `SHR_U32 bitcount_imm5` consumes one `UINT32` and pushes the logical right-shifted `UINT32` result
- `SHL_U32 bitcount_imm5` consumes one `UINT32` and pushes the left-shifted `UINT32` result
- bit indices above `31` and shift counts above `31` must fault deterministically rather than masking silently

Validation targets:

- convert a small signed `INT32` ramp to `FLOAT`, apply arithmetic, then convert back to `INT32` and verify exact round-trip behavior inside the exact `float32` integer range
- verify `F32_TO_I32` and `F32_TO_U32` deterministic fault behavior for NaN, Inf, negative-to-unsigned, and out-of-range inputs
- increment a `UINT32` counter on `R_TRIG input1`
- wrap the counter from `255` back to `0`
- drive `output1` from bit `0` through `output8` from bit `7`
- verify that a stable high input does not retrigger the count and does not corrupt the exposed bit pattern
- erase a loaded-and-running slot and verify the OLED slot-status screen leaves `R` immediately for `-` without requiring a reboot, another command, or a manual screen change

Candidate follow-on after Stage 10:

- wider diagnostics such as `TRACE` or `ASSERT`
- heavier arithmetic such as `MUL`, `DIV`, and modulo
- bit utilities such as `TEST_BIT_U32`, `U32_AND`, and narrow shifts for packed status decoding
- float support if a concrete process-control need justifies the cost

### Deferred Beyond Step 2 Core

Keep these out of the frozen core unless there is a direct hardware need:

- timer primitives beyond the first minimal `TON` slice, such as `TOF_*`, `TP_*`, `TON_ELAPSED`, and `TON_REMAINING`
- multiply, divide, modulo, and wide shifts
- float load/store, compare, arithmetic, and conversion

Why they are deferred:

- timers need explicit per-slot state and time semantics
- multiply and divide expand the datapath cost for limited early value
- float support is valuable, but it is the heaviest execution family to verify
- `LOOP rel16`

Why this tier is more structural:

- the execution engine must update control flow internally
- loops and calls need return-stack or call-stack state
- debugging and single-step behavior become more important

Pragmatic note:

- if simplicity matters more than language richness, stop at `JMP`, `JZ`, and
  `JNZ` first and defer `CALL`/`RET`

### Tier 4: Time And State Instructions, HDL-Native But Stateful

Timers are a natural fit for hardware, but they introduce multi-scan state,
timebase coupling, and explicit slot-owned timer storage.

Recommended instructions:

- `GET_TIME_MS`
- `GET_CYCLE_COUNTER`
- `TON_START timer_idx16, preset_ms32`
- `TON_DONE timer_idx16`
- `TON_ELAPSED timer_idx16`
- `TON_REMAINING timer_idx16`
- `TON_RESET timer_idx16`
- `TOF_START timer_idx16, preset_ms32`
- `TOF_DONE timer_idx16`
- `TOF_RESET timer_idx16`
- `TP_START timer_idx16, preset_ms32`
- `TP_DONE timer_idx16`
- `TP_RESET timer_idx16`
- `R_TRIG <symbol>`
- `F_TRIG <symbol>`

Why this tier is not trivial despite good HDL fit:

- every timer needs persistent per-slot state
- scan semantics must define when elapsed time is sampled and committed
- edge detectors also need previous-state memory per signal or per instance

### Tier 5: Multiplication And Division Family

These are still integer instructions, but cost rises because divider logic is
noticeably more expensive than add/compare logic.

Recommended instructions:

- `MUL`
- `MULH`
- `DIV`
- `MOD`
- `SCALE affine`

Why this tier is later:

- multiplication is manageable but still wider and slower
- division and modulo typically become multi-cycle
- divide-by-zero semantics must be explicit

### Tier 6: Type Conversion And Mixed-Width Data Handling

These are useful once the language grows beyond a boolean ladder subset.

Recommended instructions:

- `ZX_U16_TO_U32`
- `SX_I16_TO_I32`
- `TRUNC_U32_TO_U16`
- `TRUNC_I32_TO_I16`
- `BOOL_TO_U16`
- `BOOL_TO_I16`
- `BOOL_TO_U32`
- `BOOL_TO_I32`
- `I32_TO_BOOL`
- `U32_TO_BOOL`
- `ENUM_TO_U16`
- `U16_TO_ENUM`

Why this tier is medium complexity:

- the datapath is still integer-only
- the real complexity is semantic: saturation, truncation, sign extension, and
  diagnostics on lossy conversions

### Tier 7: Float Family

Floating-point instructions are the least attractive early HDL target.

Recommended instructions:

- `LOAD_F32 <symbol>`
- `STORE_F32 <symbol>`
- `PUSH_F32 imm32`
- `FADD`
- `FSUB`
- `FMUL`
- `FDIV`
- `FNEG`
- `FABS`
- `FEQ`
- `FNE`
- `FLT`
- `FLE`
- `FGT`
- `FGE`
- `FMIN`
- `FMAX`
- `I32_TO_F32`
- `U32_TO_F32`
- `F32_TO_I32`
- `F32_TO_U32`

Why this tier is hardest:

- either a soft-float microcode path or a larger floating-point unit is needed
- latency becomes multi-cycle and type handling gets much stricter
- debugging NaN, Inf, and rounding behavior is a separate effort

### Tier 8: Nice-To-Have But Likely Better Left In Firmware

These may be valid VM features, but they are not strong first candidates for
HDL execution.

Possible instructions:

- `LOAD_STATUS idx16`
- `SET_QUALITY idx16, imm16`
- `ASSERT code16`
- `TRACE imm16`
- `STRING_EQ`
- `MEMCPY`
- `CRC32`

Why these are poor early HDL targets:

- they are supervisory, debug, or service-oriented more than cycle-critical
- some of them require variable-length or byte-stream handling
- firmware can usually provide them more cheaply than dedicated logic

## Recommended HDL-First Subset

If the future objective is to move toward HDL with the best effort-to-value
ratio, the recommended incremental subset is:

Phase A:

- `NOP`
- `HALT`
- `LOAD_BOOL`
- `STORE_BOOL`
- `LOAD_I16`
- `STORE_I16`
- `PUSH_TRUE`
- `PUSH_FALSE`
- `DUP`
- `DROP`
- `AND`
- `OR`
- `XOR`
- `NOT`
- `EQ`
- `NE`
- `ADD`
- `SUB`
- `INC_INT`
- `DEC_INT`

Phase B:

- `LT`
- `LE`
- `GT`
- `GE`
- `JMP`
- `JZ`
- `JNZ`
- `TON_START`
- `TON_DONE`
- `R_TRIG`
- `F_TRIG`

Phase C:

- `MIN`
- `MAX`
- `CLAMP`
- `SHL`
- `SHR`
- `SAR`
- `MUL`

Phase D, only if clearly justified:

- `DIV`
- `MOD`
- float load/store and float ALU instructions

## IEC-Aligned Phase A

If the goal is to stay compatible with IEC 61131-3 expectations while still
building a compact HDL-friendly VM, the first real execution profile should be
defined as a semantic subset, not as a copy of historical `IL` syntax.

The recommended IEC-aligned Phase A is:

### Core declarations

- `CONST POINT_ID`
- `PARAM POINT_ID`
- `VAR`

### Primitive data movement

- `LOAD_BOOL`
- `STORE_BOOL`
- `LOAD_I16`
- `STORE_I16`
- `PUSH_TRUE`
- `PUSH_FALSE`

### Primitive boolean logic

- `AND`
- `OR`
- `XOR`
- `NOT`

### Primitive integer logic

- `EQ`
- `NE`
- `ADD`
- `SUB`
- `INC_INT`
- `DEC_INT`

### Minimal execution control

- `NOP`
- `HALT`

Why this is the right Phase A:

- it already covers relay-like boolean logic
- it covers the first useful integer state pattern, especially counters and
  accumulators
- it stays implementable without branch hardware, divider hardware, or float
  support
- it matches the most common expectations from small PLC logic scans

IEC 61131-3 features intentionally deferred beyond Phase A:

- timer blocks such as `TON`, `TOF`, `TP`
- counter blocks such as `CTU`, `CTD`, `CTUD`
- ordered comparisons `LT`, `LE`, `GT`, `GE`
- control flow `JMP`, `JZ`, `JNZ`
- float types and float operators

## Primitive ISA Vs IEC Standard Blocks

The most important architectural rule for the next steps is to separate:

- primitive VM instructions
- IEC-facing standard blocks

They should not be treated as the same design problem.

### Primitive ISA

Primitive instructions are the actual execution atoms of the VM or HDL engine.
They should remain:

- fixed-width or nearly fixed-width
- easy to decode
- type-explicit
- locally testable in isolation

Examples of good primitive instructions:

- `LOAD_BOOL`
- `STORE_BOOL`
- `LOAD_I16`
- `STORE_I16`
- `PUSH_I16`
- `AND`
- `OR`
- `EQ`
- `ADD`
- `SUB`
- `JZ`
- `JMP`

### IEC Standard Blocks

IEC 61131-3 helps most at this level. Timers, counters, and edge detectors are
better treated as standard semantic blocks built on top of the runtime model,
not necessarily as one opcode each.

Examples of standard blocks or standard block families:

- `TON`
- `TOF`
- `TP`
- `CTU`
- `CTD`
- `CTUD`
- `R_TRIG`
- `F_TRIG`
- `SR`
- `RS`

For this project, the simplest mapping is usually one of these two strategies:

- expose a block as a small group of primitive-oriented instructions
- expose a block as a loader-recognized or runtime-recognized instance with
  explicit state slots

Recommended mappings for this VM family:

- `TON` -> `TON_START`, `TON_DONE`, `TON_ELAPSED`, `TON_RESET`
- `TOF` -> `TOF_START`, `TOF_DONE`, `TOF_RESET`
- `TP` -> `TP_START`, `TP_DONE`, `TP_RESET`
- `CTU` -> `CTU_COUNT`, `CTU_DONE`, `CTU_RESET`
- `CTD` -> `CTD_COUNT`, `CTD_DONE`, `CTD_RESET`
- `R_TRIG` and `F_TRIG` -> dedicated stateful primitives or runtime services

Why this split helps:

- the ISA stays regular and HDL-friendly
- IEC behavior stays available at source level
- timer and counter instance state can live in explicit per-slot memories
- desktop tooling can later compile a higher-level PLC source into the same
  primitive runtime

## IEC Priority For Future Work

IEC 61131-3 suggests the following practical order if user value matters more
than language purity.

### High value, moderate HDL cost

- ordered compares: `LT`, `LE`, `GT`, `GE`
- timer family: `TON`, `TOF`, `TP`
- edge detection: `R_TRIG`, `F_TRIG`
- counter family: `CTU`, `CTD`

### High value, higher HDL cost

- branching: `JMP`, `JZ`, `JNZ`
- multiply: `MUL`
- richer integer utilities: `MIN`, `MAX`, `CLAMP`

### Lower value for the first industrial subset

- float arithmetic
- strings
- generic diagnostics opcodes
- deep call/return control-flow features

## Candidate Full Instruction Set

For planning purposes, the most complete practical instruction catalog for this
VM family is:

### Declarations

- `CONST POINT_ID`
- `PARAM POINT_ID`
- `VAR`

### Control

- `NOP`
- `HALT`
- `JMP`
- `JZ`
- `JNZ`
- `JG`
- `JGE`
- `JL`
- `JLE`
- `CALL`
- `RET`
- `LOOP`

### Stack And Literals

- `PUSH_TRUE`
- `PUSH_FALSE`
- `PUSH_U16`
- `PUSH_I16`
- `PUSH_U32`
- `PUSH_I32`
- `PUSH_F32`
- `DUP`
- `DROP`
- `SWAP`

### Point Access

- `LOAD_BOOL`
- `STORE_BOOL`
- `LOAD_U16`
- `STORE_U16`
- `LOAD_I16`
- `STORE_I16`
- `LOAD_U32`
- `STORE_U32`
- `LOAD_I32`
- `STORE_I32`
- `LOAD_F32`
- `STORE_F32`
- `LOAD_ENUM`
- `STORE_ENUM`
- `LOAD_STATUS`
- `SET_QUALITY`

### Boolean And Compare

- `AND`
- `OR`
- `XOR`
- `NOT`
- `EQ`
- `NE`
- `LT`
- `LE`
- `GT`
- `GE`

### Integer Arithmetic

- `ADD`
- `SUB`
- `NEG`
- `ABS`
- `INC`
- `DEC`
- `MIN`
- `MAX`
- `CLAMP`
- `MUL`
- `DIV`
- `MOD`
- `SHL`
- `SHR`
- `SAR`

### Float Arithmetic

- `FADD`
- `FSUB`
- `FMUL`
- `FDIV`
- `FNEG`
- `FABS`
- `FEQ`
- `FNE`
- `FLT`
- `FLE`
- `FGT`
- `FGE`
- `FMIN`
- `FMAX`

### Conversions

- `ZX_U16_TO_U32`
- `SX_I16_TO_I32`
- `TRUNC_U32_TO_U16`
- `TRUNC_I32_TO_I16`
- `BOOL_TO_U16`
- `BOOL_TO_I16`
- `BOOL_TO_U32`
- `BOOL_TO_I32`
- `I32_TO_BOOL`
- `U32_TO_BOOL`
- `ENUM_TO_U16`
- `U16_TO_ENUM`
- `I32_TO_F32`
- `U32_TO_F32`
- `F32_TO_I32`
- `F32_TO_U32`

### Time And Event

- `GET_TIME_MS`
- `GET_CYCLE_COUNTER`
- `TON_START`
- `TON_DONE`
- `TON_ELAPSED`
- `TON_REMAINING`
- `TON_RESET`
- `TOF_START`
- `TOF_DONE`
- `TOF_RESET`
- `TP_START`
- `TP_DONE`
- `TP_RESET`
- `R_TRIG`
- `F_TRIG`

### Diagnostics And Escape Hatches

- `ASSERT`
- `TRACE`
- `DB`

## Instruction Families Reserved By The VM Spec

The broader VM specification reserves additional instruction families for future
releases. They are not part of the currently emitted toolchain subset, but they
are the intended direction. The HDL-oriented ranking above is the recommended
implementation order.

### Control

Reserved mnemonics:

- `NOP`
- `HALT`
- `JMP rel16`
- `JZ rel16`
- `JNZ rel16`

### Stack

Reserved mnemonics:

- `PUSH_U32 imm32`
- `PUSH_I32 imm32`
- `PUSH_F32 imm32`
- `DUP`
- `DROP`
- `SWAP`

### Generic Point Access

Reserved mnemonics:

- `LOAD_POINT idx16`
- `STORE_POINT idx16`
- `LOAD_STATUS idx16`
- `SET_QUALITY idx16, imm16`

### Integer And Boolean Operations

Reserved mnemonics:

- `EQ`
- `NE`
- `LT`
- `LE`
- `GT`
- `GE`
- `AND`
- `OR`
- `XOR`
- `NOT`
- `ADD`
- `SUB`
- `MUL`
- `DIV`
- `MOD`
- `MIN`
- `MAX`
- `CLAMP`

### Float Operations

Implemented mnemonics:

- `FADD`
- `FSUB`
- `FMUL`
- `FDIV`
- `FEQ`
- `FNE`
- `FLT`
- `FLE`
- `FGT`
- `FGE`

Reserved mnemonics:

- `FMIN`
- `FMAX`
- `I32_TO_F32`
- `U32_TO_F32`
- `F32_TO_I32`

### Time And Timers

Reserved mnemonics:

- `GET_TIME_MS`
- `TON_START timer_idx16, preset_ms32`
- `TON_DONE timer_idx16`
- `TOF_START timer_idx16, preset_ms32`
- `TOF_DONE timer_idx16`

## Object File Mapping

Each PLC source file is compiled into one `objectFileV1` artifact containing:

1. object header
2. raw code bytes
3. symbol table
4. relocation table

### Symbol Kinds

Current and reserved symbol kinds:

- `0`: `CONST POINT_ID`
- `1`: `PARAM POINT_ID`
- `2`: `VAR`

For `VAR`, the object symbol record uses:

- `symbol_name` as the variable name
- `expected_type` as the declared variable type
- `access` as the required runtime access, typically read-write
- `point_id` is ignored by the loader for that kind

### Relocations

Current relocation kinds:

- `0`: patch operand with runtime point index as little-endian `u16`
- `1`: patch operand with runtime point index as little-endian `u32`

Current boolean instructions use relocation kind `0`.

## Loader Semantics

When firmware loads an object into slot `N`, it performs these steps:

1. parse and validate the object file header
2. inspect symbol records
3. create dynamic local points for any `VAR` symbols under `plc.slotN`
4. republish the runtime descriptor store so those variables obtain runtime
   indices
5. resolve relocations for `CONST`, `PARAM`, and `VAR` symbols
6. copy linked bytecode to the slot SDRAM region
7. write slot manifest and control-block metadata

If symbol resolution fails, the load fails with the normal link/load error path.

## Naming Constraints

The current binary symbol record stores `symbol_name[16]`.

That implies these practical V1 limits:

- variable names should be 1 to 15 characters plus terminating zero
- use ASCII letters, digits, and `_`
- avoid spaces, dots, or path separators in variable names

## Recommended First Style

For the next toolchain step, keep source conservative:

- prefer short explicit variable names
- prefer `BOOL` and `INT` first
- reserve inter-slot sharing for values that are intentionally exported
- keep one slot variable semantically stable, as if it were part of a public
  API

## Minimal Example With Slot Variable

```text
PARAM POINT_ID input
CONST POINT_ID y, gb9fao5yk4f.modbus0.waveshare0.output4
VAR BOOL latch

LOAD_BOOL input
STORE_BOOL latch
LOAD_BOOL latch
STORE_BOOL y
HALT
```

Expected runtime side effects when loaded into slot 0:

- dynamic point `gb9fao5yk4f.plc.slot0.latch` is created
- any relocation targeting `latch` resolves to that point's runtime index
- another slot may later read the same point through normal point linking

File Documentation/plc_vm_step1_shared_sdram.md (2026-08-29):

# PLC VM Step 1: Shared SDRAM Fabric

## Purpose

This document defines the implementation target for phase 1 of the PLC VM
work: allowing the CPU and a future `plc_vm` master to access the same SDRAM
safely, while changing `wb_sdram_litedram` as little as possible.

The main design constraint is explicit:

- do not reopen the internal SDRAM wrapper logic unless strictly required
- keep the new logic outside the existing `wb_sdram_litedram` block whenever
  possible

## Current Anchors

The current SoC structure is:

- `picorv32_wb` is the only Wishbone master
- SDRAM traffic is selected in `top.sv` through `wb_sdram_sel`
- `wb_sdram_litedram` is instantiated as a single Wishbone slave for the full
  SDRAM window

Current code anchors:

- SDRAM selection in `top.sv`
- CPU Wishbone master in `top.sv`
- SDRAM wrapper instantiation in `top.sv`

## Design Decision

Phase 1 shall use option 1:

- insert a new arbitration block in front of `wb_sdram_litedram`
- keep `wb_sdram_litedram` functionally unchanged
- keep the CPU bus protocol unchanged
- define the second master interface so it matches the future `plc_vm`
  Wishbone-style master interface

This avoids turning `wb_sdram_litedram` into a second debugging frontier.

## Target Topology

### Current Topology

```text
picorv32_wb
   |
   +--> top.sv address decode
           |
           +--> wb_sdram_litedram
```

### Target Phase 1 Topology

```text
picorv32_wb -------------------+
                               |
future plc_vm / dummy master --+--> wb_sdram_rr_arbiter --> wb_sdram_litedram
```

The arbiter owns the shared-master behavior.

`wb_sdram_litedram` remains the unique SDRAM-facing slave wrapper.

## Point Of Insertion

The insertion point is in `top.sv`, between:

- CPU SDRAM-selected request wires
- the current `wb_sdram_litedram` instance

The intended wiring change is local to the SDRAM path only.

### What Stays Unchanged

- CPU master instantiation
- non-SDRAM peripherals
- global address map
- `wb_sdram_litedram` internal state machine and LiteDRAM integration

### What Changes In `top.sv`

1. Split current CPU Wishbone signals into:
   - full-system CPU bus wires, unchanged
   - SDRAM-only CPU request wires derived from `wb_sdram_sel`
2. Add second-master SDRAM request wires for a dummy master first, then
   `plc_vm`
3. Add arbiter output wires driving `wb_sdram_litedram`
4. Route only the SDRAM path through the arbiter
5. Keep the existing `wb_dat_i` and `wb_ack` muxing model, but source the SDRAM
   response from the arbiter's CPU return path instead of directly from
   `wb_sdram_litedram`

## Recommended Phase 1 Wiring Model

### CPU Side

The CPU remains the single master for the main SoC bus.

For the SDRAM subpath only, derive:

```text
cpu_sdram_adr
cpu_sdram_dat_w
cpu_sdram_sel
cpu_sdram_we
cpu_sdram_cyc
cpu_sdram_stb
cpu_sdram_dat_r
cpu_sdram_ack
```

Where:

- request signals are copies of the CPU Wishbone master when `wb_sdram_sel` is
  active
- response signals replace the direct connection previously coming from
  `wb_sdram_litedram`

### Second Master Side

Define a second master interface with the same signal family:

```text
m1_adr
m1_dat_w
m1_sel
m1_we
m1_cyc
m1_stb
m1_dat_r
m1_ack
```

Phase 1 should use a dummy master first.

The dummy master may be a tiny test FSM able to:

- write a known word pattern to a reserved SDRAM address
- read it back
- expose success or failure through debug/status bits

### Arbiter Output Side

The arbiter shall expose one single downstream Wishbone slave-facing channel:

```text
sdram_arb_adr
sdram_arb_dat_w
sdram_arb_sel
sdram_arb_we
sdram_arb_cyc
sdram_arb_stb
sdram_arb_dat_r
sdram_arb_ack
```

These signals connect directly to the existing Wishbone inputs and outputs of
`wb_sdram_litedram`.

## Arbiter Technical Specification

Recommended module name:

- `wb_sdram_rr_arbiter`

Recommended scope:

- exactly `2` masters in V1
- single outstanding transaction total
- one completed transaction per grant turn
- no pipelining requirement
- no burst requirement

### Functional Requirements

- accept requests from two Wishbone-style masters
- forward exactly one selected request to the SDRAM wrapper
- route `ack` and read data only to the granted master
- preserve forward progress for both masters under sustained load
- preserve single-master behavior when only one requester is active

### Arbitration Policy

- strict round-robin
- no fixed priority
- rotate grant after each acknowledged transaction
- if only one master is requesting, keep serving it

### Simplifying Assumptions For V1

- only one SDRAM transaction may be in flight at a time
- downstream slave is the already-debugged `wb_sdram_litedram`
- downstream `ack` is the transaction completion event
- downstream read data is valid only with `ack`

### Suggested Internal State Machine

- `IDLE`
- `GRANT_M0_WAIT_ACK`
- `GRANT_M1_WAIT_ACK`

Behavior:

- from `IDLE`, select the next requester according to round-robin order
- hold that requester until downstream `ack`
- return `ack` only to that requester
- on completion, toggle the round-robin preference and return to `IDLE`

### Forward-Progress Rules

- if both masters request continuously, service alternates by transaction
- if only one master requests, it is serviced without artificial bubbles
- a silent master must not delay an active master

## Debug Requirements

The arbiter must expose enough visibility for FPGA bring-up and OLED reporting.

Minimum recommended signals:

- `dbg_last_grant_master[0:0]`
- `dbg_rr_preference[0:0]`
- `dbg_state[1:0]` or equivalent
- `dbg_m0_grant_count[31:0]`
- `dbg_m1_grant_count[31:0]`
- `dbg_m0_stall_count[31:0]`
- `dbg_m1_stall_count[31:0]`
- `dbg_m0_req_seen`
- `dbg_m1_req_seen`
- `dbg_downstream_ack_count[31:0]`
- `dbg_error_sticky`
- optional `dbg_last_addr[31:0]`

These do not all need a final MMIO ABI immediately, but they should exist as
named wires or registers from the first RTL revision.

## Recommended Integration Sequence

### Step 1

Introduce the arbiter with:

- CPU SDRAM master connected as master 0
- dummy test master connected as master 1
- `wb_sdram_litedram` unchanged downstream

### Step 2

Keep the existing CPU path to every non-SDRAM slave unchanged.

### Step 3

Expose a small subset of arbiter debug bits into the existing status path so
firmware can present errors on the OLED.

### Step 4

Validate on FPGA with:

- CPU boot from SDRAM still working
- dummy master write/read test
- sustained concurrent access fairness test

## Exact Code-Level Insertion Guidance

### In `top.sv`

Relevant anchors:

- `assign wb_sdram_sel = ...`
- `picorv32_wb` instantiation
- `wb_sdram_litedram` instantiation

Phase 1 should add the arbiter around the existing SDRAM instance rather than
editing the internals of the SDRAM wrapper.

Concretely:

1. keep the current CPU master wires as the SoC-wide master bus
2. derive a CPU-to-SDRAM subchannel from the existing bus decode
3. instantiate `wb_sdram_rr_arbiter`
4. connect arbiter downstream signals to `wb_sdram_litedram`
5. replace the direct SDRAM response path in the CPU mux with the arbiter's CPU
   response output

### In `wb_sdram_litedram.sv`

Recommended policy:

- no functional refactor in phase 1
- no arbitration logic added inside this module
- only tolerate the smallest interface adaptation if an absolutely necessary
  signal naming shim is required

That keeps the risk boundary clear:

- new bugs belong first to the new arbiter or its wiring
- existing SDRAM wrapper behavior remains comparable to the current known-good
  baseline

## Out Of Scope For Phase 1

- actual `plc_vm` execution logic
- bytecode fetch engine
- multi-slot runtime
- runtime point ABI publication
- performance optimization beyond fairness and correctness

## Acceptance Criteria

Phase 1 is successful when:

- the CPU still boots and executes from SDRAM on FPGA
- the new arbiter can service a dummy second master
- both masters can make forward progress under sustained contention
- `wb_sdram_litedram` internal behavior does not require redesign
- debug visibility is sufficient to diagnose arbitration failures from firmware

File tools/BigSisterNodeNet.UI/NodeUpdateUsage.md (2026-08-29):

# Utilisation du service NodeUpdate dans NodeViewModel

## Vue d'ensemble

Le service `NodeUpdate` est maintenant accessible dans `NodeViewModel` via la propriété `NodeUpdateService`. Cela permet d'envoyer des commandes de mise à jour aux nœuds du réseau NodeNet.

## Accès au service

```csharp
public class NodeViewModel : ObservableObject
{
	private readonly NodeUpdate _nodeUpdate;

	public NodeViewModel(INode node, NodeUpdate nodeUpdate = null)
	{
		_node = node;
		_nodeUpdate = nodeUpdate;
	}

	/// <summary>
	/// Service pour mettre à jour les propriétés du nœud via le réseau NodeNet
	/// </summary>
	public NodeUpdate NodeUpdateService => _nodeUpdate;
}
```

## Exemples d'utilisation

### Exemple 1 : Mettre à jour une propriété depuis un ViewModel

```csharp
public class FilterNodeViewModel : NodeViewModel
{
	private int _filterPosition;

	public int FilterPosition
	{
		get => _filterPosition;
		set
		{
			if (SetProperty(ref _filterPosition, value))
			{
				// Envoyer la mise à jour au nœud via NodeUpdate
				NodeUpdateService?.UpdateNode(Node, "FilterPosition", value);
			}
		}
	}
}
```

### Exemple 2 : Commande RelayCommand

```csharp
public class NodeViewModel : ObservableObject
{
	public RelayCommand<string> UpdatePropertyCommand { get; }

	public NodeViewModel(INode node, NodeUpdate nodeUpdate = null) : base(node, nodeUpdate)
	{
		UpdatePropertyCommand = new RelayCommand<string>(
			propertyName => 
			{
				if (NodeUpdateService != null)
				{
					// Logique pour obtenir la valeur
					var value = GetPropertyValue(propertyName);
					NodeUpdateService.UpdateNode(Node, propertyName, value);
				}
			},
			_ => NodeUpdateService != null // La commande est activée seulement si le service est disponible
		);
	}
}
```

### Exemple 3 : Vérifier la disponibilité du service

```csharp
public void TryUpdateNode(string propertyName, object value)
{
	if (NodeUpdateService == null)
	{
		// Le service n'est pas disponible (mode tests ou initialisation incomplète)
		MessageBox.Show("Le service de mise à jour n'est pas disponible.");
		return;
	}

	NodeUpdateService.UpdateNode(Node, propertyName, value);
}
```

## Architecture

```
NodeNetCore
	└─ NodeUpdateService (propriété publique)
		   │
		   └─ Injecté dans NodeViewModel
				  │
				  └─ Accessible via NodeUpdateService (propriété)
```

## Configuration de l'injection

Dans `NodeNetCore` :

```csharp
private void ConfigureServices(IServiceCollection services)
{
	// ...
	services.AddSingleton<NodeUpdate>();
}

// Exposition du service
public NodeUpdate NodeUpdateService => _serviceProvider?.GetService<NodeUpdate>();
```

Dans `NodeNetViewModel` :

```csharp
private void NodeUpdated(object sender, INode e)
{
	Application.Current.Dispatcher.Invoke(() =>
	{
		var nodeViewModel = new NodeViewModel(e, _nodeNet.NodeUpdateService);
		Nodes.Add(nodeViewModel);
	});
}
```

## Tests unitaires

Pour les tests, vous pouvez passer `null` ou un mock :

```csharp
// Sans service (pour les tests UI simples)
var viewModel = new NodeViewModel(mockNode, null);

// Avec un mock du service
var mockNodeUpdate = new Mock<NodeUpdate>();
var viewModel = new NodeViewModel(mockNode, mockNodeUpdate.Object);

// Vérifier les appels
viewModel.UpdateProperty("test", 42);
mockNodeUpdate.Verify(s => s.UpdateNode(It.IsAny<INode>(), "test", 42), Times.Once);
```

## Avantages

1. ✅ **Découplage** : Le ViewModel ne dépend pas directement de `BlockingCollection` ou des détails d'implémentation
2. ✅ **Testabilité** : Facile de mocker `NodeUpdate` pour les tests
3. ✅ **Optionnel** : Le paramètre est optionnel (`= null`), permettant la rétrocompatibilité
4. ✅ **Clair** : L'intention est claire via la propriété `NodeUpdateService`

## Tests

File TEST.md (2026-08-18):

# Hardware Test Guide

## Scope

Current boot architecture:

1. Stage0 in ROM BRAM (`boot_stage0.hex`)
2. App image in SPI flash (`nodenet_riscv_app.img`), copied to SDRAM and executed

This guide focuses on:

1. Build/program commands by change type
2. Boot robustness tests (missing image, bad CRC, bad size)
3. Ultra-short bench checklist

## Build and Program Matrix

1. HDL changed, quick validation in FPGA RAM:
   - `make all`
   - `make ram`

2. HDL changed, persistent cold-boot in FPGA flash:
   - `make all`
   - `make flash`
   - `make flash-fw` (reprogram app image partition after flash erase)

3. Firmware app only changed:
   - `make flash-fw-run`

4. Stage0 changed:
   - `make all`
   - `make ram`

5. Build artifacts only:
   - Stage0 ROM image: `make firmware-build`
   - App image: `make firmware-image`

## Boot Robustness Tests

Prepare fault images:

```bash
make firmware-image-tests
```

Run scenarios:

1. Missing image
   - `make flash-fw-test-missing`
   - `make ram-fast`
   - expected blink code: 2 pulses

2. Invalid payload CRC
   - `make flash-fw-test-crc`
   - `make ram-fast`
   - expected blink code: 10 pulses

3. Invalid image size/range
   - `make flash-fw-test-size`
   - `make ram-fast`
   - expected blink code: 7 pulses

Recovery to normal app:

```bash
make flash-fw-run
```

## Bench Sheet (Ultra Short)

Board / setup:

- Date:
- Board ID:
- Branch/commit:
- Operator:

Checklist:

| Test | Command(s) | Expected | PASS/FAIL | Observations |
|---|---|---|---|---|
| Baseline valid app boot | `make flash-fw-run` | App starts normally |  |  |
| Missing image fault | `make flash-fw-test-missing` + `make ram-fast` | D2 = 2 pulses loop |  |  |
| Bad CRC fault | `make flash-fw-test-crc` + `make ram-fast` | D2 = 10 pulses loop |  |  |
| Bad size fault | `make flash-fw-test-size` + `make ram-fast` | D2 = 7 pulses loop |  |  |
| Recovery after faults | `make flash-fw-run` | App starts normally again |  |  |

## Notes

1. `make firmware-test` is intentionally disabled (legacy flow removed).
2. If `make flash` is run, re-run `make flash-fw` to restore firmware app partition.

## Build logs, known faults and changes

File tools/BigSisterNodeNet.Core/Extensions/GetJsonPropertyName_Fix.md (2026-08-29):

# Correction : GetJsonPropertyName ne trouvait pas l'attribut JsonProperty

## 🐛 Problème identifié

La méthode `GetJsonPropertyName` ne retournait pas le nom JSON défini par l'attribut `[JsonProperty]` sur la propriété `InstrumentName`.

### Cause racine

Trois problèmes combinés :

1. **Interface vs Implémentation** : Quand l'expression `x => x.InstrumentName` utilise le type `INode`, la réflexion cherche l'attribut sur l'interface, pas sur la classe `Node` qui contient réellement l'attribut `[JsonProperty]`.

2. **Conversions implicites** : Le getter `InstrumentName` fait `_instrumentName.ToString()`, créant une `MethodCallExpression` au lieu d'une simple `MemberExpression`.

3. **Types génériques** : Les expressions lambda avec conversions de type créent des `UnaryExpression`.

## ✅ Solution implémentée

### 1️⃣ Recherche sur le type concret

```csharp
public static string GetJsonPropertyName<TSource, TProperty>(
	this TSource source,
	Expression<Func<TSource, TProperty>> propertyExpression)
{
	var memberExpression = GetMemberExpression(propertyExpression);
	if (memberExpression != null)
	{
		var propertyInfo = memberExpression.Member as PropertyInfo;
		if (propertyInfo != null)
		{
			// ✅ NOUVEAU : Si source est fourni, chercher sur le type concret
			if (source != null)
			{
				var concreteType = source.GetType(); // Node au lieu de INode
				var concreteProperty = concreteType.GetProperty(propertyInfo.Name);
				if (concreteProperty != null)
				{
					var jsonProperty = concreteProperty.GetCustomAttribute<JsonPropertyAttribute>();
					return jsonProperty?.PropertyName ?? propertyInfo.Name;
				}
			}

			// Fallback sur le type de l'expression
			var jsonPropertyAttr = propertyInfo.GetCustomAttribute<JsonPropertyAttribute>();
			return jsonPropertyAttr?.PropertyName ?? propertyInfo.Name;
		}
	}

	throw new ArgumentException("L'expression doit pointer vers une propriété", nameof(propertyExpression));
}
```

### 2️⃣ Gestion des expressions complexes

```csharp
/// <summary>
/// Extrait le MemberExpression d'une expression, gérant les conversions implicites
/// </summary>
private static MemberExpression GetMemberExpression<TSource, TProperty>(
	Expression<Func<TSource, TProperty>> propertyExpression)
{
	// Cas direct : x => x.Property
	if (propertyExpression.Body is MemberExpression memberExpression)
	{
		return memberExpression;
	}

	// Cas avec conversion : x => (object)x.Property
	if (propertyExpression.Body is UnaryExpression unaryExpression)
	{
		if (unaryExpression.Operand is MemberExpression operandMember)
		{
			return operandMember;
		}
	}

	// Cas avec appel de méthode : x => x.Property.ToString()
	if (propertyExpression.Body is MethodCallExpression methodCall)
	{
		if (methodCall.Object is MemberExpression methodMember)
		{
			return methodMember;
		}
	}

	return null;
}
```

## 🔍 Exemples de cas gérés

### Cas 1 : Interface → Implémentation

```csharp
// Avant (❌ bug)
INode node = new Node();
var jsonName = node.GetJsonPropertyName(x => x.InstrumentName);
// Résultat : "InstrumentName" (attribut non trouvé sur INode)

// Après (✅ corrigé)
INode node = new Node();
var jsonName = node.GetJsonPropertyName(x => x.InstrumentName);
// Résultat : "instrumentName" (attribut trouvé sur Node)
```

### Cas 2 : Conversion implicite

```csharp
// Expression avec conversion
Expression<Func<Node, object>> expr = x => x.InstrumentName;
// Body type : UnaryExpression (Convert)
//   └─ Operand type : MemberExpression (x.InstrumentName)

// ✅ Maintenant géré correctement
```

### Cas 3 : Appel de méthode (ToString)

```csharp
// Expression avec appel de méthode
Expression<Func<Node, string>> expr = x => x.InstrumentName;
// Getter fait : _instrumentName.ToString()
// Body type : MethodCallExpression
//   └─ Object type : MemberExpression (_instrumentName)

// ✅ Maintenant géré correctement
```

## 🧪 Tests de validation

### Test 1 : Type concret

```csharp
[Test]
public void GetJsonPropertyName_WithConcreteType_ReturnsJsonName()
{
	var node = new Node();
	var jsonName = node.GetJsonPropertyName(x => x.InstrumentName);

	Assert.AreEqual("instrumentName", jsonName);
}
```

### Test 2 : Via interface

```csharp
[Test]
public void GetJsonPropertyName_ViaInterface_ReturnsJsonName()
{
	INode node = new Node();
	var jsonName = node.GetJsonPropertyName(x => x.InstrumentName);

	Assert.AreEqual("instrumentName", jsonName); // ✅ Maintenant correct !
}
```

### Test 3 : Avec conversion

```csharp
[Test]
public void GetJsonPropertyName_WithConversion_ReturnsJsonName()
{
	var node = new Node();

	// Expression avec conversion implicite
	Expression<Func<INode, object>> expr = x => x.InstrumentName;
	var jsonName = PropertyExtensions.GetJsonPropertyName(expr);

	Assert.AreEqual("instrumentName", jsonName);
}
```

### Test 4 : Propriété avec ToString()

```csharp
[Test]
public void GetJsonPropertyName_WithToString_ReturnsJsonName()
{
	var node = new Node();

	// Même si le getter fait .ToString()
	var jsonName = node.GetJsonPropertyName(x => x.InstrumentName);

	Assert.AreEqual("instrumentName", jsonName);
}
```

## 📊 Comparaison avant/après

| Scénario | Avant | Après |
|---|---|---|
| `new Node().GetJsonPropertyName(x => x.InstrumentName)` | ❌ "InstrumentName" | ✅ "instrumentName" |
| `((INode)new Node()).GetJsonPropertyName(x => x.InstrumentName)` | ❌ "InstrumentName" | ✅ "instrumentName" |
| Expression avec `Convert` | ❌ Exception | ✅ "instrumentName" |
| Expression avec `ToString()` | ❌ Exception | ✅ "instrumentName" |

## 🔧 Fichiers modifiés

- **`BigSisterNodeNet.Core\Extensions\PropertyExtensions.cs`** : Correction complète

## ✅ Validation

### Build réussie

```
✓ BigSisterNodeNet.Core.csproj compilé avec succès
```

### Utilisation

```csharp
// Dans SendPropertyUpdate (NodeNetObjects.cs)
protected void SendPropertyUpdate<T>(
	Expression<Func<INode, T>> propertyExpression, 
	T value)
{
	// ...
	var jsonPropertyName = this.GetJsonPropertyName(propertyExpression);
	// ✅ Retourne maintenant "instrumentName" au lieu de "InstrumentName"
	service.UpdateNode(this, jsonPropertyName, value);
}
```

## 🎯 Résultat

La fonction `GetJsonPropertyName` retourne maintenant correctement les noms JSON définis par `[JsonProperty]`, même quand :
- L'expression utilise une interface (`INode`)
- Le type réel est une implémentation (`Node`)
- L'expression contient des conversions ou appels de méthodes

Les messages envoyés au réseau NodeNet utilisent maintenant les bons noms JSON (`"instrumentName"` au lieu de `"InstrumentName"`) ! ✅

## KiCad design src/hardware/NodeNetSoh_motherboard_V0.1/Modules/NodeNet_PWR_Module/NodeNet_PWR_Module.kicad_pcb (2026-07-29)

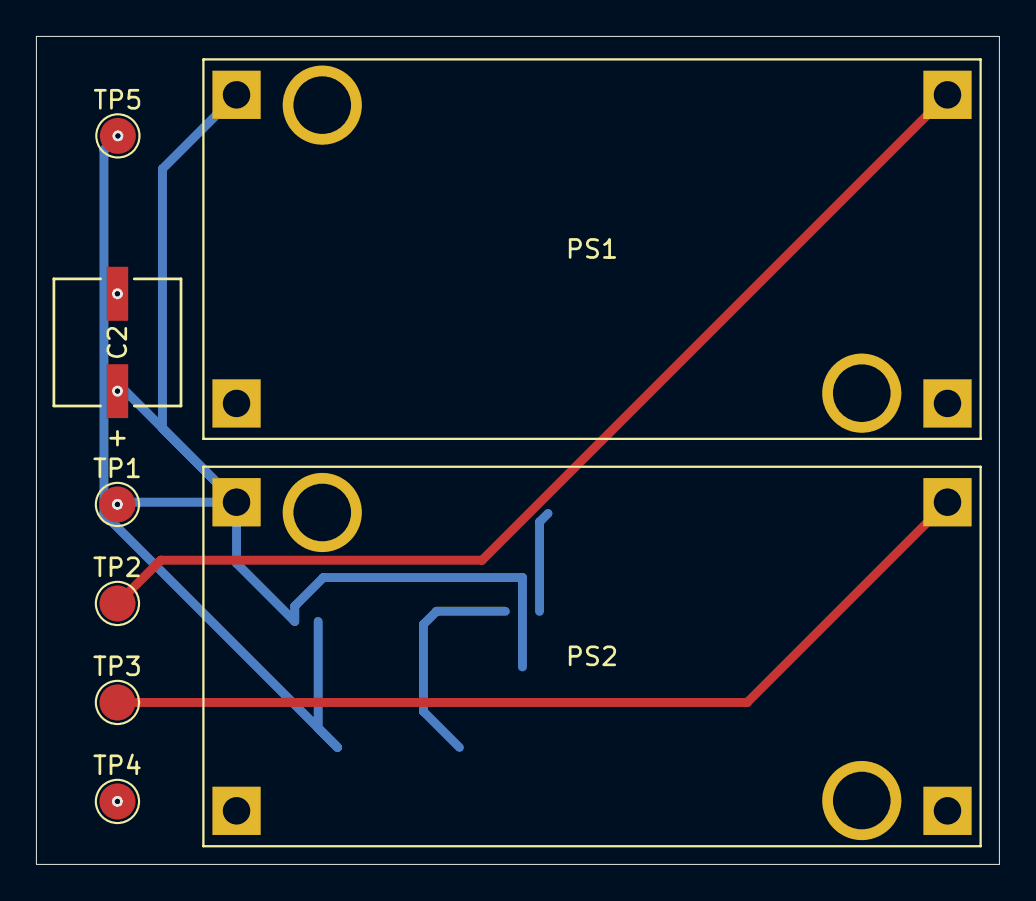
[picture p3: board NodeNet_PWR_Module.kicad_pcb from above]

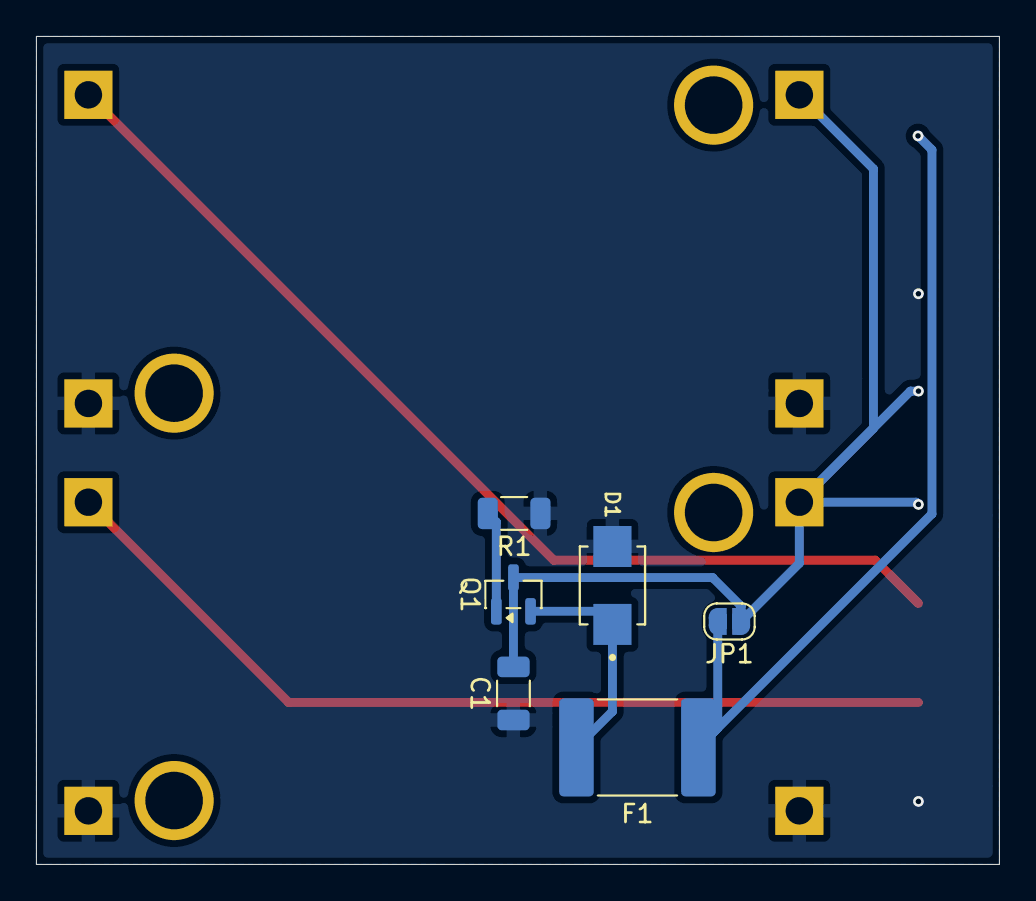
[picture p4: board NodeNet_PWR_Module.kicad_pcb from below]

Board: 2 copper layers, 53.5 x 46.0 mm, 14 parts (6 on the bottom side), 7 nets.

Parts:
C1: 100nF 50V; C_1206_3216Metric
C2: 100 uF 25V; PCAP_6.3x7.7-ELECT_NCA
D1: SMBJ15A
F1: MF-LSMF185X-2; Fuse_2920_7451Metric
JP1: ByPass; SolderJumper-2_P1.3mm_Open_RoundedPad1.0x1.5mm
PS1: 12V 5V buck converter; CONV_MC00100
PS2: 12V 3.3V buck converter; CONV_MC00100
Q1: AO3407A; SOT-23
R1: 100K; R_1206_3216Metric
TP1: 12V; TestPoint_Pad_D2.0mm
TP2: 5V; TestPoint_Pad_D2.0mm
TP3: 3.3V; TestPoint_Pad_D2.0mm
TP4: GND; TestPoint_Pad_D2.0mm
TP5: 12VIn; TestPoint_Pad_D2.0mm

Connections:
/3V3: PS2.OUT+, TP3.1 (1_1)
/5V: PS1.OUT+, TP2.1 (1_1)
/12V: C1.2, C2.1, JP1.1 (A), PS1.IN+, PS2.IN+, Q1.3 (D), TP1.1 (1_1)
/Ext 12V: F1.1, JP1.2 (B), TP5.1 (1_1)
/Ext GND: C1.1, C2.2, D1.A, PS1.IN-, PS1.OUT-, PS2.IN-, PS2.OUT-, R1.1, TP4.1 (1_1)
unnamed: Q1.1 (G), R1.2
unnamed: D1.C, F1.2, Q1.2 (S)

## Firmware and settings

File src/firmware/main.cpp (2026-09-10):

#include <cstdint>
#include <cstdio>
#include <cstdlib>
#include "plc_linker_v1.h"
#include "plc_loader_v1.h"
#include "plc_runtime_abi.h"
#include <ArduinoJson.h>
#include "bigsister.h"
#include "led.h"
#include "oled.h"
#include "i2c.h"
#include "version.h"
#include "lib/nodenet/nodenet.h"
#include "plclink_mailbox_service.h"
#include "spi_mailbox.h"

#include "nodenetCore.h"
#include "nodenetLogger.h"

namespace {

constexpr bool kEnablePlcLinkTraceLogs = false;

bool resolvePlcLinkPointState(void* context,
                              uint16_t point_index,
                              const PointDefinition& definition,
                              PointState& out_state)
{
    (void)definition;
    if (context == nullptr) {
        return false;
    }

    return static_cast<const NodeNetCore*>(context)->buildPlcLinkPointState(point_index, out_state);
}

plclink::ErrorCode writePlcLinkPointState(void* context,
                                          uint16_t point_index,
                                          uint8_t expected_value_type,
                                          uint8_t write_flags,
                                          uint32_t value_bits,
                                          uint8_t* out_applied_value_type,
                                          uint32_t* out_result_sequence)
{
    if (context == nullptr) {
        return plclink::kErrorWriteRejected;
    }

    return static_cast<plclink::ErrorCode>(static_cast<NodeNetCore*>(context)->writePlcLinkPointState(point_index,
                                                                                                       expected_value_type,
                                                                                                       write_flags,
                                                                                                       value_bits,
                                                                                                       out_applied_value_type,
                                                                                                       out_result_sequence));
}

void handleSpiMailboxProtocol(SpiMailbox& mailbox, const NodeNetCore& nodeNetCore)
{
    PointCatalog& point_catalog = const_cast<NodeNetCore&>(nodeNetCore).pointCatalog();
    const uint32_t defs_generation = point_catalog.defsGeneration();
    const uint32_t states_sequence = point_catalog.statesSequence();
    NodeNet* transport = nodeNetCore.nodeNet();
    if (transport == nullptr) {
        return;
    }

    (void)plclink_mailbox_service::service(mailbox,
                                           point_catalog,
                                           resolvePlcLinkPointState,
                                           writePlcLinkPointState,
                                           const_cast<NodeNetCore*>(&nodeNetCore),
                                           defs_generation,
                                           states_sequence);

    size_t dirty_index = 0u;
    uint32_t dirty_sequence = 0u;
    const bool dirty_pending = point_catalog.peekDirtyStateIndex(dirty_index, dirty_sequence);
    const uint16_t mailbox_status = mailbox.Status();
    if constexpr (kEnablePlcLinkTraceLogs) {
        static NodeLogger spi_logger(transport, 0x05);
        static uint32_t last_logged_sequence = 0xFFFFFFFFu;
        static uint16_t last_logged_status = 0xFFFFu;
        static size_t last_logged_dirty_index = static_cast<size_t>(-1);
        if (dirty_pending) {
            if (states_sequence != last_logged_sequence ||
                mailbox_status != last_logged_status ||
                dirty_index != last_logged_dirty_index) {
                spi_logger.Info("plcLink pump pending seq=%lu dirty=%u status=0x%04x has_rx=%u tx_ready=%u fullsync=%u",
                                static_cast<unsigned long>(dirty_sequence),
                                static_cast<unsigned>(dirty_index),
                                static_cast<unsigned>(mailbox_status),
                                mailbox.HasMessage() ? 1u : 0u,
                                mailbox.TxReady() ? 1u : 0u,
                                point_catalog.runtimeFullSyncRequired() ? 1u : 0u);
                last_logged_sequence = states_sequence;
                last_logged_status = mailbox_status;
                last_logged_dirty_index = dirty_index;
            }
        }
    }

    const bool pumped = plclink_mailbox_service::pumpUpdates(mailbox,
                                                             point_catalog,
                                                             resolvePlcLinkPointState,
                                                             const_cast<NodeNetCore*>(&nodeNetCore),
                                                             defs_generation,
                                                             point_catalog.statesSequence());
    if constexpr (kEnablePlcLinkTraceLogs) {
        static NodeLogger spi_logger(transport, 0x05);
        static uint32_t blocked_log_count = 0u;
        if (pumped) {
            spi_logger.Info("plcLink pump sent seq=%lu status=0x%04x",
                            static_cast<unsigned long>(point_catalog.statesSequence()),
                            static_cast<unsigned>(mailbox_status));
        } else if (dirty_pending) {
            ++blocked_log_count;
            if (blocked_log_count == 1u || (blocked_log_count % 64u) == 0u) {
                spi_logger.Warning("plcLink pump blocked seq=%lu dirty=%u status=0x%04x has_rx=%u tx_ready=%u",
                                   static_cast<unsigned long>(point_catalog.statesSequence()),
                                   static_cast<unsigned>(dirty_index),
                                   static_cast<unsigned>(mailbox.Status()),
                                   mailbox.HasMessage() ? 1u : 0u,
                                   mailbox.TxReady() ? 1u : 0u);
            }
        } else {
            blocked_log_count = 0u;
        }
    }
}

}

int main(void)
{
    // Initial startup LED blink to indicate booting.
    led_d2_blink();

    static constexpr uint32_t kBlinkPeriodMs = 2000u;
    bool led_on = false;
    uint32_t next_toggle_ms = *TIMER_MS + kBlinkPeriodMs;
    *LED_D2 = 1u;
    oled::init(0x3C);
    oled::showBootProgress("Display init", 0u);

    // NodeNet definition and initialization
    static NodeNet myNodeNet(
        NODENET0_BASE,
        0x04,
        1000000,
        200,
        nullptr,
        nullptr);


    static NodeNetCore nodeNetCore(&myNodeNet);
    static SpiMailbox spiMailbox;
    oled::showBootProgress("Node services", 10u);
    nodeNetCore.begin();
    PlcRuntimePublisherV1 plcRuntimePublisher;
    oled::showBootProgress("PLC slot linker", 35u);
    const bool plcRuntimeAbiReady = plcRuntimePublisher.begin();
    if (plcRuntimeAbiReady) {
        const uint32_t boot_now_ms = millis();
        oled::showBootProgress("Clear volatile state", 45u);
        PlcSlotLoaderV1::clearVolatileState();
        oled::showBootProgress("Attach PLC linker", 55u);
        nodeNetCore.attachPlcRuntimePublisher(&plcRuntimePublisher);
        oled::showBootProgress("Prepare PLC slots", 65u);
        (void)plcRuntimePublisher.publish(nodeNetCore.pointCatalog(), boot_now_ms);
        nodeNetCore.restorePersistedPlcSlots();
        oled::showBootProgress("Startup complete", 100u);
    } else {
        oled::showBootProgress("PLC linker unavailable", 100u);
    }

    if (plcRuntimeAbiReady) {
        oled::showSlotStatusScreen(nodeNetCore.addr);
    }

    while (1) {
        nodeNetCore.drainPlcVmStateEvents();
        handleSpiMailboxProtocol(spiMailbox, nodeNetCore);
        nodeNetCore.loop();
        const uint32_t now_ms = millis();
        if (!nodeNetCore.hasActiveRealtimeWork()) {
            oled::refreshScreenIfDue(now_ms, nodeNetCore.addr);
        }
        if ((int32_t)(now_ms - next_toggle_ms) >= 0) {
            led_on = !led_on;
            *LED_D2 = led_on ? 0u : 1u;
            next_toggle_ms += kBlinkPeriodMs;
        }
    }
}

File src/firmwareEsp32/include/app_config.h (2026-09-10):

#pragma once

#include <driver/gpio.h>
#include <driver/spi_master.h>

namespace app_config {

static constexpr spi_host_device_t kSpiHost = SPI3_HOST;
static constexpr gpio_num_t kSpiSck = GPIO_NUM_18;
static constexpr gpio_num_t kSpiMosi = GPIO_NUM_23;
static constexpr gpio_num_t kSpiMiso = GPIO_NUM_19;
static constexpr gpio_num_t kFpgaCs = GPIO_NUM_27;
static constexpr gpio_num_t kFpgaIrq = GPIO_NUM_32;
static constexpr gpio_num_t kOptionalSideband = GPIO_NUM_33;

static constexpr gpio_num_t kDisplayCs = GPIO_NUM_5;
static constexpr gpio_num_t kDisplayDc = GPIO_NUM_16;
static constexpr gpio_num_t kDisplayReset = GPIO_NUM_17;
static constexpr bool kDisplayBringupOwnsSpiBus = false;

static constexpr int kSpiClockHz = 1000000;
static constexpr int kSpiQueueSize = 2;
static constexpr int kSpiMaxTransferBytes = 4096;
static constexpr int kDisplayClockHz = 10000000;
static constexpr int kDisplayWidth = 284;
static constexpr int kDisplayHeight = 76;
static constexpr int kDisplayTestStripeRows = 16;
static constexpr int kDisplayXGap = 18;
static constexpr int kDisplayYGap = 82;
static constexpr bool kDisplaySwapXY = true;
static constexpr bool kDisplayMirrorX = true;
static constexpr bool kDisplayMirrorY = false;
static constexpr char kSetupApSsid[] = "NodeNet-Setup";
static constexpr char kSetupApPassword[] = "nodenet32";
static constexpr char kSetupHostname[] = "nodenet-esp32";
static constexpr char kWebMountPath[] = "/www";
static constexpr uint32_t kWebSnapshotRefreshMs = 5000;
static constexpr uint16_t kTransportMagic = 0x4E53u;
static constexpr uint8_t kTransportVersion = 1u;

} // namespace app_config

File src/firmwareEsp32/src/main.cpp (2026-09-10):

#include <freertos/FreeRTOS.h>
#include <freertos/task.h>

#include <cstdio>
#include <cstring>

#include <esp_err.h>
#include <esp_log.h>

#include "app_config.h"
#include "boot_ui.h"
#include "display_st7789.h"
#include "lvgl_port.h"
#include "spi_link.h"
#include "status_ui.h"
#include "ui_text.h"
#include "web_server.h"
#include "wifi_manager.h"

namespace {

constexpr const char* kLogTag = "esp32-main";
constexpr unsigned long kPollIntervalIdleMs = 20;
constexpr unsigned long kPollIntervalBusyMs = 1;
TickType_t g_last_poll_tick = 0;
uint8_t g_last_boot_percent = 0xFFu;
char g_last_boot_text[64] = {};
bool g_runtime_screen_shown = false;

uint8_t quantize_boot_percent(uint8_t percent)
{
    if (percent >= 100u) {
        return 100u;
    }
    return static_cast<uint8_t>((percent / 5u) * 5u);
}

void update_boot_progress_ui(bool force)
{
    const spi_link::BootProgress progress = spi_link::get_boot_progress();
    const uint8_t display_percent = quantize_boot_percent(progress.percent);
    const wifi_manager::SiteSettings settings = wifi_manager::get_site_settings();
    const char* language = settings.language;

    char status_text[64] = {};
    if (!progress.link_ready) {
        std::snprintf(status_text, sizeof(status_text), "%s", ui_text::boot_stage_text(language, ui_text::BootStage::InitSpi));
    } else if (!progress.caps_received) {
        std::snprintf(status_text, sizeof(status_text), "%s", ui_text::boot_stage_text(language, ui_text::BootStage::ReadFpgaCaps));
    } else if (!progress.snapshot_started) {
        std::snprintf(status_text, sizeof(status_text), "%s", ui_text::boot_stage_text(language, ui_text::BootStage::PrepareSnapshot));
    } else if (!progress.snapshot_complete) {
        std::snprintf(status_text, sizeof(status_text), "%s", ui_text::boot_stage_text(language, ui_text::BootStage::LoadingPoints));
    } else {
        std::snprintf(status_text, sizeof(status_text), "%s", ui_text::boot_stage_text(language, ui_text::BootStage::StartupOk));
    }

    if (!force && (display_percent == g_last_boot_percent) && (std::strcmp(status_text, g_last_boot_text) == 0)) {
        return;
    }

    boot_ui::set_progress(display_percent, status_text);
    lvgl_port::task_handler();
    g_last_boot_percent = display_percent;
    std::snprintf(g_last_boot_text, sizeof(g_last_boot_text), "%s", status_text);
}

} // namespace

extern "C" void app_main()
{
    bool spi_ready = false;

    vTaskDelay(pdMS_TO_TICKS(200));
    ESP_LOGI(kLogTag, "ESP32 firmware start");

    const esp_err_t preload_result = wifi_manager::preload_site_settings();
    if (preload_result != ESP_OK) {
        ESP_LOGW(kLogTag, "wifi_manager::preload_site_settings failed: %s", esp_err_to_name(preload_result));
    }

    const esp_err_t display_result = display_st7789::init();
    if (display_result != ESP_OK) {
        ESP_LOGE(kLogTag, "display_st7789::init failed: %s", esp_err_to_name(display_result));
        return;
    } else {
        ESP_LOGI(kLogTag, "display_st7789::init OK");
    }

    const esp_err_t lvgl_result = lvgl_port::init();
    if (lvgl_result != ESP_OK) {
        ESP_LOGE(kLogTag, "lvgl_port::init failed: %s", esp_err_to_name(lvgl_result));
        return;
    }

    const esp_err_t boot_ui_result = boot_ui::init();
    if (boot_ui_result != ESP_OK) {
        ESP_LOGE(kLogTag, "boot_ui::init failed: %s", esp_err_to_name(boot_ui_result));
        return;
    }

    const esp_err_t status_ui_result = status_ui::init();
    if (status_ui_result != ESP_OK) {
        ESP_LOGE(kLogTag, "status_ui::init failed: %s", esp_err_to_name(status_ui_result));
        return;
    }

    const wifi_manager::SiteSettings initial_settings = wifi_manager::get_site_settings();

    boot_ui::set_progress(10, ui_text::boot_stage_text(initial_settings.language, ui_text::BootStage::ScreenReady));
    lvgl_port::task_handler();

    boot_ui::set_progress(18, ui_text::boot_stage_text(initial_settings.language, ui_text::BootStage::WifiWeb));
    lvgl_port::task_handler();

    const esp_err_t wifi_result = wifi_manager::init();
    if (wifi_result != ESP_OK) {
        ESP_LOGE(kLogTag, "wifi_manager::init failed: %s", esp_err_to_name(wifi_result));
    } else {
        const esp_err_t web_result = web_server::start();
        if (web_result != ESP_OK) {
            ESP_LOGE(kLogTag, "web_server::start failed: %s", esp_err_to_name(web_result));
        }
    }

    if (app_config::kDisplayBringupOwnsSpiBus) {
        ESP_LOGI(kLogTag, "Display bring-up owns SPI bus; FPGA SPI link temporarily disabled");
        boot_ui::set_progress(100, ui_text::boot_stage_text(initial_settings.language, ui_text::BootStage::DisplayOnly));
        lvgl_port::task_handler();
    } else {
        boot_ui::set_progress(35, ui_text::boot_stage_text(initial_settings.language, ui_text::BootStage::FpgaLink));
        lvgl_port::task_handler();

        const esp_err_t init_result = spi_link::init();
        if (init_result != ESP_OK) {
            boot_ui::set_progress(100, ui_text::boot_stage_text(initial_settings.language, ui_text::BootStage::SpiError));
            lvgl_port::task_handler();
            ESP_LOGE(kLogTag, "spi_link::init failed: %s", esp_err_to_name(init_result));
        } else {
            spi_ready = true;
            update_boot_progress_ui(true);
        }
    }

    for (;;) {
        const wifi_manager::Status wifi = wifi_manager::get_status();
        const wifi_manager::SiteSettings settings = wifi_manager::get_site_settings();
        if (g_runtime_screen_shown) {
            status_ui::update(settings.language, wifi);
        }

        lvgl_port::task_handler();
        web_server::poll();

        if (app_config::kDisplayBringupOwnsSpiBus || !spi_ready) {
            vTaskDelay(pdMS_TO_TICKS(20));
            continue;
        }

        const TickType_t now = xTaskGetTickCount();
        const TickType_t poll_interval = pdMS_TO_TICKS(
            spi_link::is_busy() ? kPollIntervalBusyMs : kPollIntervalIdleMs);
        if ((now - g_last_poll_tick) < poll_interval) {
            vTaskDelay(pdMS_TO_TICKS(1));
            continue;
        }

        g_last_poll_tick = now;

        const esp_err_t poll_result = spi_link::poll();
        if (poll_result != ESP_OK) {
            boot_ui::set_progress(100, ui_text::boot_stage_text(settings.language, ui_text::BootStage::SpiError));
            lvgl_port::task_handler();
            ESP_LOGE(kLogTag, "spi_link::poll failed: %s", esp_err_to_name(poll_result));
        } else {
            const spi_link::BootProgress progress = spi_link::get_boot_progress();
            if (progress.snapshot_complete && !g_runtime_screen_shown) {
                status_ui::show();
                g_runtime_screen_shown = true;
            }

            if (!g_runtime_screen_shown) {
                update_boot_progress_ui(false);
            }
        }
    }
}

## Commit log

2026-07-25 Initial commit: FPGA SoC with PicoRV32, UART, and RS485 support
2026-07-25 Add reference to Alex Forencich Verilog UART IP
2026-07-25 Update architecture diagram with UART and RS485 signal flow
2026-07-26 Rename wb_led to wb_gpio (more generic), track file correctly
2026-07-26 Add wb_sdram: 8MB SDRAM controller for M12L64322A, fix LPF pin assignments
2026-07-26 Add wb_i2c (verilog-i2c wrapper) + u8g2 HAL + I2C MMIO driver
2026-07-26 Update all READMEs: I2C/u8g2/C++17 additions, new firmware guide with peripheral examples
2026-07-26 Rename firmware artifact blink→nodenet_riscv, add FIRMWARE_VERSION (version+git hash)
2026-07-26 Add version.h fallback to fix IntelliSense false error on FIRMWARE_VERSION
    [main.cpp]
2026-07-26 Organize headers: move version.h, i2c.h, sdram.h to include/ and update build paths
2026-07-26 Add NodeNet485 protocol module (wb_nodenet.sv) with encoder, decoder, heartbeat
2026-07-26 NodeNet485 infrastructure complete: module stub, encoder/decoder, heartbeat timer, C++ API - pending pin verification on PMODH (CABGA381)
2026-07-26 Integrate NodeNet485 on UART pins (H16/H17): replaced UART0 with wb_nodenet, automatic RS485 driver control
2026-07-26 Add firmware test code using NodeNet485 API: simple echo loop, removed UART0 dependencies
2026-07-26 Update README files to document NodeNet485 integration (replace UART0 with RS485 protocol)
2026-07-26 Add comprehensive English comments and complete README documentation for NodeNet485
    - Updated wb_nodenet.sv section in wbDevices/README.md with detailed SDRAM ring buffer architecture
    * Complete register map table (TX_WPTR, TX_RPTR, RX_WPTR, RX_RPTR, CONFIG, CONTROL, STATUS)
    * Ring buffer frame format and capacity calculations (~250 messages per direction)
    * Pointer management diagrams (TX and RX paths)
    * Debugging tips and performance metrics
    - Expanded firmware/README.md NodeNet485 section with practical examples
    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
2026-07-27 Update memory map and device pinout to reflect current implementation
    - Corrected Memory Layout section:
    * RAM: 0x00010000–0x0001FFFF (was wrong upper bound)
    * Removed obsolete UART0/1/2/3 entries
    * Added NodeNet485 at 0x10006000
    * Clarified SDRAM allocation: 1 MB NodeNet485 reserved, 7 MB app available
    - Updated Device Pinout:
    * Replaced RJ45 Connectors section with RS485 (NodeNet485 Protocol) details
    * H16 (RX), H17 (TX) pins documented
    * Removed Multiplexer Control references
    - Simplified GPIO section:
    * Removed obsolete multiplexer control pins
    - Added SPI Flash module (planned) to Peripherals:
    * wb_flash.sv for M95128 (256 Kbit)
    * Arduino preferences-like API fo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
2026-07-27 Add W25Q64 SPI flash module with Arduino preferences-like API
    Core Hardware Modules:
    - spi_master.sv: Simple SPI master (8/16/24/32-bit transfers @ 10 MHz)
    * Clock divider for configurable SPI clock rate
    * CPOL=0, CPHA=0 (standard SPI mode)
    * Shift register based, efficient implementation
    - wb_flash.sv: Wishbone B.4 slave for W25Q64 flash
    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
2026-07-27 Implement W25Q64 SPI flash with boot protection + comprehensive test suite
    Hardware:
    - Integrate wb_flash (SPI master) into top.sv Wishbone interconnect at 0x10007000
    - Add SPI flash pins (R2 CS, W2 MOSI, V2 MISO) to constraints/colorlight_i9.lpf
    - SCK generated internally via spi_master.sv (no GPIO pin needed)
    Firmware:
    - Implement flash.h with Arduino preferences-like API:
    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
2026-07-27 Rename project: Update README title from 'FPGA Hello World' to 'NodeNet SoC Risc-v'
    - Updated main title to reflect project scope: multi-node embedded system
    - Clarified NodeNet485 as core communication feature
    - Added mention of SPI flash persistent storage capability
2026-07-27 test: harden bring-up flow and align NodeNet params
2026-07-27 Add planned ST7789 SPI color LCD enhancement
2026-07-27 Add KiCad ignore rules and motherboard project scaffold
    [NodeNetSoh_motherboard_V0.1.kicad_pcb, NodeNetSoh_motherboard_V0.1.kicad_sch]
2026-07-27 Plan motherboard peripherals, power, Ethernet, and ESP32 options
2026-07-28 Add wb_led support, split D2 heartbeat, and update LED docs
2026-07-28 Add NodeNet hardware TX/RX LEDs and update documentation
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2026-07-28 Refactor firmware to object-based I2C and NodeNet APIs
2026-07-28 Fix IntelliSense false error on mcycle inline asm
    [main.cpp]
2026-07-28 Decouple NodeNet base from driver and align docs
2026-07-28 Refactor I2C base handling and add millis utility
2026-07-29 Fix PicoRV32 bring-up: reset, ROM byte mapping, and RAM programming flow
    [main.cpp]
2026-07-29 feat: update firmware blink flow, wb timer, and hardware/docs
    [ColorLight i9.kicad_sch, Mapping.xlsx, NodeNetSoh_motherboard_V0.1.kicad_sch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]
2026-07-30 Fix: LED blink now works - add BSS zeroing, simplify LED class, fix Wishbone ACK timing
    - start.S: Add BSS zeroing loop before C++ constructors (fixes guard variable init)
    - main.cpp: Remove static from led0/led1 (stack-allocated, no guard needed)
    - led.h: Rewrite as clean WbLed class with on(), off(), blink(durationMs)
    - wb_led.sv: Fix Wishbone ACK to be combinational (not delayed 1 cycle)
    - link.ld: Add __bss_start/__bss_end markers for BSS section
    - colorlight_i9.lpf: Add OPENDRAIN=ON to I2C pins (proper open-drain)
    - sim/: Add iverilog testbench for wb_led (all tests pass)
    [main.cpp]
2026-07-31 feat: I2C working — Alex Forencich core with ACK fix, OLED probe in progress
    - wb_i2c.sv: fix Wishbone ACK (combinational), fix SCL/SDA tristate (1'b1 not 1'bz)
    - i2c_master_wbs_8.v: ACK timing fix applied
    - constraints/colorlight_i9.lpf: I2C pins PULLMODE=UP for correct bidirectional IOBUF
    - top.sv: i2c0_scl/sda pin connections updated
    - i2c.h: I2C class with Init/Probe/Write
    - u8g2_hal: updated for current i2c driver
    - main.cpp: I2C probe loop, OLED init commented pending SSD1306 detection
    [main.cpp]
2026-07-31 fix: WbLed template + .data copy in start.S — global objects now work
    - led.h: WbLed becomes WbLed<BASE> template — address baked at compile-time,
    no constructor, no .sbss/runtime-init issues at global scope
    - link.ld: add AT>ROM and __data_load for .data section LMA/VMA split
    - start.S: add .data copy loop (ROM→RAM) before BSS zero and .init_array calls
    Fixes global C++ objects whose initial values were compiled into .data but
    never copied to RAM (BRAM starts at 0 after FPGA configuration)
    - main.cpp: WbLed<LED1_BASE> led1 at global scope, i2c_probe returns true (0x3C found)
    [revision_history.xlsx]
2026-07-31 feat: I2C class converted to template — global-scope safe, no constructor
    Same pattern as WbLed<BASE>: BASE address as template parameter baked at
    compile-time, GCC generates direct MMIO writes without runtime indirection.
    - i2c.h: I2C<BASE> template replaces I2C class with constructor
    - u8g2_hal.cpp: static const I2C<I2C0_BASE> s_i2c (no constructor call)
    - u8g2_hal.h: move #include i2c.h before extern C (templates not C-linkable)
    - main.cpp: I2C<I2C0_BASE> i2c0 at global scope, i2c_probe template function
    i2c0.Init(15) called once in main() before while(1)
    Result: led1 blinks fast = i2c_probe(0x3C) returns true = OLED found
    [main.cpp]
2026-07-31 feat: Wire API + gp/sbss fixes — endTransmission confirmed working
    - link.ld: add *(.sdata*) to .data, define __global_pointer\$, add *(.sbss*) to .bss
    GCC places small globals in .sdata/.sbss; without this they were not
    zeroed, causing tx_length_ garbage and silent crashes.
    - start.S: init gp register before stack setup (.option norelax to prevent
    circular gp-relative relocation during gp init itself).
    - i2c.h: add Arduino Wire-compatible API to I2C<BASE> template
    (begin/beginTransmission/write/endTransmission/requestFrom/read/
    available/peek/flush + tx/rx buffers).
    Template = always inline, so GCC -Os cannot miscompile out-of-line
    member-array accesses (the root cause of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
    [main.cpp]
2026-07-31 refactor: remove templates, class+constructor + Wire API in i2c.cpp
    - led.h: WbLed<BASE> template -> WbLed class with explicit WbLed(uint32_t base)
    - i2c.h: I2C<BASE> template -> I2C class with explicit I2C(uint32_t base);
    all MMIO methods kept inline (prevents GCC -Os out-of-line miscompile);
    Wire API declared, implemented in i2c.cpp
    - i2c.cpp: Wire API implementations (begin/beginTransmission/write/
    endTransmission/requestFrom/read/available/peek/flush)
    endTransmission calls inline Write() -- endTransmission confirmed working
    - main.cpp: I2C i2c0(I2C0_BASE) and WbLed led1(LED1_BASE) local in main()
    - u8g2_hal.cpp: static I2C s_i2c(I2C0_BASE) (constructor-based global)
    - Makefile: a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
    [main.cpp]
2026-07-31 fix: Wire API calls direct in loop — remove i2c_probe_wire helper
    [main.cpp]
2026-08-01 test: add memoryLab.cpp — toolchain/startup validation firmware
    Tests 14 categories of C++ memory layout and startup chain:
    A [0..4] .data/.sdata initialized globals (ROM→RAM copy)
    B [5..8] .bss/.sbss zero-init globals (BSS zeroing, including .sbss)
    C [9] .rodata constants (read from ROM)
    D [10] C++ global constructor via .init_array
    E [11,12] stack/local variables
    F [13] I2C class local scope (ctor + MMIO write, no crash)
    Firmware Makefile: 'make lab' builds build/lab.{hex,lst,map}
    - lab.map: shows section placement and symbol addresses
    - lab.lst: full disassembly with source (-g -S -l flags)
    - Links start.o + memoryLab.o + i2c.o (no u8g2)
    Root Makefile: 'make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
    [memoryLab.cpp]
2026-08-01 fix: resolve all 10 firmware quality issues
    P3 - link.ld: add . = ALIGN(4) before __data_end and __bss_end
    Ensures ROM->RAM copy and BSS-zero loops never miss trailing bytes
    when a section ends at a non-word-aligned address.
    P4 - i2c.h: add [[gnu::always_inline]] to all inline MMIO methods
    Prevents GCC -Os from emitting out-of-line .isra clones (e.g.
    PushCmd.isra.0 was present in u8g2_hal.o before this fix).
    Confirmed: no .isra symbols in u8g2_hal.o after rebuild.
    P1 - u8g2_hal: remove static I2C s_i2c(I2C0_BASE), use I2C* s_i2c_ptr
    + u8g2_hal_set_i2c(I2C* bus) setter
    Single I2C instance shared via main() — no conflicting Wire state.
    P2 - u8g2_hal: no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
    [main.cpp]
2026-08-01 fix: remove gp/sdata/sbss/ALIGN link.ld-start.S modifications
    Revert the template-era additions to link.ld and start.S that were
    added in d47c0f5 for the global Wire state members. Those modifications
    are not needed with the current constructor-based local I2C object.
    start.S: remove 'la gp, __global_pointer$' (.option norelax block).
    gp register confirmed unused in the binary (objdump shows zero
    gp-relative accesses). PicoRV32 resets gp to 0; no code uses it.
    link.ld: remove __global_pointer$, ALIGN(4) from .data and .bss.
    Keep *(.sdata*) and *(.sbss*) — needed for s_i2c_ptr in u8g2_hal.
    Without __global_pointer$ the linker no longer exports that symbol,
    matching the pre-temp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
2026-08-01 refactor: I2C as pure C static-inline functions — no class, no stack state
    Replace the I2C C++ class (constructor + Wire state on stack) with plain
    C static-inline functions that receive base address as a parameter.
    Key improvement: with I2C0_BASE as a compile-time #define constant, GCC
    folds it through all inlined call chains and emits direct 'lui + sw/lw'
    MMIO instructions — zero stack indirection, identical to the confirmed-
    working 9380572 architecture.
    Disassembly confirmed:
    lui a5, 0x10005 ← direct constant (not loaded from stack)
    sw a3, 24(a5) ← *(0x10005018) = prescale directly
    Changes:
    - i2c.h: I2C class → static inline i2c_init/write/read/probe/push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
    [main.cpp]
2026-08-01 fix: Makefile CXXFLAGS broken by blank line — u8g2_hal.h now found
    Blank line after continuation backslash in CXXFLAGS definition caused
    Make to stop parsing the variable after . All C++-specific flags
    (-std=c++17, -fno-exceptions, -fno-rtti, -I., -Ilib/u8g2_hal, ...) were
    silently dropped. Symptom: u8g2_hal.h not found when re-enabling u8g2.
    [main.cpp]
2026-08-01 fix: restore ALIGN(4) in .data and .bss sections of link.ld
    Without ALIGN(4) before __data_end/__bss_end, the word-copy and
    word-zero loops in start.S (which advance 4 bytes at a time using beq)
    overshoot the end address and loop forever when the section size is
    not a multiple of 4.
    Symptom: firmware hangs in _start before reaching main() — LEDs never
    blink even though the binary is correct. Root cause confirmed by symbol
    table: __bss_end was 0x10496 (not 4-aligned, 1174 = 0x496 bytes).
    After fix: __bss_end = 0x10498 (aligned), loop exits correctly.
2026-08-01 fix: u8g2_hal byte callback — STOP on last WRITE, clear NACK on START
    Two bugs that could cause u8g2_InitDisplay to hang/crash:
    1. Standalone STOP command: previous implementation pushed CMD_STOP
    alone after all WRITE commands. The confirmed-working i2c_write path
    always attaches STOP to the last WRITE byte (WRITE|STOP).
    Fix: hold the last byte in s_last_data/s_has_pending and flush it
    in END_TRANSFER with WRITE|STOP — identical to the i2c_write path.
    2. Stale NACK flag: BYTE_START_TRANSFER did not clear the NACK sticky
    bit, so a NACK from a previous transfer could spuriously terminate
    the next transfer in END_TRANSFER.
    Fix: clear NACK in START_TRANSFER.
2026-08-01 refactor: u8g2_hal byte callback — buffer+i2c_write approach
    Inspired by CH32V RISC-V example: u8g2 never sends more than 32 bytes
    per transfer. Accumulate into s_buf[], then call i2c_write() at
    END_TRANSFER — the EXACT same proven path used by i2c_probe().
    Previous approach (byte-by-byte FIFO push with s_has_pending) was
    complex and hard to verify. This approach reuses the confirmed-working
    i2c_write() which handles START + all bytes + WRITE|STOP correctly.
    [main.cpp]
2026-08-01 feat: add robust bare-metal i2c0 driver for wb_i2c
2026-08-01 Fix u8g2 struct, u8g2_SetI2CAddress and confirm i2c_write is ok
    [main.cpp]
2026-08-05 Get i2c master from Alex repo
    [revision_history.xlsx]
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2026-08-06 Debug I2C bring-up and add open-drain pin config
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2026-08-06 Updating write method (+ exterlib issue)
    [main.cpp]
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2026-08-07 Probe is now correct !
    [main.cpp]
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2026-08-08 Moving to i2c_master_wbs_16 - probe is ok, still a pull up resistor isue on my test breadboard
2026-08-10 Fix RAM issue driving me mad during last 10 days
    [main.cpp]
2026-08-10 Check (and fix) make flash feature
    [main.cpp]
2026-08-10 Fix SDRAM partial writes and boot self-tests
    [main.cpp, sdram.h]
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2026-08-11 Testing uart rx and refactoring to use uart_simple for wb_uart and wb_nodenet
2026-08-11 Fix NodeNet UART TX handshake and stabilize 10s heartbeat cadence
    [main.cpp]
2026-08-12 Potential fix for pull request finding
    Change Serial.h to serial.h in include (main.cpp)
    [main.cpp]
2026-08-13 Add stage0 bootloader and firmware image header packer
2026-08-13 Link app in SDRAM and add firmware-only flash update flow
2026-08-13 Finalize firmware-only flash flow with image verification and slot guards
2026-08-13 Add stage0 blink fault codes and boot robustness test flows
2026-08-13 Refresh README build docs after boot flow migration
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2026-08-16 Work in progress
    [pyvenv.cfg]
2026-08-16 Hardware and boot loader sdram test ok - jump not correct
    [boot_stage0.cpp]
2026-08-17 Hardware and boot loader sdram test ok - jump correct but picorv32 can't execute commands in sdram. Trying LiteDRAMWishbone2Native interface
    [boot_stage0.cpp, main.cpp]
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2026-08-17 Potential fix for pull request finding
    Ok
    [boot_stage0.cpp]
2026-08-17 First code review
    [pyvenv.cfg]
2026-08-18 writeSingleCoil test : cyclic output toggle on Waveshare IO8 device is ok
2026-08-18 readHoldingRegisters reading version number on waveshare 8IO device. Test OK
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2026-08-19 Fix firmware startup constructor handoff
    Restore reliable firmware boot by fixing the RISC-V startup .init_array walk to keep iterator state in callee-saved registers across constructor calls. This avoids pre-main reboots once ArduinoJson/global constructors are present.
    Also keep the validated ArduinoJson freestanding integration and bootloader/flash diagnostics used during bring-up.
    [boot_stage0.cpp, main.cpp, sdram.h]
2026-08-19 Enable SDRAM JSON allocator smoke test
    Use the SDRAM-backed ArduinoJson allocator in the firmware smoke test, report allocator init failures on the OLED, and remove the temporary post-JSON debug hold after hardware validation.
    [main.cpp]
2026-08-19 Fix LiteDRAM cold boot bring-up and diagnostics
    [boot_stage0.cpp]
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2026-08-20 Fix PR review issues for SDRAM allocator and LiteDRAM enable
    [sdram.h]
2026-08-20 Fix NodeNet IRQ review issues
    [main.cpp]
2026-08-26 Add PLC ABI point resolve result
    [main.cpp, plc_runtime_abi.h]
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2026-08-27 Add PLC object readback and slot var browse fixes
    [main.cpp, plc_linker_v1.h, plc_loader_v1.h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]
2026-08-27 Fix PLC slot persistence and SDRAM layout
    [sdram.h]
2026-08-28 Checkpoint PLC persistence and UI fixes
    [main.cpp, plc_loader_v1.h]
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2026-08-30 Finalize PLC stage 3 and slot variable visibility
2026-08-30 Add PLC stage 4 compare and select ops
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2026-08-31 Add PLC VM TON timers and harden upload flow
2026-09-01 Add stage 8 timers and harden deferred PLC auto-load
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2026-09-01 Preserve PLC slot status points and surface upload failures
2026-09-02 Skip legacy mirror sync for shared PLC types
    [plc_runtime_abi.h]
2026-09-02 Fix PLC shared state SDRAM base
    [wb_plc.sv]
2026-09-02 Skip legacy descriptor status read for shared PLC types
    [wb_plc.sv]
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2026-09-05 Stage 11 firmware cleanup and Stage 12 notes
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2026-09-07 Add ESP32 boot UI and SPI mailbox updates
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2026-09-08 Add ESP32 plcLink sync and runtime UI updates
    [partitions.csv]
2026-09-09 Refine ESP32 web flow and ignore generated assets
2026-09-09 Optimize ESP32 app auth and websocket point updates
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2026-09-09 Avoid blocking on spi_link state reads
    [spi_link.cpp]
2026-09-09 Fix websocket auth after HTTP upgrade
    [web_server.cpp]
2026-09-10 Stabilize plcLink snapshot and runtime update flow
    [main.cpp, spi_link.cpp, tb_wb_plc_dirty_bool.sv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]
